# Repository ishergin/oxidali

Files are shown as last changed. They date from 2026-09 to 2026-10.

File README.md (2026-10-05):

# Oxidali

**English** | [Русский](README.RU.md)




Oxidali is a DALI-2 lighting controller: Rust firmware for the Waveshare ESP32-P4-ETH, a 3D-printed
DIN-rail enclosure, and the tooling to build, simulate and test it. The controller
drives one DALI line through its own interrupt-driven PHY. It keeps a registry of
control gear and input devices, and serves a REST and WebSocket API, an embedded web UI
and a Home Assistant bridge. Scheduling covers human-centric lighting (HCL) and a small
rules engine. Two controllers can share one line as an active/standby pair.

Inside the code the project keeps its working name, `dali2rust`: in crate names, the
`DALI2RUST_*` variables and the Home Assistant manufacturer string.

<p align="center">
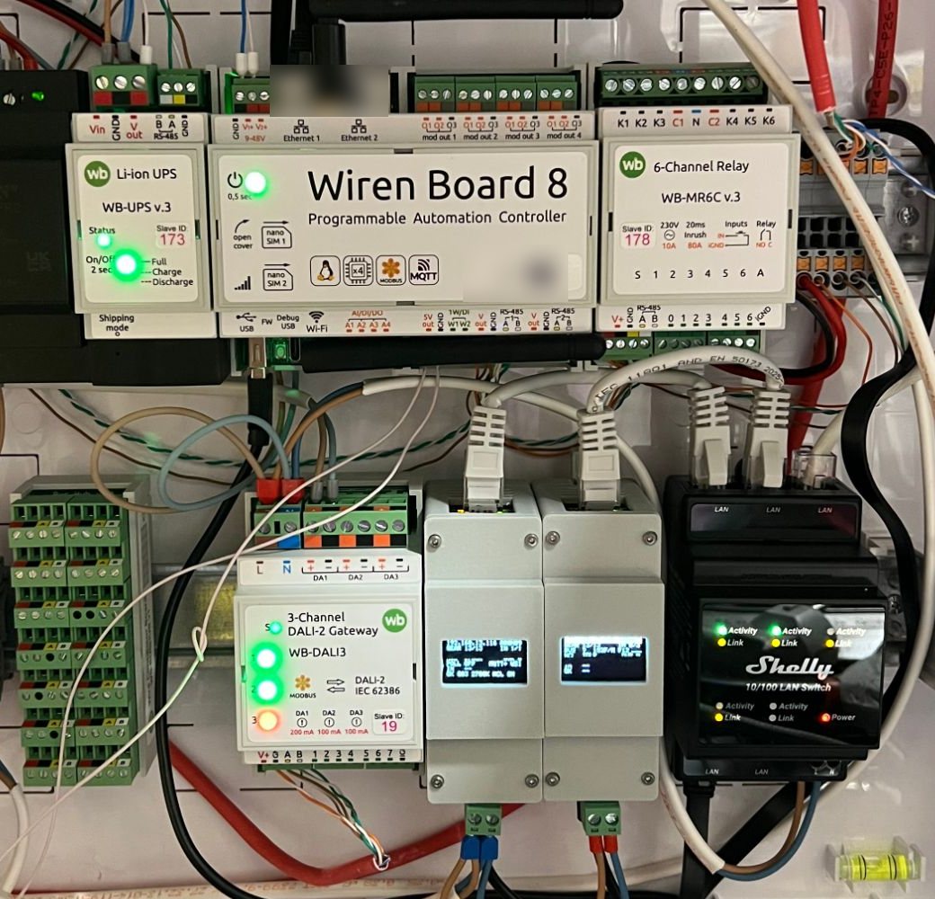
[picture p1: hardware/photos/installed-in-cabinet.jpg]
Two Oxidali controllers, an active/standby pair, on a DIN rail in a distribution cabinet next to a DALI gateway, a Wiren Board controller and a LAN switch
  
  &nbsp;
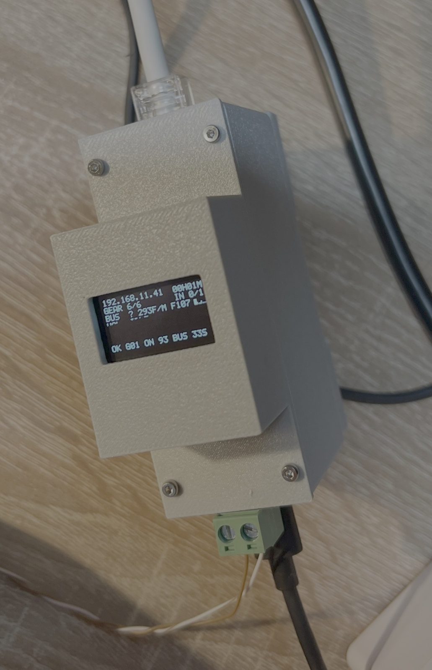
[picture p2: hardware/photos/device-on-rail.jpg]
Close-up of the enclosure with the OLED status screen
  
</p>

## Features

**DALI line**
- Its own PHY: a GPTimer interrupt bit-bangs the line with Manchester coding and
  collision detection. It runs at CLIC level 5 from IRAM only.
- Multi-master aware. The controller shares the line with foreign masters: it
  arbitrates, retries after a collision and treats a contended answer as routine. A
  sniffer decodes foreign frames and keeps the registry in step with them.
- IEC 62386-101 transactions and frame priorities: background reads never delay an
  operator's command.
- Control gear per IEC 62386-102: DT6 LED gear, and DT8 colour gear (colour temperature
  and RGBWAF). Memory bank 0 and the DiiA banks of Parts 251–253 (luminaire data,
  energy, diagnostics) are read.
- Input devices per IEC 62386-103: push buttons (301), absolute inputs (302),
  occupancy sensors (303), light sensors (304) and panel indicators (332). The
  controller receives and types their 24-bit events.
- Commissioning: three scan modes, random addressing, `IDENTIFY DEVICE`, readdressing
  and gear replacement.

**Model and integrations**
- A persistent registry of physical devices, virtual lamps, groups and scenes. Group
  and scene changes are applied as tracked operations.
- A REST API (`/api/v1/*`) and a WebSocket push channel (`/api/v1/ws`). A long job
  answers `202` with an operation id that the client can poll.
- An embedded web UI (Preact + TypeScript) served from flash. Its screens include the
  dashboard, lamps, devices, input devices, groups, scenes, HCL, rules, a bus console,
  a sniffer, logs, operations, statistics, diagnostics, firmware and settings.
- Home Assistant over MQTT discovery: lights, groups, a scene selector and input-device
  events.
- HCL schedules: colour-temperature and level curves, sunrise and sunset, SNTP time and
  time zones, and manual override tracking.
- A rules engine with its own small language. Rules react to input-device events, time
  of day and the sun, lamp, group and scene changes, timers, HTTP calls and MQTT
  messages; they are compiled on the device and can be dry-run.
- Active/standby redundancy. The two units arbitrate roles on the DALI line (DiiA Part
  351) and replicate configuration over HTTP.
- Firmware updates over Ethernet: the controller pulls the image from a URL and rolls
  back if the new image does not prove itself healthy.
- A status screen on an SSD1306 OLED, and runtime counters (DALI, bus, network,
  memory, MQTT, WebSocket) at `/api/v1/stats`.

**Engineering**
- The whole product stack runs on a desktop against a simulated DALI line, through the
  same composition code as the firmware.
- There are unit tests, crate integration tests on the real bus path, and a black-box
  BDD suite of more than 500 cucumber scenarios that drive the host stack over HTTP and
  WebSocket.
- A hardware-in-the-loop toolkit (`tools/hil`) validates the firmware on real boards,
  including optical tests in which a calibrated USB camera checks what each lamp really
  shows ([below](#hardware-in-the-loop-and-bench-instruments)).

## Web UI

The controller serves this UI from its flash. The screenshots come from the host dev
server running the same stack on a simulated line.

<table>
  <tr>
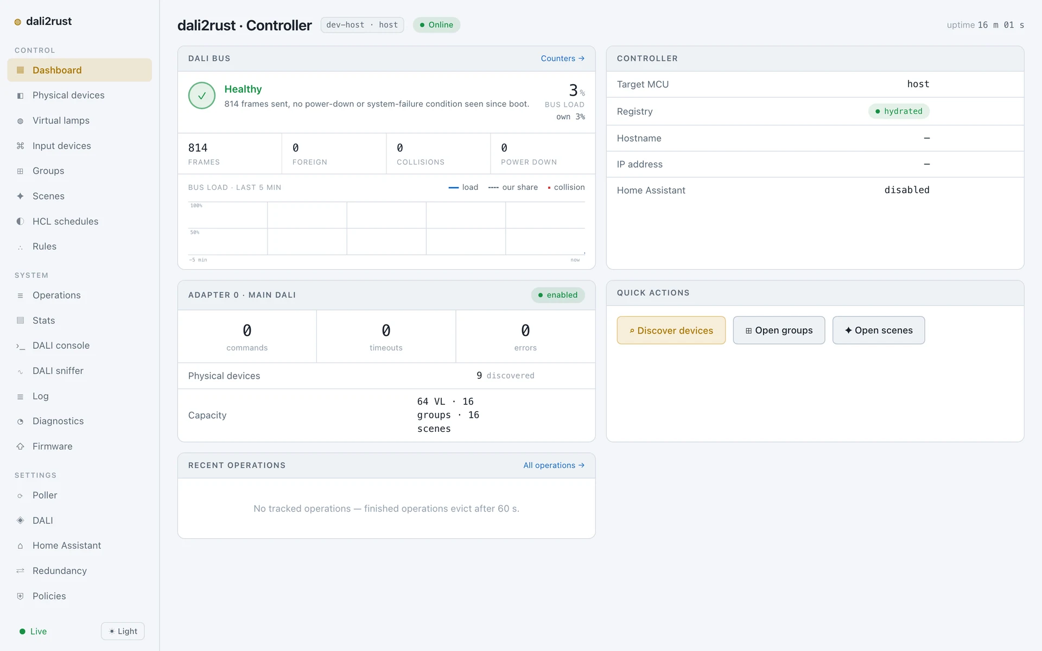
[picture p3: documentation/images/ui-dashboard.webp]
Dashboard with DALI bus health, bus load and adapter counters
    <td width="50%"></td>
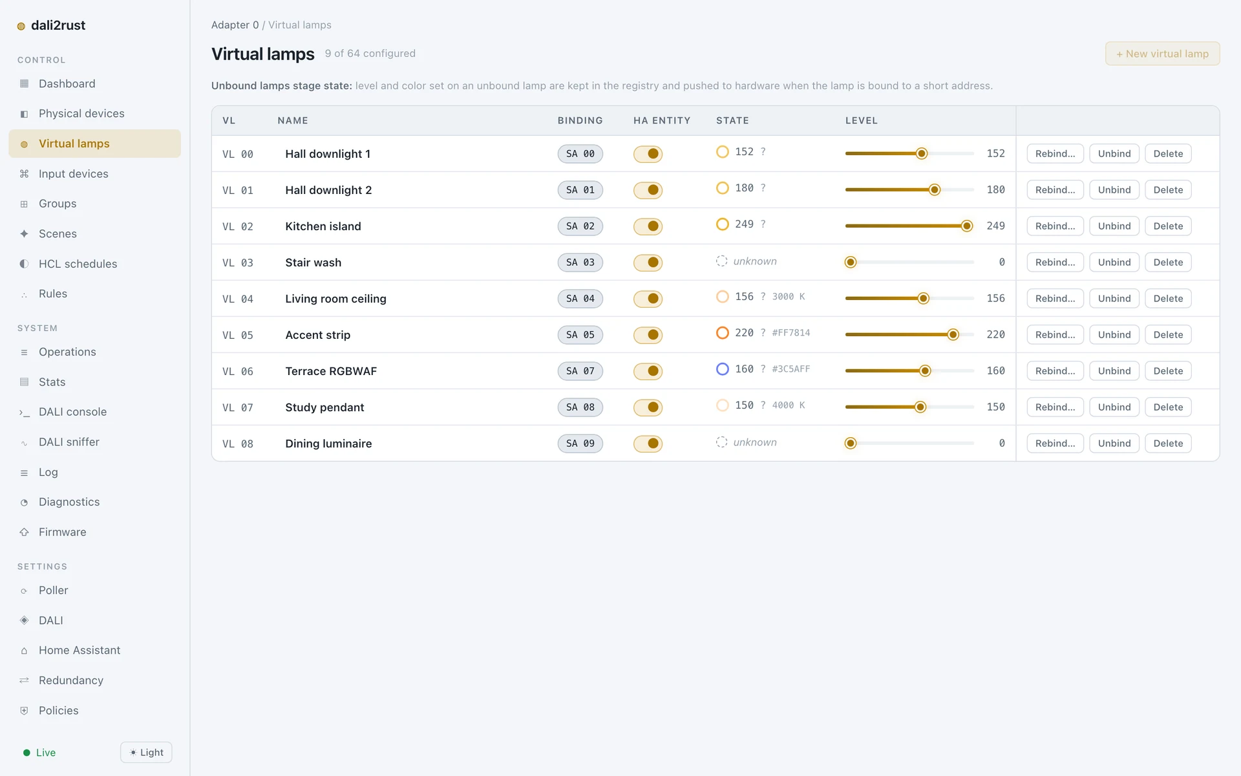
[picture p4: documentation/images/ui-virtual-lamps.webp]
Virtual lamps with live state, level and colour
    <td width="50%"></td>
  </tr>
  <tr>
    <td align="center">Dashboard: bus health, load and counters</td>
    <td align="center">Virtual lamps: live state, level and colour</td>
  </tr>
  <tr>
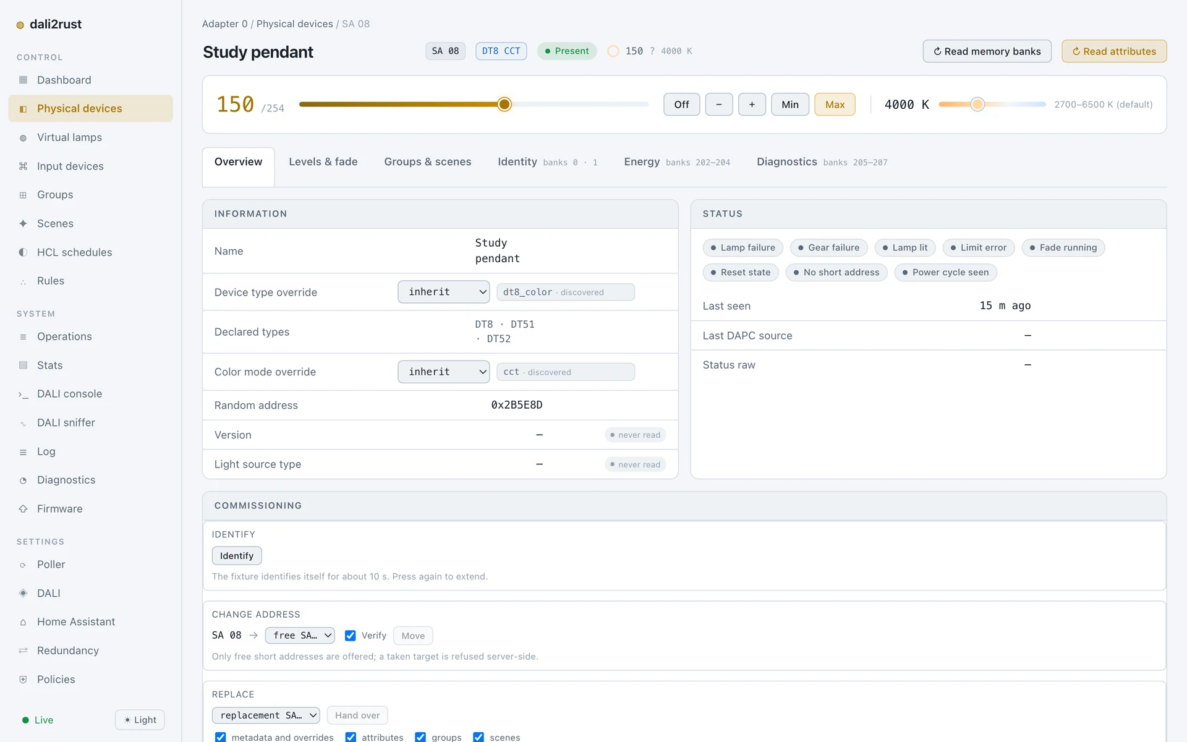
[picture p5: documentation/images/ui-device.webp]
Device card of a DT8 colour-temperature gear
    <td width="50%"></td>
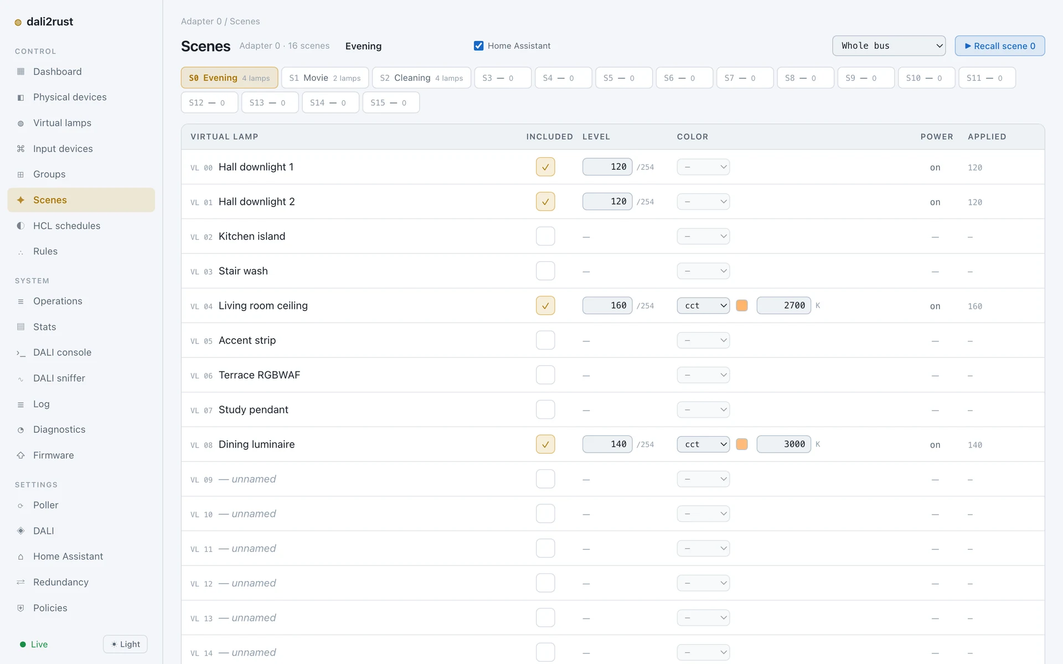
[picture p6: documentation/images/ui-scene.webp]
Scene matrix with per-lamp level and colour temperature
    <td width="50%"></td>
  </tr>
  <tr>
    <td align="center">A device card: DT8 colour temperature, banks, commissioning</td>
    <td align="center">A scene: per-lamp level and colour, desired against applied</td>
  </tr>
  <tr>
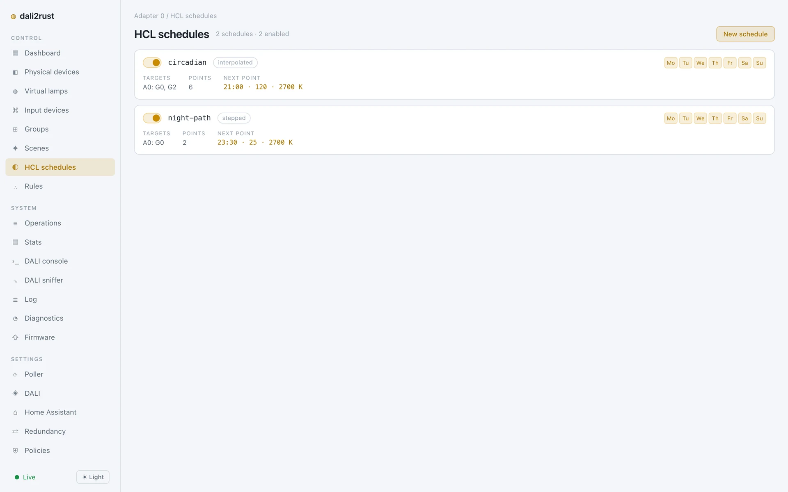
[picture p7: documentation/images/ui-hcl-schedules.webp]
List of HCL schedules with their targets and next point
    <td width="50%"></td>
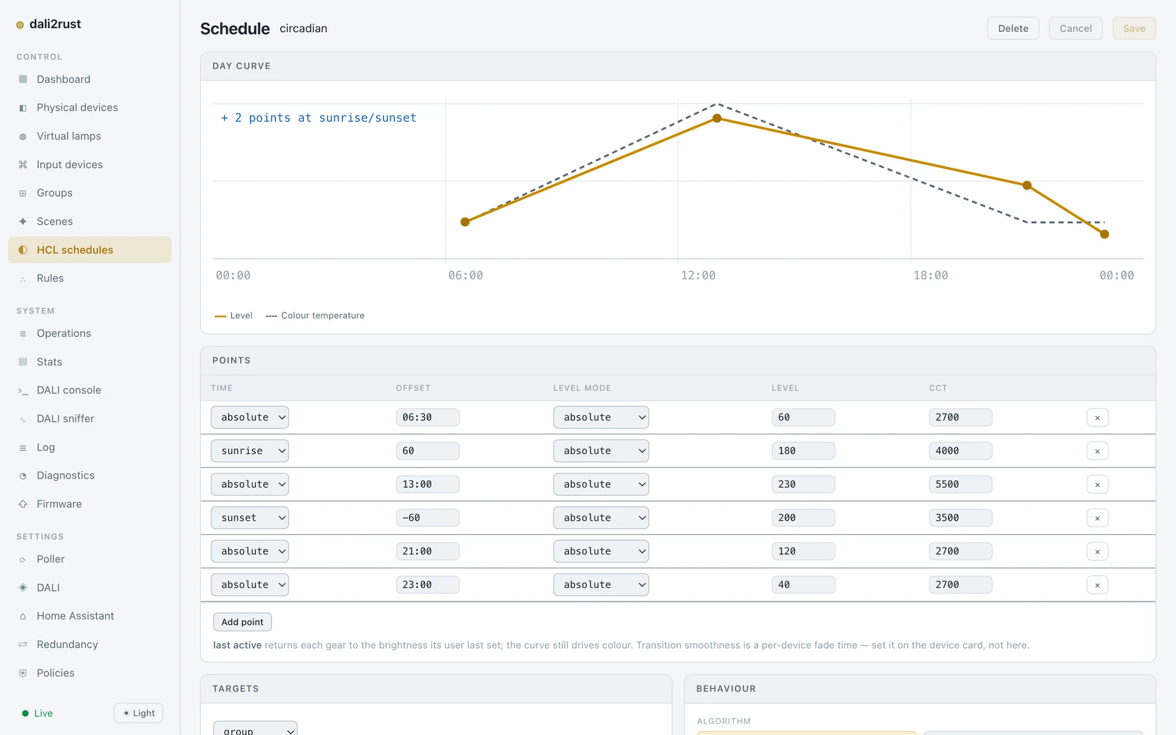
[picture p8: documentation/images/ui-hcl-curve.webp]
HCL day curve of level and colour temperature with its points
    <td width="50%"></td>
  </tr>
  <tr>
    <td align="center">HCL schedules</td>
    <td align="center">An HCL day curve anchored to sunrise and sunset</td>
  </tr>
</table>

## Hardware

| Part | Role |
| --- | --- |
| [Waveshare ESP32-P4-ETH](https://www.waveshare.com/esp32-p4-eth.htm) | Main board: dual-core RISC-V ESP32-P4, 32 MB PSRAM, 32 MB flash, 100 Mbit Ethernet (no radio) |
| Waveshare PoE Module (B) | Optional: powers the board from the Ethernet cable |
| Waveshare Pico-DALI2 | DALI transceiver on the board's Pico-format 2×20 header |
| SSD1306 0.96″ 128×64 I²C OLED | Status screen |
| 2-pole 5.08 mm pluggable terminal block (2EDGV header + 2EDGK plug) | External DALI connector |
| 3D-printed enclosure | Five parts on a TS35 DIN rail |

The line also needs a DALI bus power supply.

| Signal | ESP32-P4 GPIO | Header |
| --- | --- | --- |
| DALI TX (the Pico-DALI2 inverts it) | 14 | pin 9 / Pico GP6 |
| DALI RX | 17 | pin 5 / Pico GP3 |
| DALI high-voltage receive tap (unused, never driven) | 18 | pin 4 / Pico GP2 |
| OLED SDA | 33 | — |
| OLED SCL | 32 | — |

The pin map lives in
[`crates/dali2rust-bsp/src/esp32p4/pins.rs`](crates/dali2rust-bsp/src/esp32p4/pins.rs).

### Enclosure

- FreeCAD model: [`hardware/enclosure/dali2rust-case.FCStd`](hardware/enclosure/dali2rust-case.FCStd),
  driven by a `Params` spreadsheet.
- STEP, STL and 3MF files for each part and for the assembly are in
  [`hardware/enclosure/export/`](hardware/enclosure/export/).
- The body is printed in ABS-GF. The part that carries the DIN-rail catch spring is
  printed in unfilled ABS or ASA.

<table>
  <tr>
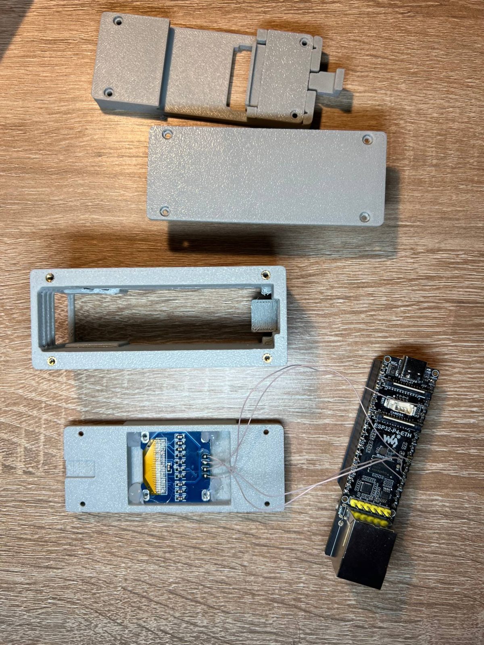
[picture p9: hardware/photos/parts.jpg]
Printed enclosure parts, the OLED in the front cover and the ESP32-P4-ETH
    <td></td>
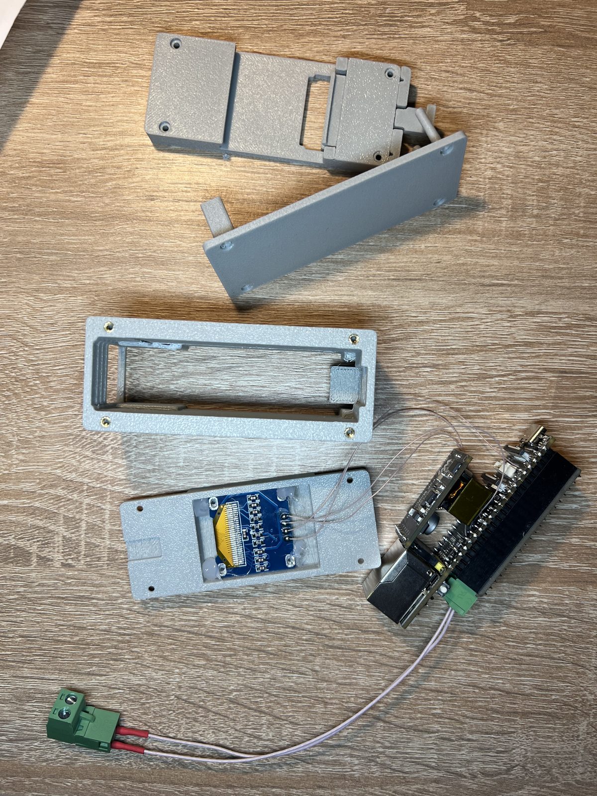
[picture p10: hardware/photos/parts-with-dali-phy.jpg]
Enclosure parts with the Pico-DALI2 mounted under the main board and the DALI plug
    <td></td>
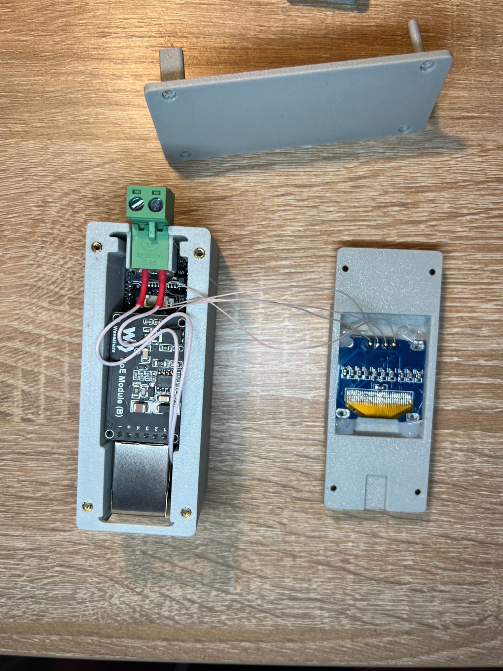
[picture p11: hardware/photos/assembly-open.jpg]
The board stack seated in the body, with the PoE module and the DALI terminal block
    <td></td>
  </tr>
  <tr>
    <td align="center">Printed parts and the main board</td>
    <td align="center">With the Pico-DALI2 and the DALI plug</td>
    <td align="center">Board stack in the body</td>
  </tr>
</table>

## Architecture

### The system

<p align="center">
  System overview: clients on the local network, the Oxidali controller, and the DALI line with gear, input devices, other masters and an optional standby
</p>

### Inside the controller: components and what they do

Everything that wants to change the world publishes a typed command on an in-memory
bus. Exactly one worker owns each command kind: only `DaliWorker` touches the wire, and
only the registry worker writes the registry.

<p align="center">
  Firmware components: ingress modules publish typed commands on a bounded bus; workers own the DALI wire, the registry, operations, state fan-out and the display; the PHY interrupt drives the Pico-DALI2
</p>

### One request, end to end

```mermaid
sequenceDiagram
  autonumber
  participant C as Client
  participant H as HTTP handler
  participant B as Bus
  participant W as DaliWorker
  participant L as DALI line
  participant F as State-fanout projector
  participant R as Registry worker
  participant O as WebSocket / MQTT

  C->>H: PUT /api/v1/adapters/{adapter_id}/virtual-lamps/{lamp_id}/target-state
  H->>H: validate, build a typed command
  H->>B: publish (never blocks)
  B->>W: route to the owner
  W->>L: forward frames inside a transaction
  L-->>W: answer, silence or collision (retried)
  W->>B: applied event + confirmation
  B-->>H: confirmation into the request's slot
  H-->>C: 200 (503 if refused, 504 on timeout)
  B->>F: applied event
  F->>B: runtime update command
  B->>R: commit (the only writer)
  R->>B: runtime-state-changed event
  B->>O: fan-out
  O-->>C: WebSocket frame, MQTT state
```

On the host, the same composition runs over a simulated transport: the BDD suite over
`MockDaliTransport` with scripted answers, the dev server below over `SimDaliTransport`,
a model of real gear. The architecture documents start at
[`documentation/architecture/01-overview.md`](documentation/architecture/01-overview.md),
and the decisions behind them are the [ADRs](documentation/architecture/decisions/README.md).

The system and component drawings are Excalidraw SVGs with the scene embedded: open one at
[excalidraw.com](https://excalidraw.com) to edit it.

## Quick start

macOS on Apple silicon is the tested host. The host triple `aarch64-apple-darwin` is
written into the `justfile` (`default_host`) and the cargo aliases. On another host,
pass `default_host=<triple>` to `just` and put your triple in the `cargo run` commands;
the `cargo bdd` alias keeps the Apple one, so run the suite with `just bdd`.

### Prerequisites

```bash
git clone https://github.com/ishergin/oxidali.git && cd oxidali
# Rust itself: https://rustup.rs
rustup toolchain install    # the nightly and components rust-toolchain.toml pins, host builds included
cargo install ldproxy espflash --locked
brew install just    # or: cargo install just --locked
```

ESP-IDF v5.5.3 and its tools, the libclang bindgen uses among them, are downloaded by
the first firmware build into `.embuild/` and need `git` and Python 3. Node.js 22 is
needed to rebuild the web UI and by the merge gates (`just verify`, `just ci`); the built
UI is committed.

### 1. Run it without hardware

The composed product stack on a simulated line (nine DT6 and DT8 gear and one
unaddressed unit), serving the committed web UI at http://127.0.0.1:8080/:

```bash
DALI2RUST_WEB_DIST_GZ=crates/dali2rust-firmware/assets/web \
  cargo run --target aarch64-apple-darwin -p dali2rust-adapters --example host_dev_server
```

```bash
curl http://127.0.0.1:8080/api/v1/health
```

The server's stdin is a console that plays a foreign master and a wall panel: `press`,
`release`, `foreign`, `occupancy`. Set `DALI2RUST_DEV_SERVER_FLEET=bench` for a full
64-address line. To work on the UI with hot reload, see
[`web/app/README.md`](web/app/README.md):

```bash
cd web/app && npm ci && npm run dev    # http://localhost:5173, proxies /api to :8080
```

### 2. Run the tests

```bash
just check     # type-check every host crate, test targets included
just test      # unit and integration tests
just bdd       # the black-box BDD suite
just ci        # everything a change must pass: clippy, tests, BDD, gates, ESP type-checks
```

`just verify` and `just ci` type-check and test the web UI too, so run
`(cd web/app && npm ci)` once before them.

### 3. Build and flash the firmware

```bash
cargo fw       # build the image for riscv32imafc-esp-espidf
cargo flash    # build, write bootloader + partition table + app over USB, open the monitor
```

Connect the board's USB-C port first. `cargo flash` runs `espflash` with
`partitions-p4.csv`. On the first boot the controller takes an address over DHCP and
shows it on the OLED; open `http://<address>/`. Later updates can go over the network
(Firmware screen, or `POST /api/v1/firmware/updates`).

## Hardware-in-the-loop and bench instruments

[`tools/hil`](tools/hil/README.md) is a pytest suite that drives a real controller on a
real DALI line and checks every effect through an oracle that does not trust the
firmware's own report:

- the controller's REST and WebSocket API and its serial console;
- a second DALI master on the same line (for example a Wiren Board WB-MDALI3) as an
  independent sniffer and a foreign master;
- **optical tests**: a USB camera looks at the lamps, a calibration finds each lamp in
  the frame, and the tests check that every lamp switches on and off, that brightness
  rises strictly with the level, that RGB primaries and 2700 K / 6500 K come out as
  commanded, and that a group recall, a scene, an HCL schedule or a Home Assistant
  command reaches the light itself;
- the second controller of an active/standby pair.

Each tier needs only its own instruments, and the runbook says how to run without each
one. Every session snapshots the controller's configuration and the light and restores
them afterwards. The runbook, with what a bench needs, the configuration and
the first run, is [`tools/hil/README.md`](tools/hil/README.md).

Two more instruments sit beside the toolkit:

- [`tools/dali-gear-sim`](tools/dali-gear-sim/README.md), the **gear emulator**: the
  redundancy pair's second ESP32-P4, borrowed for a session, answers on the shared line
  as a fleet of virtual control gear (DT6, DT8 Tc, DT8 RGB+Tc) while drawing a single
  bus load. Tests drive gear that is nobody's light: target states, groups, scenes, HCL,
  the commissioning search, a poller sweep and a registry near its ceiling. Every boot
  starts with no fleet until the toolkit names the short addresses the real lamps hold,
  and nothing is stored. It runs the shared `dali2rust-gear-model` crate, the same model
  as the host simulator, and the HIL toolkit drives it over its serial console.
- [`tools/dali-arbiter`](tools/dali-arbiter/README.md), the **wire witness**, targets an
  ESP32-C6 with a Pico-DALI2 and is not ported: a receive-only board that records raw
  pulse widths with the RMT peripheral. The firmware cannot judge its own transmit
  timing, so this board compares our frames with a reference master's frames in the
  same capture; `hil/arbiter.py` decodes and scores the captures.

## Roadmap

- **Cluster.** Several controllers act as one system: permitted group commands and
  scene recalls are forwarded between controllers over MQTT, with loop suppression
  ([design](documentation/product-design/runtime-modules/cluster/README.md), in Russian).
- **A Linux service with a Pico DALI endpoint.** The same stack as a Linux daemon (it
  already runs on a host), attached over USB or Ethernet to a DALI coprocessor: an
  RP2350 (Pico 2) with PIO on the Pico-DALI2. The coprocessor keeps bit timing,
  settling windows, collision detection and frame capture; the host keeps the
  application. It also allows a host-based standby, such as a wall panel
  ([ADR-019](documentation/architecture/decisions/ADR-019-standby-dali-endpoint.md)).
- **A DALI-2 push-button.** A bus-powered wall-box input device with two to four
  buttons, RGB feedback per button, NFC tap-to-bind and BLE updates, speaking Parts 103,
  301 and 332; the schematic is being drawn.

## Repository layout

| Path | What it holds |
| --- | --- |
| `crates/` | The Cargo workspace; `dali2rust-firmware` is the only production composition root |
| `tests/dali2rust-bdd/` | The cucumber BDD suite, black-box over HTTP against the composed host stack |
| `web/app/` | The web UI embedded in the firmware |
| `web/design-system/` | A design card for every screen and component |
| `hardware/enclosure/` | The DIN-rail enclosure: the FreeCAD model and its exports |
| `tools/hil/` | The hardware-in-the-loop test toolkit |
| `tools/dali-gear-sim/`, `tools/dali-arbiter/` | The gear emulator (the pair's second ESP32-P4) and the wire witness (ESP32-C6, not ported) |
| `scripts/` | The merge-gate scripts `just verify` runs and their budgets, plus build, release and measurement helpers |
| `documentation/` | Architecture, decision records and the product design |

## Documentation

- [`documentation/README.md`](documentation/README.md) is the map: the as-built
  architecture, the ADRs, and the product design (REST API, bus contracts, runtime
  modules, web UI). The product-design package is written in Russian.
- [`CLAUDE.md`](CLAUDE.md) holds the rules for contributors and coding agents:
  architecture boundaries, threading, testing, contracts and merge gates.
- [`tools/hil/README.md`](tools/hil/README.md) is the bench runbook.

The IEC 62386 standards and DiiA specifications are not included. They are sold by the
IEC and the DALI Alliance.

## Contributing

Changes land through pull requests; how to prepare one, including a web UI change, is in
[`CONTRIBUTING.md`](CONTRIBUTING.md). New behaviour starts with a failing BDD scenario,
and `just ci` must be green before a change lands. The rules are in
[`CLAUDE.md`](CLAUDE.md); the recipes for adding a command, an endpoint or a worker are
in [`11-extension-recipes.md`](documentation/architecture/11-extension-recipes.md).

## License

The software is licensed under either of

- Apache License, Version 2.0 ([`LICENSE-APACHE`](LICENSE-APACHE)), or
- MIT license ([`LICENSE-MIT`](LICENSE-MIT)),

at your option. The hardware design files in [`hardware/`](hardware/) (the enclosure
model and its exports) are licensed
under the CERN Open Hardware Licence Version 2 – Permissive
([`hardware/LICENSE`](hardware/LICENSE)).

Unless you explicitly state otherwise, any contribution intentionally submitted for
inclusion in the work by you, as defined in the Apache-2.0 license, shall be dual
licensed as above, without any additional terms or conditions.

The product-name table in `web/app/public/dali-products.json` ships empty: the DiiA
product database is not redistributed here.

DALI and DALI-2 are trademarks of the DALI Alliance. This project is not affiliated with
the DALI Alliance, and the firmware is not DALI-2 certified.

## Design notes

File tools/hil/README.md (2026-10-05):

# HIL toolkit

pytest-based hardware-in-the-loop tests of the firmware on a real controller and a real
DALI line. The oracles are the controller's HTTP/WebSocket API and serial console, a
second DALI master as an independent bus sniffer and foreign master (for example a Wiren
Board WB-MDALI3 under `wb-mqtt-dali` on `python3-dali`, source in the board's
`/usr/lib/python3/dist-packages/dali/`), and, when one is attached, a USB camera.

Scope: what a bench needs, setting up, running and reading the suite. Strategy, the
coverage map and the watchlist: [STRATEGY.md](STRATEGY.md) (Russian); build knobs and the
version string: [10](../../documentation/architecture/10-build-release-and-tooling.md).

## What a bench needs

| Instrument | Enables | Without it |
| --- | --- | --- |
| A controller running this firmware, reachable over HTTP (`HIL_BASE`) | every tier | nothing runs |
| Its serial console, on this host's USB or behind a serial bridge on another host | `serial`, reboot evidence, `hil monitor`, `hil flash` | `hil preflight` reports it; `serial` tests skip |
| A DALI line with bus power and at least one lamp the suite may drive | every test that changes the light | `HIL_LAMPS_READ_ONLY=1` keeps the light untouched |
| A UVC camera on a fixed mount with the lamps in view | `optical` ([Optical tests](#optical-tests)) | `--no-camera` turns optical tests into skips |
| A second DALI master reachable over ssh and MQTT (WB-MDALI3 on a Wiren Board) | `sniffer`, `foreign`, and `ha_bridge` through its broker | the `sniffer` and `foreign` fixtures skip; deselect `ha_bridge` |
| A second controller on the same line (`HIL_PEER_BASE`) | `redundancy` | those tests are not collected |

macOS is the tested host: camera discovery uses ffmpeg's AVFoundation input, `setup.sh`
builds `uvc-util` with the macOS frameworks, the frame server runs in Terminal. The rest is
Python 3.9+ with the packages of `pyproject.toml` (`setup.sh` installs them) and espflash,
which makes `hil flash`'s images.

## Configuration

Variables are read from the environment when a command starts. `bench.env` (from
`bench.env.example`) holds only the firmware knobs `hil flash` enforces. **The defaults name one particular bench.** Set at
least `HIL_BASE`, the serial variables and the three short-address sets before the first
run: every pytest session that collects a bench test reaches `HIL_BASE`, and
`bench_baseline` suspends that controller's poller for the session; a run that drives
lamps also suspends its HCL schedules (so does a virtual-gear run) and sets its time zone
to `HIL_BENCH_TZ`, a run that drives none leaves both alone. A session whose every test is
[hardware-free](#writing-a-scenario) touches no network and no serial port.

| Variable | Meaning | Default |
| --- | --- | --- |
| `HIL_BASE` | the controller's URL | a reference bench's controller |
| `HIL_SERIAL_REMOTE` | `user@host:/dev/…` of the controller's UART behind a [serial bridge](#serial-ports); empty means this host's USB | a reference bench's Wiren Board |
| `HIL_SERIAL_PORT` | the local serial device when `HIL_SERIAL_REMOTE` is empty | found by scanning |
| `HIL_SERIAL_BAUD`, `HIL_FLASH_BAUD`, `HIL_SERIAL_BRIDGE_PORT` | console baud, esptool baud, the bridge's local port | `115200`, `1500000`, `4444` |
| `HIL_LAMP_SHORTS` | short addresses a test may drive or write (`0,2,3`, `0-3`); the client refuses the rest ([lamp guard](#the-installation-is-production)); empty allows none | empty: the reference bench has no lamp a test may drive |
| `HIL_GEAR_SHORTS` | gear the read tiers target; empty means every gear in the registry | empty |
| `HIL_OPTICAL_SHORTS` | lamps in the camera's view, calibrated and measured; always narrowed to `HIL_LAMP_SHORTS` | `HIL_LAMP_SHORTS` |
| `HIL_LAMPS_READ_ONLY` | on: report the light, never drive it, and the client refuses every visible action; `0` with lamps in `HIL_LAMP_SHORTS` is a run with the owner's go-ahead | on |
| `HIL_NO_CAMERA=1` (`--no-camera`) | optical tests skip instead of failing | off |
| `HIL_CAMERA_NAME`, `HIL_CAMERA_ID` | which camera to open | `USB Camera` |
| `HIL_SKIP_CALIBRATION=1` (`--skip-calibration`), `HIL_CALIBRATION_TTL_S` | reuse the saved calibration; how old it may be | recalibrate; `900` s |
| `HIL_LAMP_ROSTER=registry` | take the lamp roster from the registry's bound virtual lamps | the calibration |
| `HIL_WB_SSH`, `HIL_WB_DEVICE`, `HIL_WB_BUS` | the sniffer host over ssh, its DALI device and bus | a reference bench's Wiren Board |
| `HIL_MQTT_BROKER_HOST`, `HIL_MQTT_BROKER_PORT` | the broker the `ha_bridge` tier uses | a reference bench's Wiren Board, `1883` |
| `HIL_PEER_BASE`, `HIL_PEER_SERIAL_PORT`, `HIL_PEER_SERIAL_REMOTE`, `HIL_PEER_SERIAL_BRIDGE_PORT` | the pair's [second controller](#the-second-controller-hil---peer) | unset, unset, a reference bench's Wiren Board, `4446` |
| `HIL_ALLOW_DESTRUCTIVE=1`, `HIL_POWER_CUT=1`, `HIL_BUS_SHORT=1` | allow the destructive and the person-at-the-rig tests | off |
| `HIL_STATE_GUARD=0` | turn the [save and restore](#save-and-restore) guard off | on |
| `HIL_BENCH_TZ` | the time zone `bench_baseline` holds the controller in during a run that drives lamps | a reference bench's zone |
| `HIL_VIRTUAL_GEAR=1` | run the [virtual-gear](#virtual-gear) tier on the gear the peer emulates | off |
| `HIL_VIRTUAL_PARK` | the emulated park's shape: DT6, DT8 Tc and DT8 RGB+Tc gear, built in that order on the first free addresses above the reserve | `4,4,4` |
| `HIL_OWNER_SHORTS` | live lamps a scan cannot see (unpowered), added to the virtual-gear reserve | empty |
| `HIL_ALLOW_VIRTUAL_COMMISSIONING=1` | let the virtual-gear tier commission emulated gear (a go-ahead per run) | off |
| `HIL_ALLOW_RULE_COMMITS=1` | select the tests that commit the rules document (`rules_guard`; a go-ahead per run, STRATEGY §4) | off |
| `HIL_ADAPTER`, `HIL_BOARD`, `HIL_RUN_DIR` | the DALI adapter id, the board, the artifact directory | `0`, `esp32p4`, `runs/current` |

## First run

```bash
tools/hil/setup.sh                                   # .venv, the hil package, uvc-util
cp tools/hil/bench.env.example tools/hil/bench.env   # firmware knobs `hil flash` enforces
cd tools/hil
export HIL_BASE=http://<controller> HIL_SERIAL_REMOTE= HIL_SERIAL_PORT=<device>
export HIL_LAMP_SHORTS=<lamps> HIL_GEAR_SHORTS=<gear> HIL_OPTICAL_SHORTS=<lamps in view>
.venv/bin/hil preflight                              # read-only readiness check
.venv/bin/python3 -m pytest -m smoke --no-camera     # the instruments themselves
.venv/bin/python3 -m pytest --no-camera \
  -m "not destructive and not slow and not sniffer and not foreign and not ha_bridge and not redundancy"
```

Drop `--no-camera` and the markers of instruments the bench has. The toolkit's unit tests
need no hardware; `HIL_BASE` on a closed port keeps a regressed hook off any bench:

```bash
HIL_BASE=http://127.0.0.1:9 HIL_SERIAL_REMOTE= HIL_NO_CAMERA=1 \
  .venv/bin/python3 -m pytest tests/*_unit.py                                           # tools/hil
```

## The installation is production

The suite runs on production lighting ([STRATEGY.md](STRATEGY.md) §2) under the standing
rules of STRATEGY §4. `HIL_LAMP_SHORTS` names the lamps a test may drive; set
`HIL_GEAR_SHORTS` on every run — empty, the default, means every gear in the registry.

The lamp guard (`hil/lamp_guard.py`) enforces `HIL_LAMP_SHORTS` and
`HIL_LAMPS_READ_ONLY`, whatever a test or a script selects. Every request
`Client` sends and every frame of the WB foreign master passes it first, and a refusal
raises `LampNotAllowed`, naming its cause, before anything reaches the wire; during a
bench test's setup or run it is reported as a skip that quotes it:

- A target-state, identify or attribute write, or a diagnostic frame that writes the gear,
  must address a short in `HIL_LAMP_SHORTS`; queries always pass. An extended command is
  read by the last `ENABLE DEVICE TYPE` the client sent (`dali/raw`, the WB master; with
  none, an unknown write) or the one the firmware sends itself (`dali/command`). A virtual
  lamp whose binding cannot be read, or an identify naming no short, is refused.
- A group or broadcast frame, a group target-state, a scene recall, a policy apply and a
  scan while apply-on-discovery is armed pass only when every present gear on the segment
  is in `HIL_LAMP_SHORTS`.
- Under `HIL_LAMPS_READ_ONLY=1` every visible action is refused: target-state, identify,
  scene recall, and every frame or attribute write that changes what a lit lamp shows
  (`VISIBLE_*` in `hil/lamp_guard.py`; a new level or Tc limit moves a lit lamp into
  range). Other configuration writes to an allowed lamp still pass (STRATEGY §4). No
  restart or handover passes either — a reboot (`Client.expect_reboot`), firmware update,
  switchover, `application_active` or `settings/redundancy` write: the unit active
  afterwards republishes its HCL point over a lamp set by hand. A destructive run needs
  `HIL_LAMPS_READ_ONLY=0`.
- A `/api/v1/dali/*` body with no frame the guard can read is refused, and so is a write
  whose path the client or the firmware would respell: `%` (bar an encoded rule name),
  `#`, `+`, an empty or dot segment. A control-device forget and a slice import always
  fail; a device forget writes its short and, like a virtual-lamp delete, never passes
  read-only outside the [virtual-gear](#virtual-gear) teardown.
- Commissioning is refused — the steps, address changes, replacements, a
  `commission_unaddressed` run, the input-device commission and every special frame but
  TERMINATE, DTR0–2, PING and `ENABLE DEVICE TYPE` — except by the virtual tier's fence
  with `HIL_ALLOW_VIRTUAL_COMMISSIONING=1`.
- A group or scene apply passes only when every virtual lamp whose row it writes is bound
  to a lamp of `HIL_LAMP_SHORTS`, and never under read-only.
- A 24-bit frame from the WB master is refused under read-only, since a forged input event
  reaches automations the toolkit cannot see, when an
  enabled owner rule could fire on its event, and when it is a command.
- HCL schedules, rules and MQTT commands drive lamps past the guard, so a test using them
  asks it first (`drive_allowed`, `allowed_bound_lamp`) for each lamp reached — the whole
  segment for a broadcast, the HA scene select or any group but `free_group` (no registered
  gear or owner rule uses it, no group query answers, only the test's lamps join).
- Every `light` test first skips when any rule of the document, enabled or not, names its
  lamps, their virtual lamps or their groups. `clock_guard` moves the controller's clock
  only when a test calls it, never at setup, and each call skips the test under read-only
  or while an owner rule fires at a time of day or at the sun. With the go-ahead too, a
  restart or handover is refused while an owner rule fires when a controller starts or
  becomes active.

A run with no `HIL_*` flag writes only this, each put back by its test or guard: the
adapter's name; group 15's and a scene's name and Home Assistant exposure (HIL-GRP-03,
HIL-SCN-03); the Home Assistant bridge's settings, moved to `hiltest` (the owner's
entities are unavailable meanwhile), and a virtual lamp's exposure (`ha_guard`); the poller's settings (`test_poller`, `poller_guard`); and the owner's
poller and armed apply-on-discovery, off for the session (`bench_baseline`). HIL-INP-02 and
03 rewrite the panel's instance group membership with the value it holds; scans refresh the
registry.

## Save and restore

The session-scoped autouse fixture `production_state` (`hil/prod_state.py`) runs
for every session that reaches the controller:

- **Before** anything else it primes the registry with an attribute read of every
  gear (runtime state is unknown after a reboot) and snapshots the controller's and
  gear's configuration (the fields it names, below) and what every lamp shows.
- **During** the session every request `Client` sends and every frame of the WB master
  is noted, by resource and patched field, in a write log next to the snapshot; an MQTT
  command, a forged input event, a rule run, a schedule, clock or role change and a
  reboot count as moving any lamp.
- **After** it each layer writes back only what that log names (a refused one is logged
  and the next goes on); it re-reads every gear
  before putting the light back and diffs against the snapshot. What the toolkit wrote and
  could not put back prints `PRODUCTION STATE NOT RESTORED`, turns the run red and keeps
  the session open; a change someone else made is printed as such and left.
- It cannot restore the colour a DT8 gear stored with a scene, a last active level, or
  anything outside the controller (the Wiren Board, Home Assistant).
- It restores the rules document only where the difference is whole blocks of rules
  named `hil-…`, against the revision it read, so an owner's edit stays and is reported;
  while the owner's delayed actions are pending (STRATEGY §4.9) it leaves the test rules in
  place, switched off, and says so. A commit resets toggles to the text, so it puts back
  those the commit changed; any other toggle that differs from the snapshot is reported —
  a residual when the session's log names it, otherwise someone else's change.
- Each session keeps `state/production_state-<time>.json` and its `.writes.json`
  (`production_state_last.json`: the latest snapshot). `hil state restore` finishes a
  left virtual-gear session ([Virtual gear](#virtual-gear)), then restores every open
  session, newest first, through its own log; without a log it only reports, and `--all`
  writes the whole snapshot back — under read-only never a schedule, override or zone. A
  session closes only when no newer open session's log names what it wrote, and a FILE is
  refused while a newer session is open. An unreadable session file or log, or one of
  another controller, is named and its session left open, and the command exits non-zero
  while a session is open. Every later session ends red until then.
- Under `HIL_LAMPS_READ_ONLY=1` the light is reported, never driven — by this
  fixture, `state_snapshot` and `hil state restore`. A lamp outside
  `HIL_LAMP_SHORTS` is never driven back, and the lamp guard refuses a repair of its
  gear groups and scenes: a difference there stays a residual. So does the light of a lamp
  the log names, keeping the session open until a restore with `HIL_LAMPS_READ_ONLY=0` and
  it in `HIL_LAMP_SHORTS`.
- Across several tiers `hil state diff` the first session's file at the end.
  `HIL_STATE_GUARD=0` is the only opt-out.
- It compares and restores only the fields it names (the poller's and Home Assistant's
  `RESTORABLE` tuples, `prod_state`'s settings, gear-configuration and device-record
  lists), and so do the settings guards: a writable field the firmware adds is named
  there too, or a test that changes it leaks past the session with no residual.
- Fields an enabled HCL schedule drives (level, colour or both, on its targets'
  members) are neither compared nor restored: the schedule moves them during a session,
  and writing one back is an API write the scheduler takes as an override.
- Part 103 control devices are neither snapshotted nor restored — their configuration
  lives in the panel's NVM — so a test writes a panel field only with the value the
  panel already holds.
- A request that can move a lamp through `/api/v1/dali/*` goes through `Client._http`
  (never `raw_response` or a bare session), which books the shorts it touches so
  `restore_states` re-reads them before comparing; `raw_response` passes the lamp
  guard but books nothing.
- A session fixture that changes the installation takes `production_state` as a
  parameter, used or not: only that dependency orders it after the snapshot.

Per-test guards (`state_snapshot`, `*_matrix_guard`, `hcl_guard`, …) restore what one test
changed; `bench_baseline` fails the session on a device still named `hil-…`.

## Layout

| Path | Holds |
| --- | --- |
| `hil/` | the library and the `hil` CLI |
| `tests/` | the suites; `conftest.py` lists the `hil_*.py` plugins that hold the fixtures and the safety gates, one per domain (session hooks, instruments, session and per-test guards, optics, run validity, the virtual-gear session) |
| `wb/serial_bridge.py` | the serial bridge, copied to the Wiren Board's `/mnt/data/dali2rust/`, where `hil flash --via wb\|ota` also stages images and `--via wb` its esptool |
| `corpus/` | frozen captures of the installation (`hil corpus`); local, and only the files host tests pin are tracked (`.gitignore`) |
| `*_budget.txt` | run-validity budgets (below) |
| `state/`, `runs/<ts>/` | gitignored bench state (calibration, monitor, serial log, pins, snapshots) and per-run artifacts; `runs/current` is the latest |

`state/` belongs to the checkout: a monitor started from another worktree is unseen here,
and a flash from here then fights it for the port.

## Optical tests

The camera is the oracle for what a lamp really shows.
The `optical` tests (`test_optical_*`, and the optical cases in `test_scenes`,
`test_scenarios`, `test_hcl_runtime` and `test_ha_bridge`) check on the fixtures on and
off, a strict brightness ladder, RGB hue, colour-only lighting, CCT order, and a group
recall, scene, HCL level and MQTT colour reaching them.

The camera is a UVC camera on a fixed mount with the lamps or their patches in view. `setup.sh` builds `uvc-util`, which locks exposure and white balance. macOS
denies an agent the camera, so frames come from a frame server (`hil camera-server
--spawn-terminal`, approve it in the Terminal). Exactly one may run, and
`--spawn-terminal` leaves a live one as it is. A server that is alive but serves no
frames holds a camera AVFoundation no longer hands it: run `vendor/uvc-util/uvc-util
-d`, which enumerates the device again, then `hil camera-server --restart`.

Calibration (`hil calibrate`, or before the first test that needs optics)
locks the camera, takes all-off baselines for the noise floor, finds each lamp's mask,
tunes the exposure against clipping, measures crosstalk and a brightness ladder, records
colour fingerprints and picks fiducials that reveal a camera that moved. The profile is
saved in `state/`; a session calibrates anew, and again before a test once the profile is
older than `HIL_CALIBRATION_TTL_S`, unless `--skip-calibration` reuses the saved one.
**Calibration drives every lamp in `HIL_OPTICAL_SHORTS`**, so it is a visible action.

A dead optical channel **fails** optical tests; `--no-camera` / `HIL_NO_CAMERA=1` turns
that into skips.

## Running tests

Always from `tools/hil/` (`testpaths` and `addopts` are relative):
`.venv/bin/python3 -m pytest …`. `just hil-preflight | hil-smoke | hil-default |
hil-slow` wrap the cwd.

- The default run excludes `destructive` and `slow`. An explicit `-m` **replaces**
  that filter (pytest keeps the last `-m`), so the destructive tier is also gated by
  `HIL_ALLOW_DESTRUCTIVE=1`: without it those tests skip whatever `-m` says, and with it
  a session selecting two is a usage error. Every
  test that reboots or halts a controller is `destructive`: collection refuses one
  that requests `dut_reboot` or calls `remote_serial.control` (itself or through a
  helper in its module) without the marker.
- The tiers, their order and what each is for: STRATEGY §5. Add
  `--junitxml=runs/current/junit.xml --html=runs/current/report.html` for reports.
- `hil preflight` judges the serial channel by the log growing after a health request
  and the smoke tier by the firmware's `HTTP access: GET /api/v1/health …` line, so that
  line is part of the firmware's contract with the toolkit.
- Markers: `smoke`, `optical`, `sniffer`, `serial`, `foreign` (the WB master),
  `ha_bridge`, `redundancy`, `slow`, `destructive`, `needs_capability(name)`,
  `virtual_gear` (the gear the peer emulates), `light` (can change what a lamp shows).
- Whatever `-m` says, collection deselects a `light` test unless `HIL_LAMP_SHORTS` names
  a lamp and `HIL_LAMPS_READ_ONLY=0`, and a test that commits the rules document
  (it requests `rules_guard`) unless `HIL_ALLOW_RULE_COMMITS=1`.
- `--fast-fade` sets the fade time of every lamp in `HIL_LAMP_SHORTS` to 0 after
  `production_state` has taken its snapshot, and `production_state` restores it at
  the end of the session; with `HIL_STATE_GUARD=0` the option is a usage error.
- Person-at-the-rig tests skip unless asked for: `HIL_POWER_CUT=1` (cut the
  controller's power mid-write), `HIL_BUS_SHORT=1` (short the bus; every lamp sees it).
- The `ha_bridge` tier uses the WB's mosquitto under `hiltest*` prefixes; `ha_guard`
  restores the live settings and sweeps the test topics, never touching
  `broker_password`. Acceptance against the live Home Assistant is manual.
- Artifacts land in `runs/<ts>/<test-id>/`.

## Run validity — how a red run is classified

Every run ends with an `HIL validity` section (also in `runs/<ts>/summary.md`): frame
servers (more than one is flagged; `hil preflight` fails on it), DUT uptime continuity
(a reboot fails the test it
landed in, unless that test uses `dut_reboot`), the baseline and the gear-segment
restriction (a restricted run is *not an acceptance run*), the peer and its uptime
from session start to end (a reboot, or a peer that stops answering, fails the run),
the production-state result, WB availability, the retry ledger, the controller's bus
drop counters, per-task stack headroom (a run whose log has no census says so; a
budget line no census task matches fails the run unless the task is spawned on
demand; the trend compares runs of one image, named by the version `/api/v1/health`
reports, so an image written over the network starts a new one), the boot heap
ladder and the runtime heap floor. **Classify a red run from this section, not from the serial log.**

| File | Bounds | Moves |
| --- | --- | --- |
| `retry_budget.txt` | what a session may absorb | down only |
| `stack_budget.txt` | how deep each firmware task may go | down only |
| `boot_heap_budget.txt` | internal SRAM left at each boot stage | up only (a floor) |
| `runtime_heap_budget.txt` | internal SRAM minimum since boot, read from `/api/v1/stats` at session end | up only (a floor) |

A budget moves against its direction only with the justifying measurement in the
commit. `-1` means "never measured with a counter attached": reported, not gated — replace
it with the first instrumented figure. A `watched` row counts what a workaround changed — a
re-read that disagreed with the first answer, a repair spent after a wrong one — and has
no budget line: it never gates, and the workaround goes once it stays at zero. A retry is
counted, never silent; a dead instrument (blind colour sample) charges no budget.
A red test keeps its strict assert
([05](../../documentation/architecture/05-testing-and-bdd.md)); the budget carries the
rate the installation imposes.

## CLI (`.venv/bin/hil`)

| Command | Purpose |
| --- | --- |
| `preflight` | read-only readiness: DUT HTTP, serial bridge, monitor, WB ssh, broker, camera, calibration, host tools |
| `monitor start\|stop\|status\|tail` | persistent serial monitor; `start` raises the bridge if needed |
| `remote start [--restart]\|stop\|status\|ping\|bootloader\|run\|release\|reacquire` | the WB serial bridge and its tunnel |
| `flash [--build-only] [--allow-nonbench-build] [--allow-red-isr] [--allow-stale-ui] [--via rfc2217\|wb\|ota]` | the only flash path (below) |
| `--peer role gear-sim [--via ota\|wb]\|controller [--via ota\|wb]\|status` | lend the peer to the gear emulator and take it back (below) |
| `state save\|restore [--all\|--retire FILE]\|diff [FILE]` | the installation snapshot; `--retire FILE` closes a session that never closes once every older open one's logged fields hold their snapshot; never delete an older session file by hand while a newer one is open |
| `api <sub> …` | manual API calls; exit 2 means the firmware lacks the capability |
| `corpus [parts…]` | freeze both boards' configuration, REST, wire replies and serial evidence into `corpus/`; slices in `SECRET_SLICES` (the Home Assistant slice carries the broker password) are withheld unless `--keep-secrets` writes into an `--out` outside every git work tree — a slice that comes to carry a secret joins that list, because a pinned file gets committed |
| `calibrate`, `camera-server`, `camera-bench`, `lamps [--no-baseline]` | optics; `lamps` switches every calibrated lamp **off** for its baseline unless `--no-baseline` |
| `decode <log>` | decode a sniffer capture |

`hil --peer <command>` runs any of them against the other controller; `--peer` goes
before the command. Every command parses its arguments strictly: an unknown or
misspelt flag (`--peer` after the command included), an unknown subcommand or a stray
argument exits 64 before anything runs. `hil api`'s exit 2 keeps its meaning.

## Serial ports

A board on this host's USB needs only `HIL_SERIAL_REMOTE=` (empty) and, to pin it,
`HIL_SERIAL_PORT`. On a reference bench both controllers hang off a Wiren Board's USB
instead, named by USB serial number under `/dev/serial/by-id/`;
`HIL_SERIAL_REMOTE` and `HIL_PEER_SERIAL_REMOTE` name them. `wb/serial_bridge.py`
(pyserial only) holds each UART open for life behind two loopback listeners: data, in
RFC2217 so esptool's baud change reaches the UART, and one port above it, control: `ping`, `status`, `bootloader`, `run`, and for a write on the WB itself `release`,
`reacquire` and `write <line>` (a line to the board's console); `status` lists the last
three. An ssh tunnel brings them here: the
primary is `rfc2217://127.0.0.1:4444`, the peer `…:4446`. The limitations of the USB
bridge, pyserial and esptool this set-up works around are
[ISSUE-148](../../documentation/product-design/known-issues.md).

- The bridge serves **one client** and refuses a second rather than evicting the
  first.
- Attaching to a live bridge resets nothing. **Starting a bridge that is down resets
  the controller.** `hil remote start`, `hil monitor
  start` and `hil flash` all start it when needed (`--restart` always does); first
  check on the WB whether it still listens (`ss -ltn`) — if only the tunnel died,
  the start reuses it. A changed `wb/serial_bridge.py` is copied to the WB but a live
  bridge keeps running the old one until `--restart`, which resets the controller.
- A bridge whose port is gone (node vanished, board enumerated again, a read failed)
  answers every control command `err port-gone: …`. `hil remote`, `hil monitor start`, `hil flash` and
  `hil preflight` fail on it instead of reusing a bridge that carries no data;
  `--restart` reopens the port and so resets the controller, which is the operator's
  decision.
- Reset sequences run on the WB.
- Logs: `state/persist/serial.log` (peer: `state/peer/persist/`), lines stamped in UTC
  (`…Z`) like `runs/<ts>`.

## Flashing

`hil flash` is the only way to flash the installation (`cargo flash` and `just
p4-fw-flash` open a local port). It refuses a build without the
`bench.env` knobs and a stale embedded UI bundle (`--allow-stale-ui` builds with the
previous one), runs the ISR-IRAM gate on the linked binary (refusing exit 1, red, and
an unchecked 2, a tool — sought in `.embuild/espressif/tools`, then `~/.espressif` — or the
ELF missing, or 3, no entry point or section found; an entry outside IRAM is red),
records `runs/<ts>/manifest.json` (commit, binary sha, knobs, checks), resets the
chip into its ROM loader through the bridge, writes with esptool at
`HIL_FLASH_BAUD`, always asks for `run` afterwards (a board left in the loader looks
bricked from the LAN), waits for `/api/v1/health` and requires the reported version
to equal the one inside the image it wrote — a prefix-of-`HEAD` check only when the
image yields none — and records that version in the manifest. `MCU` and the sdkconfig
baseline are read from `.cargo/config.toml` and asserted, never set. Off the WB's LAN
esptool over the bridge never syncs: use `--via wb|ota`.

`bench.env` overrides the shell's exports, so a one-off `KNOB=… hil flash` applies only
when `bench.env` does not set it.

**Delivery** — `hil flash --via rfc2217|wb|ota` picks it; what only the wire can do is in
[ADR-024](../../documentation/architecture/decisions/ADR-024-ota-over-ethernet.md).

- `wb` stages the merged image on the Wiren Board, checks its sha256 and writes it with a
  vendored esptool on the board's own serial device at 921 600 baud, detached from the ssh
  session: its exit code comes back through a file, so the host's link to it does not
  decide whether the write lands. The bridge releases the port for the write and
  reacquires it after, which is the one reset; a bridge that cannot release is refused
  before any reset (`hil remote start --restart` runs the current one, and resets the board).
- Before a `wb` write, the board the port names must fall quiet in its ROM loader while the
  other board keeps its uptime. With neither witness the write is refused, and any failure
  before esptool starts sends `run`.
- `ota` builds the application image instead of the merged one, serves it from the Wiren
  Board, posts it to `/api/v1/firmware/updates` and waits for `ready_to_reboot`, with the
  gates, manifest and version check above. It does not wait for `pending_verify` to clear,
  and until then a reset boots the previous slot
  ([contract](../../documentation/product-design/rest-api/resources/firmware.md)).
- `rfc2217` (default): esptool over the bridge above, or espflash on this host's USB.

The gear emulator's image goes only through `hil --peer role gear-sim` (below).

## The second controller (`hil --peer`)

`hil --peer <command>` points the toolkit at the pair's other board: its URL
(`HIL_PEER_BASE`, or the lease its firmware announces on serial, learned by the first
`hil --peer flash` into `state/peer/base.pin`), its bridge, its own `state/peer/` and
`runs/peer/`. The
`redundancy` tier is collected only when `HIL_PEER_BASE` names the peer; preflight, the
run-validity peer check, the hand-back below, the gear emulator, `hil corpus` and the
`--via wb` witness also find it through the pin. A reboot the suite provokes leaves the
peer active and the rebooted board standby; `dut_reboot` and the OTA test hand the role
back (`hil/pair.py`) before the next assertion.

`hil --peer role gear-sim [--via ota|wb] | controller | status` lends the peer to the gear
emulator and takes it back ([ADR-031](../../documentation/architecture/decisions/ADR-031-gear-emulator-on-the-standby.md)):

- **`--via ota`** (the default) installs the emulator in the peer's inactive slot for one
  boot. The ready line must say `pending_verify`, and any reset hands the controller back.
- **`--via wb`** writes it by wire, and the role survives resets.

The peer must be the standby, its monitor must run before the switch (starting a bridge that
is down resets the board), no other flasher may run here or on the WB, and no virtual-gear
ledger may be open. The emulator's image is built with [`tools/dali-gear-sim`](../dali-gear-sim/README.md),
merged with the controller's bootloader, and checked by its ready line; the console prints it
again on `ready`, so a monitor that missed the boot still reads it.

`state/peer/role.pin` records the role once the image is delivered (`confirmed: false`
until the ready line checks out). `role controller` refuses while a ledger is open or the
peer's bridge is the DUT's, and asks the board itself:

- a peer that answers as a controller is only recorded;
- otherwise the emulator is asked for its ready line through the peer's bridge, which proves
  the board that bridge resets. `pending_verify` resets it, while the DUT's uptime witnesses
  that the reset did not reach the DUT; anything else writes the controller back by wire,
  building with the committed UI bundle even when it is stale;
- a peer that answers neither needs `--via`, which also overrides the ready line.

Then, once the DUT's slices match, a standby whose registry still holds entries they
dropped is reset once, witnessed the same way. Preflight, the virtual-gear session and the
run-validity report read the pin.

## Virtual gear

`HIL_VIRTUAL_GEAR=1 .venv/bin/python3 -m pytest --no-camera` runs the tests marked
`virtual_gear` — and only those — on the gear the peer emulates, on the installation's wire.
Its rules are STRATEGY §4.8; the mechanics:

1. **Before any config loads**, the plugin (`tests/hil_virtual.py`) reads the reserve and
   sets `HIL_LAMP_SHORTS`, `HIL_GEAR_SHORTS` and `HIL_OPTICAL_SHORTS` to the park, so every
   selector follows it.
2. **After the owner's installation is snapshotted** (without the snapshot the session
   refuses), `hil/virtual_gear.py` opens the session:
   - proves the free groups silent against a positive control;
   - checks that no owner rule, compiled or in text, names a free group, a session lamp
     (by id or name) or a park device;
   - gives the emulator the reserve, checks the mask it echoes, builds the fleet and enables
     it on a ladder once the first gear has answered the controller cleanly and the
     emulator's answer counters moved without a late or expired answer;
   - hides the free groups from Home Assistant;
   - scans, reads each park gear's identity bank (a GTIN not the emulator's refuses the
     session), and binds the park to new virtual lamps with HA off, writing each lamp's id
     to the ledger before creating it.
3. **During the session**, the fence on the tests' client (`lamp_guard.VirtualFence`) passes
   only the routes and frames STRATEGY §4.8 lists. After every test the tripwire waits for
   the DUT's log to fall quiet, sends the barrier and judges the test's `DALI PHY TX` lines
   with the same fence.
4. **The teardown follows** `state/virtual_gear.json`, step by step:
   - silence the fleet;
   - delete the session's lamps still named for their park address and forget the park —
     the guard passes these only here, a forget only above 15, outside the reserve, of a
     record with the emulator's GTIN;
   - restore group flags;
   - compare the registry, the WB list and the retained MQTT topics with the start.

   A teardown that leaves residue keeps the ledger: the next session and `hil --peer role
   controller` refuse until `hil state restore` finishes it. Check a park record it may not
   forget (no emulator GTIN) by hand; if emulated, `curl -X DELETE` its
   `/api/v1/adapters/0/physical-devices/<short>`, which ends the residue.

The session exits 3 when it cannot open, 4 on a `SAFETY` stop, 5 when the peer came back
as a controller, 6 when the tripwire went blind. The emulator
takes one reserve per boot: a later session on the same boot proceeds with the same reserve,
and another reserve needs the emulator restarted — under the OTA role that returns the
controller.

The oracle is the emulator's `C` lines (`hil/gearsim.py`: `GearOracle.expect`,
`untouched`) and, inside `GearOracle.hearing()`, the `F` lines of frames it heard, which
vouch for the wire only when every frame the DUT logged as sent there is among them
(`gearsim.unheard`); `HIL validity` prints a `VIRTUAL GEAR` block: answer counters, any
`SAFETY` stop, what the teardown left.

## Writing a scenario

```python
@pytest.mark.hil_id("HIL-DIAG-09")
@pytest.mark.sniffer
def test_status_query_reaches_the_wire(api, sniffer, paced, op_check):
    short = api.present_addrs()[0]          # through the gear filter, never a literal
    with sniffer.window() as win:           # independent bus witness
        paced(1.0)                          # the WB ring drops faster bursts
        op_check(api.wait_op(api.attr_read(short, groups="runtime_status")))
        win.expect_frame("QUERY STATUS")    # decoded DALI on the wire
```

Every scenario carries its `HIL-<DOMAIN>-NN` id as a `hil_id` marker (registered in
`pyproject.toml`; the suite runs with `--strict-markers`); grep the id to find it, and
`-m hil_id` selects them all. Put back anything the test writes through a guard, and keep
visible actions out of tests that do not need them — each costs a go-ahead.

- **Targets.** A test that changes what a lamp shows takes its target from the `lamps`
  fixture or `cfg.lamp_short_set()`; `optical_addrs()`, `present_optical_addrs()`,
  `lamp_addrs()` and `off_all()` stay inside `HIL_LAMP_SHORTS` too. `addrs()`,
  `present_addrs()` and `devices()` honour only `HIL_GEAR_SHORTS`: they pick read
  targets. Whatever the selector, the [lamp guard](#the-installation-is-production)
  refuses a drive outside `HIL_LAMP_SHORTS`, and a group or broadcast action unless
  the whole segment is allowed; a gear-wide command such as `REMOVE FROM SCENE` is
  sent per lamp.
- **Reboots.** A test or fixture that reboots a controller (reset, flash, OTA, power
  cut, bootloader request) does so inside `Client.expect_reboot()`: only there are the
  failed requests that follow booked as `http_reboot_race` and every client's pooled
  connections dropped; outside it they spend the gated `http_transport` budget.
- **`202` routes** return before their first frame: wait for the operation (`api.wait_op`,
  the `*_checked` helpers) before asserting its outcome or the counters it moves.
- **The diagnostic path is not a transaction.** Separate `/api/v1/dali/*` requests can
  be split by the poller, HCL or another master overwriting a DTR, and a send-twice pair
  is one request with `repeat_count: 2`, never two; a raw DTR-armed write is proved by
  reading its effect back.
- **Retries.** A step a test repeats goes through the ledger: `api.count_retry(kind,
  detail)` for a request or a read, the oracle's `count_retry(cause)` for a
  measurement; a sniffer `resend=` counts itself. A new kind gets a line of 0 in
  `retry_budget.txt`. A conditional write is never repeated blindly: after a lost
  answer `rules_replace` reads `/rules` back and repeats only a write that did not land.
- **Skips and xfails.** A feature is skipped as absent only on the firmware's evidence (a
  `404`, a block missing from `/api/v1/diagnostics`); a failing probe on a build that has it
  fails the test. A known-failure hatch is a conditional
  `@pytest.mark.xfail(strict=True)`, never an imperative `pytest.xfail()`, which never
  reports XPASS and so hides a fixed defect and its regression alike.
- **Autouse fixtures** in the `tests/hil_*.py` plugins never take `api` (or anything
  else that skips on an unreachable controller) as a parameter, because an autouse skip
  skips every collected test, the hardware-free ones included: they build their own
  client, degrade to a printed warning and record an instrument failure for the per-test
  fixture to fail or skip on (`optical_session` skips optical tests on an unreachable DUT). Nor do they take any other bench fixture, `hil_config`
  included: the hardware-free verdict below reads every test's fixture closure.
- **Hardware-free tests** request no bench fixture (`BENCH_FIXTURES` in `hil/tiers.py`);
  a `*_unit.py` test that requests one is a collection error, and a guard refusal or a
  skip no `skip` or `skipif` marker declares fails it. A session made only of
  them skips `production_state`, `bench_baseline`, `dut_continuity`, the bridge probe, the
  session baselines, the validity report and `summary.md`.
  They build `HilConfig` with `serial_remote=""` and their own `base`: with the defaults,
  `serialmon.start` or `hil flash` could (re)start a reference bench's bridge, resetting
  its controller.
- **Measuring threads** own their `Client` (a shared one shares a `requests.Session` and
  the retry ledger); a sampler an exception kills fails nothing, so the test checks it.
- **Serial evidence**: a script takes the serial log's path from `serialmon.log_path(cfg)`
  and reads a missing or non-growing file as no evidence, never a clean window.
- **The sniffer decoder** names every application-extended opcode as a DT8 command:
  match another device type's by its bytes and its `ENABLE DEVICE TYPE` frame.
- **Mirrored constants**: `RULES_SOURCE_LIMIT_BYTES` in `tests/hil_test_guards.py` mirrors
  `MAX_RULES_SOURCE_BYTES` in `dali2rust-contracts`, and `hil corpus`'s colour-value width
  and defined sets mirror `colour_value_is_wide` / `colour_value_is_defined` in the
  domain crate; `hil/seriallog.py`'s `LATE_REPORT_BYTES` and `HEARTBEAT_PERIOD_S`, and
  the report interval, client limit and bridge inbox depth in `test_ws.py` and
  `test_ha_bridge.py`, mirror the firmware's, and `EMULATED_GTIN_BASE` in
  `hil/lamp_guard.py` the gear model's `build_bank0`; change them together.

## Validate the instrument before believing a measurement

What each oracle proves, and where it stops: [STRATEGY.md](STRATEGY.md) §3. At the rig,
measure an effect through a test's own fixtures (baseline, drive, measure) or run that
test alone.

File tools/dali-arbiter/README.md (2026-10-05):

# dali-arbiter — independent DALI wire witness

> **Targets an ESP32-C6 and is not ported to the ESP32-P4.** The firmware (an ESP-IDF
> C project for the C6) and its host-side decoder are the instrument's specification.

An edge recorder wired **receive-only** to the DALI bus, answering the question the
controller cannot answer about itself: is the frame it puts on the wire shaped the
way it should be? Why the firmware cannot judge its own transmit timing is in
[`08-dali-phy-and-transport.md`](../../documentation/architecture/08-dali-phy-and-transport.md);
this board is the independent observer it calls for.

Scope: the instrument's contract and build; its host-side decoder lives in the HIL
toolkit (below).

## The contract

- **Edges are captured by hardware** (the RMT peripheral latches pulse widths), and
  the capture path is IRAM-resident, so the instrument has none of the jitter it is
  measuring. A GPIO interrupt would add exactly that jitter.
- **The device decodes nothing.** It prints raw pulse widths, one line per frame,
  so the decode rules can be argued with and changed without a reflash:
  `E <seq> <t_end_us> <first_level> <d0> <d1> …` — `d0` starts at the first edge
  at `first_level`, levels alternate, and the last entry is the idle that ended
  reception. `#` lines are notes (banner, pin scan, periodic stats).
- **Never read its absolute numbers.** Its own opto path shortens every dominant
  pulse (by about 95 µs on the Pico-DALI2), so every measurement is a difference: a
  frame's first half-bit against the rest of that same frame, and our transmitter
  against a reference transmitter (the Wiren Board's master, or gear answers) in the
  same capture, so the bias cancels.
- **Receive only.** The TX line is parked recessive and never driven; a floating TX
  input could assert the bus on noise.

## Build (C6 wiring)

Pico-DALI2 receive output on GPIO 5, TX parked on GPIO 14. The boot banner prints a
transition count for every candidate GPIO, so a wrong pin does not look like a dead
bus.

```bash
source ~/.espressif/v5.5.3/esp-idf/export.sh
cd tools/dali-arbiter && idf.py set-target esp32c6 && idf.py build
idf.py -p <port> flash
```

## Host side

`hil/arbiter.py` parses, Manchester-decodes and scores captures (`capture`,
`summary`, `dump`).

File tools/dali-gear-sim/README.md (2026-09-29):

# dali-gear-sim — a board that answers as a fleet of DALI control gear

A bench instrument that runs on the redundancy pair's second ESP32-P4-ETH, borrowed for a
session. On the shared DALI wire it answers as a fleet of virtual control gear (DT6, DT8
Tc, DT8 RGB+Tc), so tests drive gear that is nobody's light: target states, groups,
scenes, HCL, a commissioning search, a poller sweep, a registry near its ceiling. It is
one bus load (~2 mA) however many gear it emulates.

Scope: the instrument, its build and its console protocol. The gear semantics are
`dali2rust-gear-model`, shared with the host dev server's simulated bus. Lending the
peer to the emulator and the HIL tier that drives the fleet live in
[`tools/hil`](../hil/README.md#virtual-gear).

## The one rule: never share an address with a real lamp

Two devices answering one short address do not degrade the bus, they kill it. So every
boot starts with **no fleet and no reserve**, and nothing is stored in flash. `reserve`
names every short address a real lamp holds on this wire: the controller's registry,
the Wiren Board master's device list and unpowered lamps a scan cannot see. `fleet` and
`enable` refuse until it is set, and a fleet asks for at most 64 − |reserve| addresses.
The model also refuses reserved addresses at construction and at `PROGRAM SHORT ADDRESS`.

## Build

A separate cargo workspace. Its `.cargo/config.toml` overrides the root's forced `MCU`
and sdkconfig for builds started in this directory. `sdkconfig.gear-sim.defaults` is
layered on the root's `sdkconfig.p4.defaults` and changes only what differs:
- the path to the root's `partitions-p4.csv` — one partition table per board, so the
  image fits the pair's OTA slot;
- no secondary console;
- `WARN` logs;
- no core dump on the console.

```bash
cd tools/dali-gear-sim && cargo build
just gear-sim-check                     # type-check against the shared crates
just gear-sim-isr-iram-check            # build, then the ISR-IRAM gate on the linked binary
```

The bench's boards hang on the Wiren Board's USB; the image reaches the peer only
through the HIL toolkit.

## Board and answer path

ESP32-P4-ETH + Pico-DALI2, wired like the controller: DALI TX on GPIO 14, inverted (pad
high = bus active); DALI RX on GPIO 17. The console is UART0 through the board's USB-UART.

The PHY is the firmware's `dali2rust-dali-phy`, on the gptimer driver path at interrupt
priority 3; [ADR-025](../../documentation/architecture/decisions/ADR-025-phy-interrupt-above-critical-sections.md)
keeps the emulator off the level-5 path. The interrupt runs on core 0, where it is
registered, and every emulator task is pinned to core 1, so critical sections on the
interrupt's core stay rare.

A decoded forward frame goes to the fleet in task context. The fleet's answer is staged
in the PHY's answer cell, and the interrupt sends it inside the IEC 62386-101 Table 20
window (`backward_window.rs`) — the mechanism the controller uses for its arbitration
answer. Several answering gear merge into one frame by OR-ing their dominant half-bits,
which is what the wired-AND bus does.

## Serial protocol

One port carries the event log and the console through one output path: the UART
driver behind the VFS, fed by a bounded queue with one writer, so the gear task never
waits on the UART. Data lines start with a token, everything else with `#`, so a reader
parses the stream without guessing:

```
# ready build=<sha> slot=<label> state=<token>   the console accepts commands (and `ready`)
C <t_us> A16 level 0 -> 180                     a gear's state changed
F <t_us> fe 90 Broadcast QUERY STATUS            a forward frame was heard     (log frame)
B <t_us> 84 n=1                                  an answer was staged          (log frame)
B <t_us> -- n=3 collision                        several gear answered differently
E <t_us> answer_cell_busy ...                    something went wrong
```

`state` is the running slot's OTA state as the bootloader keeps it:
- `pending_verify` — installed over OTA; any reset hands the board back to the controller;
- `valid` — written by wire: the merged image erases `otadata`, so the bootloader boots
  `ota_0` and records it valid; the role survives resets;
- `new`, `invalid`, `aborted`, `none`, `undefined` — anything else.

`C` lines carry the short and random address, `enabled`, groups, level, `identify`,
colour mode, mirek, xy, the RGBWAF channels, the level range, the Tc limits and the
scene levels. Lines the queue drops show up as `log_dropped` in `stats`.

| Command | |
| --- | --- |
| `ready` | the ready line again, for a reader that missed the boot |
| `reserve <a-b,c ...>` | the short addresses the fleet never holds; once per boot, before `fleet`; a second one is refused |
| `fleet <base> <dt6> <cct> <rgb>` | build the fleet from `base` upward, skipping the reserve; all disabled |
| `enable\|disable <addr\|all>` | put gear on or off the bus; enabling an address no gear holds is refused |
| `show [addr]` | the fleet table, or one gear |
| `stats` | loop counters; the answer cell (`sent`, `stale`, `expired`, `late`, `rejected`, `collided`); late ticks; forward frames per IEC 62386-101 Table 22 priority; violations (`enable_consumed`, `send_twice_interloper`) |
| `unaddress <count>` | take the short address off that many gear, leaving them as factory-fresh drivers |
| `autoact <addr> on\|off` | the DT8 Automatic Activation bit |
| `metering <addr> energy\|diagnostics\|both\|off` | DiiA Part 252/253 banks 202–207 and the device types that announce them |
| `luminaire <addr> off\|3\|4\|5\|bus-unit-on\|bus-unit-off` | memory bank 1's DiiA Part 251 extension at content format 3–5, and bank 0's `0x1B`/`0x1C` |
| `fail <addr> lamp\|none\|short\|open\|thermal\|derate\|<byte>` | `lamp` sets 102 status bit 1 alone; the rest set the Part 207 failure byte and let the model derive what follows |
| `drop <addr> <permille>` | withhold that fraction of answers |
| `log off\|change\|frame\|trace` | verbosity; keep `change` during a load run, `frame` makes the console the bottleneck |
| `reboot` | restart; under the OTA role this hands the board back to the controller |

How to read the answer cell on a shared wire:
- `stale` counts both a frame that moved the epoch before the answer went out and a
  yield to another transmitter, so it is non-zero wherever real gear or another master
  share the wire;
- `collided` stays 0 by construction: a backward frame is exempt from collision
  detection;
- `late`, `expired` and the late ticks are the timing verdicts.

## What it models

Implemented:
- the commissioning search (INITIALISE, RANDOMISE, COMPARE, WITHDRAW, PROGRAM/VERIFY
  SHORT ADDRESS);
- DAPC and the arc-power commands;
- group membership and the 16-scene table;
- level limits and fade registers;
- the status byte;
- memory banks 0 and 1 with DTR0 auto-increment;
- DT8 colour with the IEC 62386-209 staging rule;
- of the DT6 extended commands, the dimming curve and the Part 207 failure queries.

What the model leaves out is listed in
[`05-testing-and-bdd.md`](../../documentation/architecture/05-testing-and-bdd.md)
(*Host models and the mock transport*). An unknown extended opcode is ignored, so
`log trace` shows what a controller actually sends.

## Timing, and how far to trust it

A gear starts its backward frame 5.5–10.5 ms after the forward frame ends. The interrupt
decides when the answer starts. The emulator only has to stage it before the interrupt
arms it, `ANSWER_ARM_TARGET_IDLE_TICKS` after the forward frame ends, while the
capture completes after `RX_IDLE_LINE_HIGH_TICKS` (both in `dali2rust-dali-phy`); the
ring is polled once per tick.
`late`, `expired` and the late ticks are the PHY's reports on its own clock.

The independent check is to read an emulated gear from the Wiren Board's master.
Edge-level evidence needs a wire witness ([`tools/dali-arbiter`](../dali-arbiter/README.md)),
which has no board.

## Bring-up order

1. Put the image on the peer (`hil --peer role gear-sim`). The fleet is empty and
   transmits nothing; confirm from the log that it hears the traffic on the wire
   (`log frame`).
2. `reserve` every live address, `fleet`, `enable` one gear, query it from the
   controller, and check that `stats` shows it sent with no late ticks.
3. Read the same gear from the Wiren Board's master.
4. Scale up: four gear, then the tier's fleet; a poller sweep, a group apply.
5. Commissioning follows [`tools/hil/STRATEGY.md`](../hil/STRATEGY.md) §4.

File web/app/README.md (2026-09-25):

# dali2rust web UI

Preact + TypeScript single-page app for the controller, embedded in the firmware and
served from flash. It reads and writes the REST API (`/api/v1/*`) and listens to the
WebSocket push channel (`/api/v1/ws`), both served identically by the device and by
the host dev server.

Scope: the app's code layout, dev workflow and code conventions. The screens and the
rules every screen follows are in
[`documentation/product-design/web-ui/`](../../documentation/product-design/web-ui/README.md);
the API contracts in
[`documentation/product-design/rest-api/`](../../documentation/product-design/rest-api/README.md);
how UI work is built, carded and shipped in
[`10-build-release-and-tooling.md`](../../documentation/architecture/10-build-release-and-tooling.md).

## Layout

One file per screen in `src/screens/`; routes in `src/router.ts`, sidebar groups
(`NAV_GROUPS`) and the route switch in `src/app.tsx`; the typed client and DTO mirror in
`src/api/`; shared components in `src/components/ui.tsx`. A screen appears only once its
endpoint exists on the device.

## Dev workflow

```bash
# 1. the composed product stack on a simulated DALI bus, 127.0.0.1:8080
cargo run --target <host-triple> -p dali2rust-adapters --example host_dev_server
# 2. Vite with hot reload on :5173, proxying /api (WebSocket included) to it
cd web/app && npm ci && npm run dev
# or against a real controller
DALI2RUST_API_TARGET=http://<controller> npm run dev
```

The dev server takes `DALI2RUST_DEV_SERVER_ADDR` (or `PORT`) to move, and
`DALI2RUST_DEV_SERVER_FLEET=bench` for a full 64-address bus; its stdin console
plays a foreign master and a wall panel (`press`, `release`, `foreign`,
`occupancy`). It reads the bundle once at startup: restart it after
`bash scripts/build_web_ui.sh`. Shipping a UI change to the device is the chain in
`10-build-release-and-tooling.md`; what a UI pull request carries is in
[`CONTRIBUTING.md`](../../CONTRIBUTING.md).

## Conventions

- **Data** loads through `usePoll` (paused while the tab is hidden) or `useLive`,
  which adds WebSocket channels as refetch triggers; how the two share one data shape
  is [`web-ui/websocket.md`](../../documentation/product-design/web-ui/websocket.md).
- **Operations**: a `202 { operation_id }` is polled to a terminal state by
  `trackOp` / `runOp`, and anything that acts on the result asks `opCommitted`.
- **Inputs over polled data** use `EditableText` / `EditableName`; the colour control
  never sends `power`; free-running counters show a delta beside the absolute value —
  the rules behind all three are in
  [`web-ui/README.md`](../../documentation/product-design/web-ui/README.md).
- **No modals, no `prompt()`**: inline editors, two-step "Sure?" for destructive
  actions.
- **Every interactive control uses a class from `app.css`** (`btn`, `sel`, `field`,
  `act`, …); checkboxes stay native app-wide. `ADAPTER = 0`: one adapter per
  controller.

## Adding a screen

1. Route: an entry in `ROUTES` and the `Route['name']` union (`src/router.ts`).
2. API: mirror the DTOs in `src/api/types.ts`, add typed calls to `src/api/client.ts`.
3. Screen: `src/screens/<name>.tsx`, data through `usePoll` / `useLive`, actions
   through `runOp` / `notify`, layout from the shared components in
   `src/components/ui.tsx`.
4. Wire it: the case in `Screen()` and a line in `NAV_GROUPS` (`src/app.tsx`).
5. Its design card, then `npm run build` and the flow against the dev server.

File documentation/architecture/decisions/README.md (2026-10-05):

# Architecture decisions

The decisions that shape dali2rust, one record each, as they currently stand.

Scope: why the system is built this way. How it works is in the
[architecture documents](../README.md).

| ADR | Title | Status | Decision |
| --- | --- | --- | --- |
| [001](ADR-001-typed-bus-and-postcard-budget.md) | Typed bus, postcard budget | Accepted | Typed envelopes, `postcard`, 128-byte frames |
| [002](ADR-002-http-confirmation-bridge.md) | HTTP confirmation bridge | Accepted | One slot pool; `503` fast, `504` on timeout |
| [003](ADR-003-isr-owned-phy.md) | Interrupt owns the PHY | Amended by 010, 025 | Tasks reach the FSM through ISR-safe cells only |
| [004](ADR-004-bdd-black-box-boundary.md) | BDD is black-box | Accepted | External surfaces only; no test hooks |
| [005](ADR-005-declarative-contract-macro.md) | Contract macro, dispatch tables | Accepted | One declaration; append-only wire order |
| [006](ADR-006-routed-command-delivery.md) | Routed commands | Amended by 015, 021 | Owner unicast; every rejection has a listener |
| [007](ADR-007-apply-orchestrator.md) | Apply orchestrator | Amended by 012 | Paced bulk applies; no unbounded bursts |
| 008 | — | Removed | Superseded by ADR-011 |
| [009](ADR-009-background-wire-time-budget.md) | Background wire budget | Amended by 013 | Yield per frame; ≤ 25 % of the wire |
| [010](ADR-010-isr-crate-and-profile-exception.md) | Interrupt crate boundary | Amended by 025 | `no_std` crate, linked-binary gate |
| [011](ADR-011-retire-esp32s3.md) | One board | Accepted | ESP32-P4-ETH only, wired |
| [012](ADR-012-async-chunked-config-writes.md) | Chunked config writes | Accepted | Stage, commit by bracket, answer `202` |
| [013](ADR-013-wire-priority-and-yield-granularity.md) | Wire priority, yield granularity | Amended by 016, 017 | Who yields and where, by command kind |
| [014](ADR-014-gear-model-and-second-dali-endpoint.md) | One gear model | Accepted | Shared model; host sim plays the foreign master |
| [015](ADR-015-routed-event-delivery.md) | Routed events | Amended by 021 | Route by declared kind; undeclared is silent |
| [016](ADR-016-input-devices-and-rule-engine.md) | Input devices, rule engine | Accepted | Part 103 on one transport; bounded rules from source |
| [017](ADR-017-dali-transactions-and-frame-priority.md) | Transactions, frame priority | Amended by 020 | Priority by purpose; §9.2 transactions |
| [018](ADR-018-controller-redundancy.md) | Controller redundancy | Accepted | DiiA 351 arbitration; HTTP config pull |
| [019](ADR-019-standby-dali-endpoint.md) | Host standby endpoint | Deferred | Coprocessor design; nothing built |
| [020](ADR-020-violating-backward-frame-is-an-answer.md) | Violation is an answer | Accepted | Terminal; YES but no value |
| [021](ADR-021-required-event-delivery.md) | Delivery-required events | Accepted | Bounded backoff for sole carriers of a fact |
| [022](ADR-022-rgbwaf-channels-are-srgb.md) | RGBWAF is sRGB | Accepted | sRGB above the wire, linear on it |
| [023](ADR-023-named-subscribers-and-shared-coalescing.md) | Named subscribers | Accepted | Named event subscribers; one coalescer |
| [024](ADR-024-ota-over-ethernet.md) | OTA over Ethernet | Amended by 025 | Device pulls its image; rollback unless proven |
| [025](ADR-025-phy-interrupt-above-critical-sections.md) | Interrupt above critical sections | Accepted | Level 5, execute from PSRAM, flash gate |
| [026](ADR-026-dt8-colour-activation.md) | DT8 colour activation | Accepted | Arc command or `ACTIVATE`; no `ACTIVATE` before a `DAPC` |
| [027](ADR-027-dtr-operand-proof-and-readback-outcomes.md) | DTR proof, read-back outcomes | Accepted | Arm, prove, act; three read-back outcomes |
| [028](ADR-028-task-stacks-in-psram-on-the-xip-image.md) | Stacks and Rust heap in PSRAM | Accepted | On the XIP image only mapping flash or wire timing keeps a stack internal; Rust objects from 256 B in PSRAM |
| [029](ADR-029-network-buffers-in-psram-and-a-measured-receive-ring.md) | Network buffers in PSRAM | Accepted | lwIP and received frames in PSRAM; mailbox holds the window; ring sized by its drop counter |
| [030](ADR-030-controller-as-a-part-103-bus-unit.md) | The controller as a Part 103 bus unit | Deferred | One stateful model answers every device query; five decisions owed before code |
| [031](ADR-031-gear-emulator-on-the-standby.md) | Gear emulator on the standby | Accepted | Lent by OTA for one boot or by wire; a session envelope keeps it off the owner's lamps |
| [032](ADR-032-installation-and-node-identity.md) | Installation and node identity | Accepted | `controller_id` is the pair's installation; `node_id` and the hostname come from the node's MAC |
| [033](ADR-033-mqtt-rule-trigger.md) | MQTT rule trigger | Accepted | Exact topics the bridge subscribes from a read port; one required event per message; a subscription's retained replay fires nothing |

A new record takes the next number and the same sections (`Status`, `Date`, `Context`,
`Decision`, `Consequences`). A later decision that changes an earlier one is merged into
that record and named in its status line.

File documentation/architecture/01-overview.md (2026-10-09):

# 01 Overview

What the controller is made of: the crates and what each owns, the composition root, the
composed runtimes, and the crate boundaries that are decisions.

Scope: crate responsibilities and cross-crate rules; each subsystem has its own document
([reading order](README.md)). What the product does lives in
[`../product-design/`](../product-design/README.md).

## Hardware

- One board: Waveshare ESP32-P4-ETH (dual-core RISC-V, 32 MB PSRAM, 32 MB flash). Wired
  Ethernet is the only network path; the P4 has no radio
  ([ADR-011](decisions/ADR-011-retire-esp32s3.md)).
- The DALI bus is bit-banged by a GPTimer interrupt that owns the PHY
  ([08](08-dali-phy-and-transport.md)).

## Crates

| Crate | Owns |
| --- | --- |
| `dali2rust-contracts` | Canonical message types (`msg/`), bus envelopes, the `postcard` codec and frame budget |
| `dali2rust-bus` | Bounded typed bus: channel traits, routing task, publisher, required publish, correlation ids |
| `dali2rust-domain` | Pure DALI and registry logic and the domain traits (controller, read ports); no I/O |
| `dali2rust-platform` | HAL traits, the lock-free primitives all layers share (wire lease, sniffer tap, wire counters), the flash gate and the in-place slice sort; no ESP-IDF types, no business rules |
| `dali2rust-api` | HTTP router and handlers, the confirmation bridge, and every byte of JSON (REST DTOs, `src/ws/`, `src/ha/`) |
| `dali2rust-adapters` | The composition helper and adapter implementations: DALI transports (ESP, mock, sim), ESP and host HTTP servers, console logging |
| `dali2rust-dali-phy` | Everything the PHY interrupt executes, and nothing else (`no_std`) — [ADR-010](decisions/ADR-010-isr-crate-and-profile-exception.md) |
| `dali2rust-dali-codec` | Manchester encode/decode, in task context |
| `dali2rust-gear-model` | Stateful fake control gear (Parts 102/207/209 slave side) and Part 103 input devices, for the host simulator, host tests and `tools/dali-gear-sim`; never linked into the firmware image |
| `dali2rust-dali-runtime` | `DaliWorker`, the one owner of the DALI wire: semantic executor, controller, priority table |
| `dali2rust-registry-runtime` | `RegistryStore`, its single-writer worker, the persistence slices |
| `dali2rust-operations-runtime` | Operation tracker and apply orchestrator ([ADR-007](decisions/ADR-007-apply-orchestrator.md)) |
| `dali2rust-fanout-runtime` | State-fanout projector and sniffer translator |
| `dali2rust-display-runtime` | OLED display worker, screens and fonts |
| `dali2rust-hcl-runtime` | HCL scheduler: curves, astronomy, override tracking |
| `dali2rust-poller-runtime` | Background interval reader (off by default) |
| `dali2rust-ws-runtime` | WebSocket client hub and fan-out worker |
| `dali2rust-mqtt-runtime` | Home Assistant MQTT bridge and broker client; owns `HomeAssistantDiscoveryPublishCommand` and `MqttPublishCommand` (the other `HomeAssistant*` commands belong to the registry worker) |
| `dali2rust-rules-model` | Typed rule graph, limits, `RuleCompiler` / `NameResolver` traits |
| `dali2rust-rules-lang` | The rule-language compiler (`LANG_RULES_V1`): source text → model |
| `dali2rust-rules-runtime` | Rules document store and worker, its persistence, the engine |
| `dali2rust-redundancy-runtime` | Controller redundancy: arbitration lease, supervisor, arbitration and replication workers ([ADR-018](decisions/ADR-018-controller-redundancy.md)) |
| `dali2rust-ota-runtime` | Firmware update over the network ([ADR-024](decisions/ADR-024-ota-over-ethernet.md)) |
| `dali2rust-bsp` | Board support: thread spawner, stack classes, task registry, PSRAM box, heap stats, slice-store flash binding |
| `dali2rust-test-support` | Shared host-side test helpers and port doubles |
| `dali2rust-firmware` | The binary and the only production composition root |

`tests/dali2rust-bdd` is the black-box BDD crate ([05](05-testing-and-bdd.md)).

## Composition

- `dali2rust-firmware` builds the stack by calling
  `dali2rust_adapters::build_router_with_bus_and_transport` with the real transport. The
  helper is generic over `DaliTransport`; BDD and the host dev server call it with
  `MockDaliTransport` and `SimDaliTransport`, so every test runs the production wiring.
- Adapters wire and bind; business rules never live there. A worker's logic and its
  spawn function belong to the runtime crate that owns the slice.
- The API layer never holds a mutex around the DALI transport. HTTP, MQTT, HCL and
  rules code publish typed commands on the bus; none of them calls `DaliTransport` or
  mutates the registry directly ([03](03-bus-and-backpressure.md)).
- One DALI adapter is composed (registry adapter 0); the multi-adapter model is designed
  but not wired.

```mermaid
flowchart LR
  Ingress[HTTP / MQTT / HCL / rules / poller] --> Bus[Typed bus]
  Bus --> DaliWorker[DaliWorker]
  DaliWorker --> Transport[DaliTransport]
  Transport --> Sniffer[Sniffer translator]
  DaliWorker -- applied and read facts --> Bus
  Sniffer -- observed frames --> Bus
  Bus --> Projector[State-fanout projector]
  Projector -- RegistryRuntimeUpdateCommand --> Bus
  Bus --> Registry[Registry worker]
  Registry -- changed events, confirmations --> Bus
  Registry --> ReadPorts[Read ports] --> Ingress
  Bus --> Observers[Operations, apply orchestrator, display, WS, MQTT, rules]
```

## Crate boundaries that are decisions

- **The codec and the gear model are shared crates because DALI has a second endpoint.**
  `tools/dali-gear-sim`, a gear emulator, speaks the same wire and needs the same slave
  semantics but is its own cargo workspace ([10](10-build-release-and-tooling.md)). The
  host `SimDaliTransport` runs the gear model,
  implements the observed-frame seam, and the dev server's stdin console
  (`press` / `release` / `foreign` / `occupancy`) plays a foreign master, so the sniffer
  translator, fan-out from foreign frames, Part 103 events and rule triggers run on the
  host ([ADR-014](decisions/ADR-014-gear-model-and-second-dali-endpoint.md)).
- **`ws-runtime`, `mqtt-runtime` and `redundancy-runtime` depend on `api`.** Their JSON
  is built or parsed in `dali2rust-api` only (`src/ws/`, `src/ha/`, the slice manifest);
  the runtime crates carry pre-serialized strings and typed rows
  ([04](04-contracts-and-api-bridge.md)).
- **The rule language is three crates.** `rules-model` is the stable contract,
  `rules-lang` is one compiler behind `dyn RuleCompiler`, `rules-runtime` consumes the
  model and never parses text; it stores and persists the source and hands it to the
  compiler. The stored canon is the operator's source text, tagged with the `lang_id`
  that compiled it; there is no printer. A replacement language is a new crate and a
  new id, not an engine change
  ([ADR-016](decisions/ADR-016-input-devices-and-rule-engine.md)).
- **There is no input-device runtime.** Part 103 commissioning, instance enumeration
  and configuration are semantic commands executed inside `DaliWorker`: one wire owner,
  one priority table, one transaction mechanism (ADR-016).

## Trait placement

- HAL traits → `platform`; DALI and domain traits → `domain`; bus channel traits →
  `bus`; HTTP traits → `api`; rule-language traits → `rules-model`.
- No ESP-IDF types in `platform` or `domain`; ESP-only code sits behind
  `#[cfg(target_os = "espidf")]`.

## Composed runtimes

Composed: DALI worker, registry, operations and apply orchestrator, state fan-out and
sniffer translator, display, HCL scheduler, poller, WebSocket, Home Assistant MQTT
bridge, statistics, rules engine, controller redundancy, OTA. Designed only: cluster and
adapter proxy ([`../product-design/runtime-modules/`](../product-design/runtime-modules/README.md)).
Stage status: [`../product-design/status.md`](../product-design/status.md).

## System-wide properties

- The DALI runtime shares its bus with foreign masters: a contended exchange is retried
  or re-read under a bounded budget, not reported as a gear fault
  ([08](08-dali-phy-and-transport.md), [09](09-dali-protocol-rules.md)).
- Background work never delays an operator on the wire
  ([09](09-dali-protocol-rules.md)).
- Group and scene apply diffs are expanded by the apply orchestrator
  ([06](06-registry-and-persistence.md), ADR-007).

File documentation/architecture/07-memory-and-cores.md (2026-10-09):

# 07 Memory and Cores

Where memory comes from on the ESP32-P4, what may live where, how task stacks are sized
and gated, why the httpd stack is a budget, and which task runs on which core.

Scope: internal SRAM versus PSRAM, stacks, core placement, reading memory at runtime.
Crash triage and coredumps → [`../reference/debugging.md`](../reference/debugging.md);
flash, XIP and cache discipline → [08](08-dali-phy-and-transport.md); threading rules →
[02](02-runtime-and-threading.md); sdkconfig keys → [10](10-build-release-and-tooling.md).

## The pools

- The P4 has 768 KB of internal L2MEM, 32 MB of in-package PSRAM and 32 MB of flash. The
  image executes from PSRAM ([ADR-025](decisions/ADR-025-phy-interrupt-above-critical-sections.md)).
- **Internal SRAM is the scarce resource.** 128 KB of L2MEM is the L2 cache
  (`CONFIG_CACHE_L2_CACHE_SIZE`, and 128 KB is the smallest choice) and IRAM is carved
  from the same region, so the internal heap is roughly 575 KB. Its consumers are the
  stacks that must stay internal, ESP-IDF and its drivers (the EMAC DMA ring among
  them), and small allocations, C and Rust alike.
- The internal floor after boot is a property of each release; the bench gates the free
  internal heap at each named boot stage
  ([`tools/hil/README.md`](../../tools/hil/README.md) §Run validity).
- The failure at the bottom is not "out of memory". A plain allocation falls back to
  PSRAM; what fails is what must be internal — a task stack, DMA, TLS. On a build whose
  httpd stack is internal, `httpd_start` then fails with `ESP_ERR_HTTPD_TASK`, an abort
  and a boot loop with no network surface to diagnose it from. Every byte a change adds
  to the boot path is weighed against that.

## Placement

- `CONFIG_SPIRAM_MALLOC_ALWAYSINTERNAL` is 16 KiB: a plain C allocation below it is
  internal, above it PSRAM. On the XIP image the firmware's allocator
  (`dali2rust_bsp::rust_heap::CountingAllocator`) puts every Rust object from 256 B in
  PSRAM first and leaves smaller ones internal first
  ([ADR-028](decisions/ADR-028-task-stacks-in-psram-on-the-xip-image.md));
  `DALI2RUST_RUST_HEAP_INTERNAL=1` restores ESP-IDF's size rule for Rust too, where a
  multi-KiB record behind a plain `Box` lands in internal SRAM.
- The network stack is in PSRAM: lwIP allocates there first, and each received frame is
  copied there as it leaves the EMAC ring
  ([ADR-029](decisions/ADR-029-network-buffers-in-psram-and-a-measured-receive-ring.md)).
  The ring itself, 34.5 KB, is internal because the driver's DMA requires it.
- Multi-KiB plain-data records go to PSRAM explicitly through
  `dali2rust_bsp::psram::PsramBox`. Registry tables are pre-sized to the product limits,
  so each is one allocation above the threshold, lands in PSRAM and never rehashes.
  Capacity in PSRAM is free; capacity in internal SRAM is what runs out.
- Internal only, allocated by name: everything the PHY interrupt touches
  ([ADR-003](decisions/ADR-003-isr-owned-phy.md)) and anything a driver needs in internal
  memory. Rust atomics and mutex data may live in PSRAM on the XIP image — the P4's
  atomic operations work there from both cores, and the boot self-test
  `DALI2RUST_PSRAM_ATOMIC_SELFTEST` checks it on the device.
- An allocation that must be internal and is large asks for it with
  `heap_caps_malloc(MALLOC_CAP_INTERNAL)`; a plain allocation that size would land in
  PSRAM.
- A stack's home is chosen at spawn (`dali2rust_bsp::esp_thread::StackHome`,
  [ADR-028](decisions/ADR-028-task-stacks-in-psram-on-the-xip-image.md)): internal;
  PSRAM always, for a task that never touches flash (the UART log writer, the slice
  reload); or PSRAM on the XIP image, for every thread that never maps flash — the
  workers, the httpd task, the watchers, boot hydration. `DALI2RUST_STACKS_INTERNAL=1`
  keeps the last kind internal.
- What rules a PSRAM stack out is mapping flash, not writing it. On the XIP image a
  program, erase or read over SPI1 leaves the cache on; `esp_mmu_map` and `esp_mmu_unmap`
  turn it off on both cores even there and assert that the caller's stack is internal.
  `esp_partition_mmap` maps, and so do `esp_ota_begin`, `esp_ota_end`,
  `esp_ota_set_boot_partition`, `esp_ota_mark_app_valid_*` and
  `esp_ota_get_{state,boot}_partition`. The OTA adapter refuses those calls by name on a
  PSRAM stack; the update and boot-verify threads keep internal stacks for them.
- Internal stacks stay for what carries the wire's timing — the DALI worker, the DALI
  sniffer, the bus task — and for `main` and every ESP-IDF task.
- Stream rather than buffer: HTTP responses have no full-body buffer, and the
  persistence flush reuses one small chunk buffer ([06](06-registry-and-persistence.md)).

## Building large values

- Allocate first, initialise in place: a multi-KiB record is never built on a worker
  stack. `PsramBox::new(T)` takes `T` by value, so the caller's frame holds two copies
  before a byte reaches PSRAM. Records are built with `PsramBox::new_with` and an
  in-place initialiser (`PhysicalDeviceRecord::init_empty`); the by-value constructor
  exists only in tests, and a section above `MAX_INLINE_INIT_TEMP_BYTES` (2 KiB) owes its
  own in-place default. Stack-footprint tests hold all three.
- On a worker stack a multi-KiB field is moved with `mem::swap`, never cloned into
  place.
- A helper that builds a large value for a caller on a tight stack (route wiring on
  `main`, the diagnostics and stats DTOs for the WebSocket worker) is `#[inline(never)]`:
  inlined, its frame is added to the caller's for the caller's whole body. The two DTOs
  are filled in place in a `Box` (`*_dto_into`), never returned by value.
- The standard slice sorts keep their scratch in their own frame: 4 KiB for `sort*`
  (driftsort), up to 48 elements for `sort_unstable*`. Firmware code calls no stable std
  sort: it orders its lists, which product limits bound, with the in-place, stable
  `dali2rust_platform::small_sort::insertion_sort_by` or, where the order of equal
  elements cannot matter, with `sort_unstable*`. A `BTreeMap` (a `serde_json::Map`
  included) collected from an array or an iterator runs the same stable sort, so one is
  filled with `insert`.

## Stack classes

A class is chosen by what the thread does, not by inheritance; where its stack lives is
the spawn's `StackHome` (§Placement). Constants live in `dali2rust_bsp::std_thread_stack`
unless named.

| Class | Size | For |
| --- | --- | --- |
| `HYDRATION_WORKER` | 48 KiB | One-shot boot hydration, joined; a slice reload (import, replication) |
| `HTTPD_TASK_STACK_BYTES` (adapters) | 20 KiB | The one httpd task |
| `OTA_UPDATE_STACK` | 16 KiB | One update, spawned fallibly when it starts |
| `COMMAND_WORKER_STACK` | 12 KiB | Deep executors: DALI worker, rules worker |
| `STATE_WORKER_STACK` | 10 KiB | Workers that own state and build views: registry, operation tracker |
| `EVENT_WORKER_STACK` | 8 KiB | Workers that route small payloads: projector, sniffer translator, apply orchestrator, HCL, poller, WebSocket, MQTT, replication; the boot verifier; one `ws-client` sender per connected client, so the four-client cap holds 32 KiB |
| `RING_CONSUMER_STACK` | 8 KiB | Ring and driver pollers: `dali-sniff`, IP watcher |
| `DISPLAY_WORKER` | 6 KiB | Display worker, SNTP watcher |
| `ARBITRATION_WORKER_STACK` | 4 KiB | Arbitration probe worker |
| `OTA_LISTENER_STACK`, `ARBITRATION_SUPERVISOR_STACK`, `CENSUS_STACK` | 3 KiB | Permanently idle or once-a-minute tasks |

- A task that idles for the whole uptime — a listener, a supervisor, a feature that is
  off by default — gets the smallest class; the work it triggers runs on a thread
  created for the occasion.
- The bus task and the confirmation bridge use 8 KiB constants local to their crates, and
  the UART log writer a 4 KiB one (`console.rs`); `main` has the sdkconfig's 12 KiB for
  the composition boot and returns afterwards, so that stack is freed. The census thread
  carries the heartbeat. `mqtt_task` is sized by the bridge (`TASK_STACK_BYTES`); ESP-IDF
  allocates it internal.

## The stack census is a gate

- Every task's high-water mark is logged once a minute (the census, [02](02-runtime-and-threading.md)),
  and the bench gates each task against its stack budget
  ([`tools/hil/README.md`](../../tools/hil/README.md) §Run validity).
- A breach is answered by making the path shallower, not by growing the stack.
- `StackLowWater` (`dali2rust-bsp::stack_probe`) names the path the census cannot: the
  registry worker samples once per turn, tagged with the payload kind that just ran.
- The census line (`task stack hwm (B free…): <task>=<bytes> …`) and the boot-stage lines
  (`boot heap [<stage>]: internal free=…`, `internal heap before httpd: free=…`) are
  parsed by the bench's validity section and `hil corpus`: reword one, or rename a stage,
  together with `tools/hil/hil/validity.py` and `boot_heap_budget.txt`.
- Measure a change's frame depth on the linked image before flashing, not after
  (`scripts/measure_stack_frames.py` reads every stack adjustment of a function, not only
  the first `addi sp`, and adds a prologue the size-optimised build outlined into an
  `OUTLINED_FUNCTION_*` fragment). With `--path <function>` it prints the deepest static
  call path below a function: it names where the depth is, but it is no bound — it does
  not follow indirect calls (trait objects, the `log` facade) and it counts error branches
  the census never runs. A budget moves only on a census.

## The httpd stack is a budget

- Every handler runs on the one httpd task and builds its response there.
- A response is a resource, not a dump. When a view grows, the resource splits: physical
  devices are read as a summary list, a device core, attribute sections chosen with
  `?sections=`, and bank coverage.
- A container serializes its children one at a time inside `serialize` rather than
  holding them all.
- The full physical-device view is off every read-port trait
  ([06](06-registry-and-persistence.md)), so a handler cannot reach it: a compile error,
  not a review convention.
- Size ceilings on views and DTOs are tests. Raising a ceiling is not the fix; moving
  the stack size needs a bench high-water measurement first.
- On the XIP image the stack is in PSRAM (`task_caps`) and nothing is reserved; the task
  never maps flash — the running OTA slot comes from the reading taken at boot and after
  each update ([08](08-dali-phy-and-transport.md)).
- On a build without XIP the stack must be one contiguous internal block.
  `HttpdStackReserve` takes it, plus headroom for `httpd_start`'s own allocations, early
  in boot before the worker fleet fragments the heap, and releases it immediately before
  `httpd_start`.

## Workers read narrow views

- A worker that reads the registry on its own stack does so through a narrow port of
  small `Copy` views (poll targets, lamp capabilities, policy cells, Home Assistant
  publish views); the REST-shaped views, which allocate owned strings per row, are never
  in that port's trait bounds.
- The display worker's stack is 6 KiB, so it never holds a registry view; a fat view is
  not made safe by being read quickly. It reads a small `Copy` sample: the registry's
  counts, the poller's settings and the adapter gate come from `display_sample_parts`
  under one read lock, so one screen shows one instant; everything else on the screen is
  an atomic load, assembled in `dali2rust-adapters/src/runtime/display_source.rs`, so
  the display crate depends on no other runtime.

## Cores

- Two cores, FreeRTOS SMP ([02](02-runtime-and-threading.md)).
- The DALI PHY interrupt is allocated from the main task and runs on core 0.
- Pinned to core 1, away from the interrupt: the heartbeat, census and heap diagnostics
  thread and the UART log writer.
- Everything else, httpd and lwIP included, is unpinned. The heartbeat reports where
  the interrupt and httpd actually run (`cores: dali_isr=… httpd=…`).

## Reading memory at runtime

- `GET /api/v1/stats` reports internal free, largest block, minimum ever, total and
  allocated-block count, and the PSRAM-dominated free heap. The serial heartbeat reads
  the same `HeapStatsPort` (`dali2rust-platform::heap`, ESP implementation in
  `dali2rust-bsp::heap_stats`), so the two cross-check. Host builds report `null`, and
  the web UI hides the block.
- The firmware's global allocator (`dali2rust_bsp::rust_heap::CountingAllocator`) counts
  the Rust heap by placement: live and peak bytes in internal SRAM and in PSRAM on
  `/api/v1/stats`, and the internal bytes by size class on the heartbeat's `rust heap:`
  line. Everything else on the internal heap is C: IDF, lwIP, drivers, task stacks.
- Largest block, total and block count are boot-stage figures from one heap walk per
  stage; nothing walks the heap at runtime ([02](02-runtime-and-threading.md)).
- The internal minimum falls at runtime as well as at boot — an update, WebSocket
  clients and bursts of requests each take internal SRAM while they last. The heartbeat
  prints `internal SRAM low-water` with the Rust heap's share each time the minimum
  drops below 12 KiB, and the bench gates the minimum at session end
  (`runtime_heap_budget.txt`).
- Boot cost is logged per stage (composition start, around hydration, around the OTA
  worker, after the workers, before httpd); those are the stages
  `boot_heap_budget.txt` gates.

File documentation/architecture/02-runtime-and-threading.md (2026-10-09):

# 02 Runtime and Threading

How the composed stack runs on FreeRTOS: which tasks exist, how a worker waits, what the
single HTTP task may do, how logging stays non-blocking, and what nothing may do while
the DALI wire is live.

Scope: the task model and its blocking rules. The PHY interrupt and the task↔ISR
boundary → [08](08-dali-phy-and-transport.md); stack sizes, memory placement and core
placement → [07](07-memory-and-cores.md); bus routing → [03](03-bus-and-backpressure.md);
registry locking → [06](06-registry-and-persistence.md).

## Tasks

- Every `std::thread` is a FreeRTOS task. Each runtime crate ([01](01-overview.md))
  owns the spawn function of its workers and the composition starts them
  (`SpawnedWorkers` in `dali2rust-adapters`). The MQTT bridge and the OTA listener are
  optional: absent when composition wires no client or the build cannot update itself.
  The WebSocket fan-out always runs, spawned last because it samples the read models.
- Beside the workers: the bus routing task, the transport's `dali-sniff` drain, the one
  `httpd` task, the UART log writer, the census thread, the IP and SNTP watchers, the
  OTA boot verifier, and per-occasion threads: `ota-run` per update, `registry-reload`
  twice per slice import or replication pass (checking the bytes, then the reload) on the
  device, and one `ws-client` sender per
  connected WebSocket client, on the device as on the host (its stack:
  [07](07-memory-and-cores.md)).
- `registry-hydrate` is a one-shot boot thread, joined before any worker starts
  ([06](06-registry-and-persistence.md)).
- The P4 is dual-core and FreeRTOS runs SMP: two tasks, or a task and the PHY interrupt,
  execute at the same instant. Correctness never rests on single-core interleaving.
- The target has no 64-bit atomics; shared counters are `AtomicU32` and wrap.

## How a worker waits

- The primary channel is read with a blocking `recv()` or a bounded `recv_timeout()`.
  Secondary inboxes are drained with `try_recv()` only after the primary wait returns.
  `dali2rust_bus::recv_then_drain` is the single-inbox shape: one bounded wait, then
  whatever that inbox already holds.
- Never a `try_recv()` + `thread::sleep` polling loop. Never `thread::park()` on the main
  thread: `main` hands the heartbeat to the `census` thread and returns; only if that
  spawn fails does the 1 s heartbeat loop run on `main`.
- Idle back-off ≥ 10 ms, heartbeat or keep-alive ≥ 1 s; anything under 1 ms is a busy
  loop.
- A self-paced worker waits on its inbox with a timeout, never on a bare timer: its
  inbox disconnecting is how it learns the stack is gone (see *Bus lifetime*).
- A subscriber with nothing to do does not wake ([03](03-bus-and-backpressure.md)).

## The tick and sub-tick waits

- `CONFIG_FREERTOS_HZ` is 1000, so a tick is 1 ms.
- A sleep shorter than one tick does not sleep: newlib's `usleep` / `nanosleep` call
  `vTaskDelay` only from one tick upward and spin in `esp_rom_delay_us` below it. A
  thread in that state never yields, the idle task on its core never runs, and the task
  watchdog names a task that is not at fault.
- Decide with `dali2rust_platform::dali::sleep_parks_the_task(step_ms, tick_ms)`, with the
  tick derived from `configTICK_RATE_HZ`, never by comparing with a literal.
- A deliberate sub-tick spin is marked `// busy-wait-ok:`, never `// sleep-ok:`, so
  searching for the first marker lists every place the firmware spins on purpose (marker
  rules: [05](05-testing-and-bdd.md)).

## Spawning

- Every thread spawns through `dali2rust_bsp::esp_thread`. `spawn_named_stack_in` is for
  boot-time workers and panics if the spawn fails, because an incomplete stack must not
  run. `try_spawn_named_stack_in` is for anything a client can drive: under
  `panic = abort` a failed spawn there would be a remote reboot switch. Each takes the
  thread's `StackHome` ([07](07-memory-and-cores.md) §Placement); `spawn_named_stack`
  and `try_spawn_named_stack` are the same pair with the stack fixed internal.
- The FreeRTOS task name comes from the `ThreadSpawnConfiguration` that helper sets
  (truncated to 15 characters). `std::thread::Builder::name` never reaches the task, so a
  thread spawned any other way reads `pthread` in every watchdog dump, coredump and
  census.
- Names are `&'static CStr`, so a spawn allocates nothing the process cannot reclaim.
- The helper registers each thread in the BSP task registry for its lifetime; the
  census reads that table.

## The HTTP task

- `esp_http_server` runs **one** task that `select()`s over every open socket and runs
  each handler inline. `max_open_sockets` (10) sizes the descriptor set, not a pool; its
  bound against the lwIP socket count is in
  [10](10-build-release-and-tooling.md#sdkconfigp4defaults).
- Every millisecond a handler blocks, no other client is served. A mutating request that
  waits for its confirmation holds the task up to `confirmation_timeout_ms` (2000 ms).
  Work that would wait longer moves the wait off the task — accept, answer `202` with an
  operation id ([ADR-012](decisions/ADR-012-async-chunked-config-writes.md)) — rather
  than raising a timeout.
- A handler that publishes several frames shares **one** deadline across them; a fresh
  timeout per frame is forbidden. `publish_batch_and_wait_for_success` is the shape.
- Responses are built on this task's stack, which is a budget
  ([07](07-memory-and-cores.md)).

## WebSocket on the HTTP task

- A send runs on the httpd task (queued there with `httpd_queue_work`, whose callback
  calls `httpd_ws_send_frame_async`) and occupies the task every socket shares.
  `esp-idf-svc` fixes the send timeout at 5 s, so the design case is one 5 s stall of
  every socket.
- Bounds that keep it there: sniffer records batched into one frame per 100 ms under a
  2048-byte payload budget (a byte cap, enforced where the bytes exist; shed records are
  reported in `dropped_since`); a per-client queue bounded by 32 frames and 16 KiB,
  whichever comes first, that drops and tells the client to refetch rather than
  accumulate; a client reaped on its first send error; at most four clients, each
  holding a socket for its session.
- The device never sends a WebSocket ping.
- On the device a client's frames go out on its `ws-client` thread, which queues each
  send to the httpd task and waits for it. Code already running on the httpd task (the
  upgrade handler, a PONG, a CLOSE) sends through the connection itself, never through
  that path: queued work waiting on its own task never runs.
- `/api/v1/ws` is registered before the wildcard routes (`esp_http_server` matches URI
  handlers in registration order, and `/*` would take the upgrade) by
  `dali2rust-adapters/src/http/esp_ws.rs`, with ESP-IDF's `handle_ws_control_frames`
  enabled, and every frame is parsed there: the payload read
  happens only when the frame length is non-zero, the opcode is classified by our code,
  and anything unparseable closes the socket. Client frames never go back through
  `esp-idf-svc`'s `conn.recv()`. In exchange the handler answers PING with PONG and CLOSE
  with CLOSE, and a client slot is released by the CLOSE frame. The external defects this
  avoids are recorded under the workarounds in
  [`known-issues.md`](../product-design/known-issues.md).

## Logging never waits

- A producer reserves one slot of a bounded PSRAM queue with a single `compare_exchange`,
  formats into that slot and publishes it with one release store. Some slots are held
  back for WARN and ERROR. A full queue, or a reservation lost to other producers after
  a bounded number of attempts, drops the line and counts it.
- One writer task on core 1, with its stack in PSRAM, is the only caller of the blocking
  `uart_write_bytes`; it parks on its inbox and feeds the UART driver's TX ring. The
  VFS UART path is not used: it costs a lock and a ring send per byte.
- A Rust panic drains the queue through `esp_rom_printf`.
- If the queue or the writer cannot be created, neither the hook nor the facade is
  installed and the board keeps the ROM console: degraded, never aborted. The
  `console_log_unavailable_total` counter says so.
- Queue, truncation, unavailable and UART-error counters are on `/api/v1/stats`.
- The capture path reaches the log history ring (the WebSocket `logs` channel) only
  through `log_ring::try_global`: `global()` builds the ring through `PsramBox`, which
  logs when PSRAM falls back to internal, so a capture there would re-enter the
  initializer and deadlock.

## No long spinlock holds while the wire is live

- A spinlock held longer than about one tick delays every task that wants it, the
  sniffer staging an arbitration answer included.
- So nothing at runtime walks the kernel or the heap: no `uxTaskGetSystemState`, no
  `heap_caps_get_info`, `heap_caps_get_largest_free_block` or `multi_heap_get_info`.
  Largest-block figures are taken at boot stages only
  (`EspHeapStats::boot_snapshot`) and later snapshots repeat them.
- The task census reads the BSP task registry and asks `uxTaskGetStackHighWaterMark` per
  handle. Threads register as they start and leave as they exit; the kernel's own
  process-lifetime tasks are re-resolved by name on every census; transient tasks
  (`httpd`, `mqtt_task`) publish their own watermark with an instance id and a timestamp,
  so no handle is dereferenced after its task may have died. The table is released
  before the census line is formatted.
- The heap line and the census run once a minute on core 1, away from the interrupt.

## Bus lifetime

- A `BusHost` owns the bus. Dropping it sets a shutdown flag and joins the routing task,
  which drops the subscriber senders it owns; every worker's `recv` then reports
  `Disconnected` and the worker exits.
- A test harness therefore owns its `BusHost` for as long as it publishes.
- `dali2rust-adapters/tests/stack_teardown.rs` counts threads across repeated
  build-and-drop cycles.

## Panics on the device

- The firmware builds `std` with `panic_abort`: a panic resets the chip.
- The flashed image is the dev profile, with debug assertions on in every crate but
  `dali2rust-dali-phy`, so a `debug_assert!` on a device path resets the chip like a
  panic. An outcome the wire can produce is mapped to a defined value, never asserted.
- Lock poisoning needs an unwinding panic, so it cannot happen on the device.
  `PoisonError` recovery helpers run only in host builds, where they keep one panicking
  test thread from cascading into unrelated failures. Poisoning is not a device failure
  mode.
- Code reachable from a client fails soft: fallible spawns, a closed socket on a bad
  frame, an error response on bad input.

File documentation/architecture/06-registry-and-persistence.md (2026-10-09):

# 06 Registry and Persistence

How the registry holds the controller's state, who may change it, how DALI facts become
runtime state, and how configuration survives a reboot.

Scope: registry ownership and locking, the runtime update path and its merge rules, the
slice store and hydration. Terms (physical device, virtual lamp, binding, …) are defined
in [`glossary-and-invariants.md`](../product-design/glossary-and-invariants.md); the
registry's REST resources in [`../product-design/rest-api/`](../product-design/rest-api/README.md);
flash access discipline in [08](08-dali-phy-and-transport.md); record placement and the
httpd stack in [07](07-memory-and-cores.md).

## Ownership and locking

- The registry state is one `RwLock` inside `RegistryStore`
  (`dali2rust-registry-runtime`), shared as an `Arc`.
- The registry worker is its **single writer**. One funnel inbox carries the routed
  registry commands and the DALI evidence events the registry projects, so every write
  runs on that thread. A write window is an in-memory mutation; the lock is released
  before anything is published. No second thread writes.
- Single-writer is what makes the flush safe. The persistence flush streams slices to
  flash while holding the **read** lock. The standard library's `RwLock` on this target
  prefers writers — a queued writer parks new readers — but the only thread that could
  queue a write is the one flushing, so readers keep sharing the lock; commands and
  events wait in the inbox.
- Everyone else reads through `RegistryReadPort` and the narrower read-port traits of
  `dali2rust-domain`. A read takes the lock and returns an owned view; no mutable
  reference or write method is reachable through a port. HTTP reads go through the
  bridge traits wired in composition; mutating routes poll lock-free apply and patch
  watches after their confirmation.
- The full `PhysicalDeviceView` is an inherent method of `RegistryStore`, on no port
  trait, so a handler holding a read port cannot build it.

## Runtime state

- Runtime fields — power, level, colour, status and failure flags, `last_seen_ms`, the
  last DAPC source, the `last_active_level` shadow — live on the physical-device record;
  virtual-lamp state is a projection through the binding.
- They change only through `RegistryRuntimeUpdateCommand` (RRUC) and
  `RegistryLevelTransitionCommand` (an observed arc command without a level, whose level
  the registry computes); in production the state-fanout projector is their only
  publisher. An entry that names a
  virtual lamp with no binding is refused (`VlUnbound`).
- Every successful runtime commit publishes `RuntimeStateChangedEvent` carrying the
  committed observation; an empty or default payload is forbidden.
- Runtime fields are not persisted, and neither is operation status. After a reboot
  they converge through reads (poller, attribute reads) and observed frames.

### Update path

1. `DaliWorker` publishes typed facts: the applied target state, the runtime-status part
   of an attribute read, a scene recall. The sniffer translator publishes observed
   foreign frames.
2. The projector resolves scope through `ProjectorReadPort` — group membership, scene
   rows, bindings — and publishes RRUC, or `RegistryLevelTransitionCommand` for an
   observed arc command without a level.
3. The registry worker commits and publishes `RuntimeStateChangedEvent`.

- A single-target fact keeps the request's correlation id to the end, so the registry
  confirms after the commit: confirmed means committed. Fan-out entries (group members,
  scene rows), sniffer facts, read results and absence observations carry
  `CORRELATION_NONE` and are never confirmed: nobody waits for them, fan-out cannot flood
  the confirmations channel, and a borrowed correlation would turn a delivery rejection
  into the failure of someone else's operation.
- Group and scene apply diffs are expanded by the apply orchestrator from a registry
  snapshot ([ADR-007](decisions/ADR-007-apply-orchestrator.md)), never by the registry.

### Merge rules
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

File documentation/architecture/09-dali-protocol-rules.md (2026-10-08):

# 09 DALI protocol rules

The IEC 62386 rules the DALI executor keeps when it builds frame sequences, reads answers
and shares the bus with other masters. Each rule is stated here once; the decision behind
it, where one was taken, is in the linked ADR.

Scope: what goes on the wire and how answers are read, above the PHY. The interrupt, the
transport and flash → [08](08-dali-phy-and-transport.md); what the product does not
implement → [conformance gaps](../reference/iec62386-conformance-gaps.md). The standards'
PDFs and the DiiA(SW)098bp digest are kept locally, outside the repository.

## Product path and diagnostic path

- Product modules publish semantic commands (typed `CommandEnvelope`s) and never
  assemble opcodes or frames. `DaliCommandPayload` (raw mode on `/api/v1/dali/raw`) is
  published only by the diagnostic `/api/v1/dali/*` routes and is never mapped onto
  physical devices or virtual lamps.
- Types hold the split: product code depends on `DaliProductController`; only the worker
  and diagnostics use `DaliApplicationController`, which adds `send_raw`.
- A 24-bit Part 103 frame is its own payload shape, worker branch and
  `DaliTransport::exchange_frame24`, never an overload of the 16-bit `wire_address` +
  `command` pair.

## Priority and yielding

- Priority comes from the command kind, never the opcode. `WIRE_CLASSES`
  (`dali-runtime/src/runtime/priority.rs`) has one row per command the worker handles,
  no default, and a test fails for a missing row: `WirePriority`, `YieldGranularity`,
  whether the kind drives a lamp, and the 103 §9.13.1 class of its opening frame (policy
  implementing a "should"; each row cites its clause). Only the diagnostic path refines
  the class from the opcode
  ([ADR-013](decisions/ADR-013-wire-priority-and-yield-granularity.md),
  [ADR-017](decisions/ADR-017-dali-transactions-and-frame-priority.md)).
- The class follows purpose: switching, dimming, identification, feedback drive, the
  Part 303 occupancy-sensor instructions and every commissioning kind (discovery, addressing, replacement, handover, the Part 103 scan and
  commissioning) open at priority 2, which §9.13.1 also allows for commissioning;
  configuration writes and group and scene programming at 3; an HCL setpoint at 4;
  attribute and memory-bank reads and both probes at 5 (the arbitration probe by DiiA 351
  §7).
- `WirePriority` says who is waiting: `Interactive` (a caller holds the HTTP task),
  `Attended` (answered `202` + operation id; someone watches), `Unattended` (nobody).
  A lease is revoked only by a strictly higher arrival. `Origin` refines only kinds whose
  producers answer differently: a poller read is `Unattended`, HCL and Home Assistant
  light commands are `Attended`, a rule's are `Interactive`.
- `YieldGranularity` says where a sequence may stop: `Frame` for reads, `Step` for
  configuration writes (`write-attributes`, Part 103 instance and feedback configuration)
  at a confirmed DTR → SET → read-back boundary, `Never` for discovery, commissioning and
  other units whose interruption leaves gear half-programmed.
- Background work never delays an operator, and that is not a setting: a quiet window,
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

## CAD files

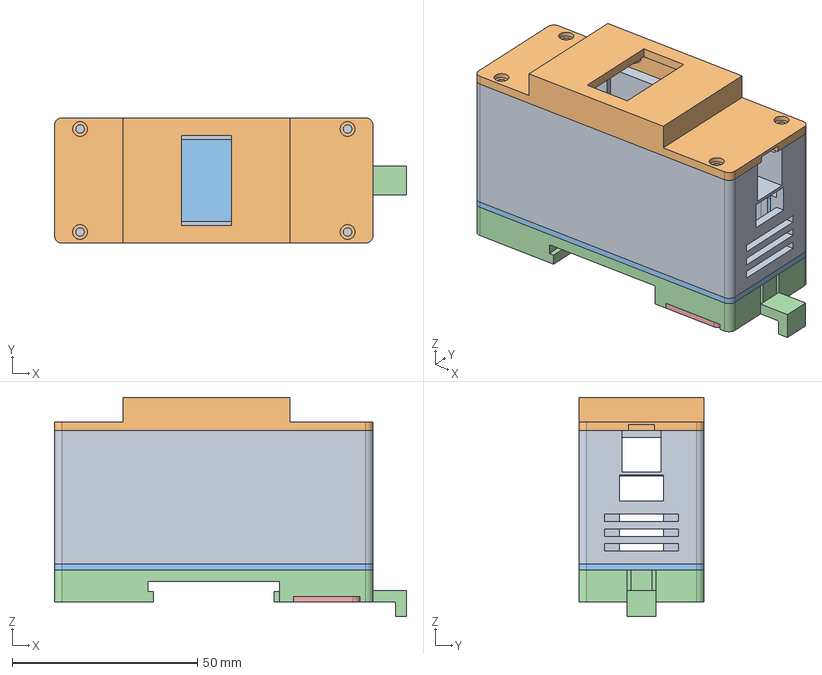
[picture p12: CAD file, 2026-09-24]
hardware/enclosure/export/assembly.step
95.0 x 33.8 x 59.2 mm
Base
Lid
BackCover
DinMount
Retainer

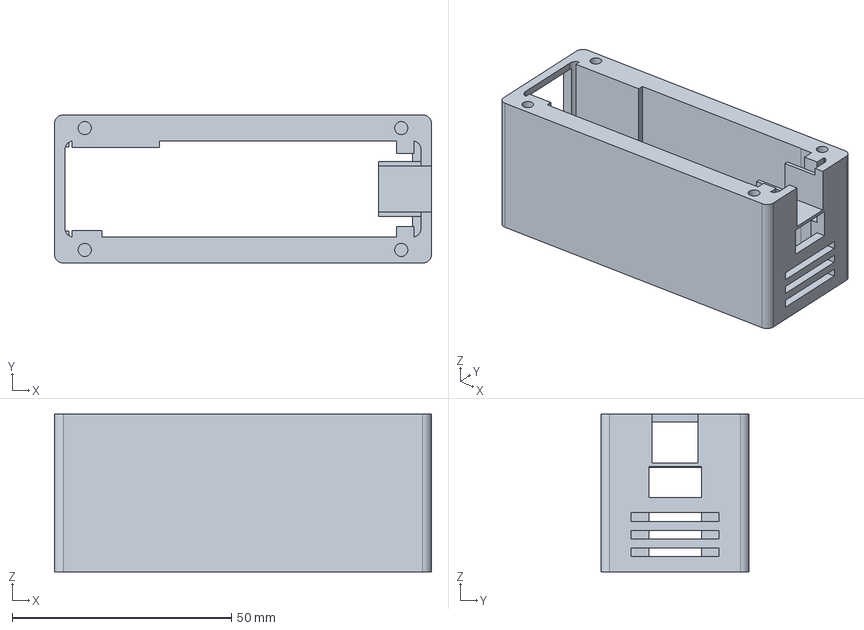
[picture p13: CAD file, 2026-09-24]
hardware/enclosure/export/case-body.step
86.0 x 33.8 x 36.0 mm

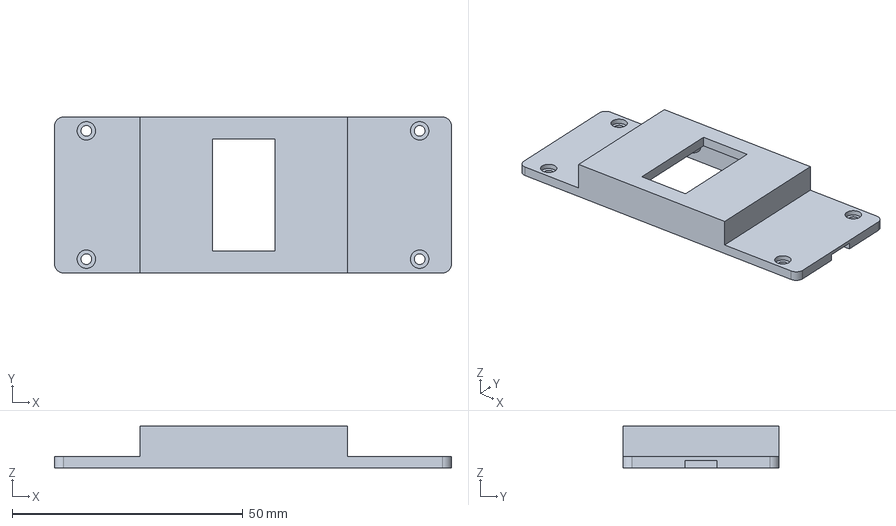
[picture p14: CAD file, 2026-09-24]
hardware/enclosure/export/case-lid.step
86.0 x 33.8 x 9.00 mm

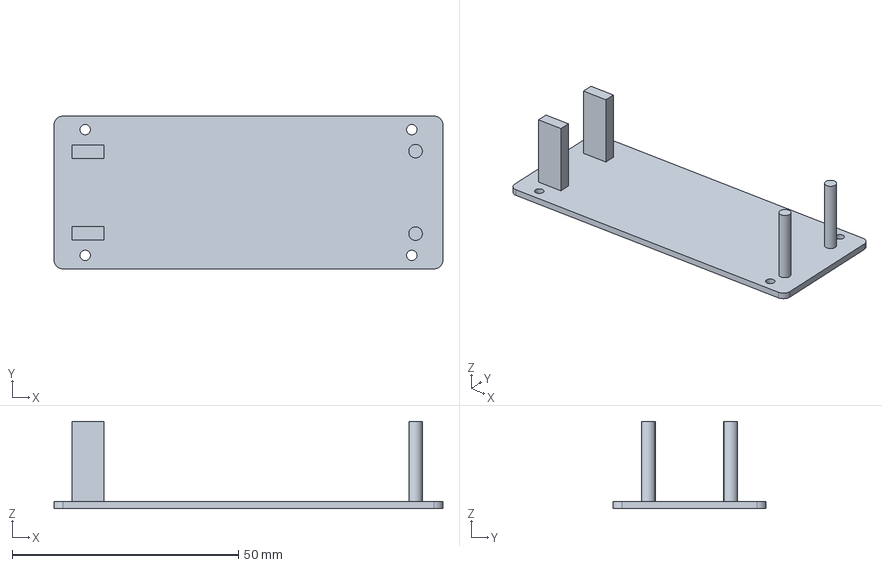
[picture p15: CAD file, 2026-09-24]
hardware/enclosure/export/case-back.step
86.0 x 33.8 x 19.3 mm

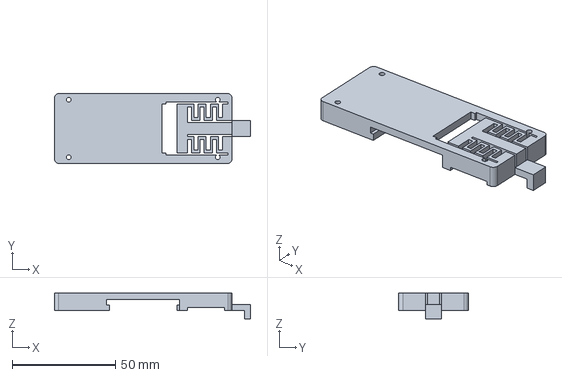
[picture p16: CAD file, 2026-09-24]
hardware/enclosure/export/din-mount.step
95.0 x 33.8 x 12.6 mm

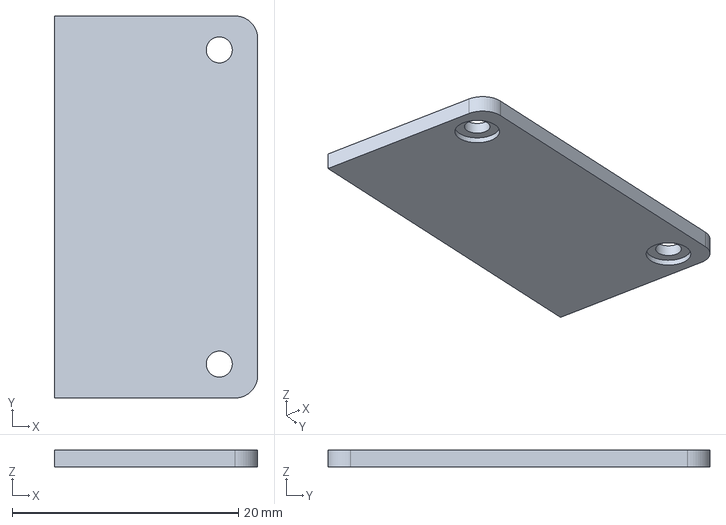
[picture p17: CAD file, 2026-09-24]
hardware/enclosure/export/din-retainer.step
18.0 x 33.8 x 1.50 mm

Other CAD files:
hardware/enclosure/dali2rust-case.FCStd
hardware/enclosure/export/assembly.3mf
hardware/enclosure/export/case-back.3mf
hardware/enclosure/export/case-back.stl
hardware/enclosure/export/case-body.3mf
hardware/enclosure/export/case-body.stl
hardware/enclosure/export/case-lid.3mf
hardware/enclosure/export/case-lid.stl
hardware/enclosure/export/din-mount.3mf
hardware/enclosure/export/din-mount.stl
hardware/enclosure/export/din-retainer.3mf
hardware/enclosure/export/din-retainer.stl

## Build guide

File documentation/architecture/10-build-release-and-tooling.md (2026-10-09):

# 10 Build, release and tooling

How the workspace is built, versioned, configured and flashed, and which gates a change
passes before it merges.

Scope: toolchain, cargo configuration, the justfile, the firmware image (version, knobs,
sdkconfig, partitions), the web UI chain, merge gates and the comment policy. Test and
BDD conventions → [05](05-testing-and-bdd.md); updates over the network →
[ADR-024](decisions/ADR-024-ota-over-ethernet.md); the bench runbook →
[`tools/hil/README.md`](../../tools/hil/README.md).

## Toolchain and cargo

- `rust-toolchain.toml` pins one upstream nightly for every build, host builds included,
  with `rust-src`, which `[unstable] build-std` needs to build `std` for the tier-3
  target `riscv32imafc-esp-espidf`; `rustup toolchain install` installs it with its
  components. bindgen takes libclang from the ESP-IDF tools the first firmware build
  installs.
- No workspace `[build] target`, and every build and alias names its triple — an alias
  without one builds a second copy of the workspace into `target/debug` (the cargo
  limitations behind this: [ISSUE-147](../product-design/known-issues.md)). The aliases
  are `cargo fw` (build), `cargo flash` (build, flash with `espflash` and
  `partitions-p4.csv`, monitor) and `cargo bdd`. The host triple is literal in
  `[alias]` and in the justfile's `default_host`; another host edits both.
- `[env]` forces `MCU = esp32p4` and `ESP_IDF_SDKCONFIG_DEFAULTS = sdkconfig.p4.defaults`
  (`force = true`): otherwise a variable already in the shell wins, and a stale one builds
  for the wrong die. `ESP_IDF_SYS_ROOT_CRATE` (the crate being built),
  `ESP_IDF_VERSION` and `ESP_IDF_TOOLS_INSTALL_DIR` stay overridable. `hil flash` reads
  that block line by line, so each entry stays on one line as `KEY = "value"` or
  `KEY = { value = "…", force = true }` with `value` first.
- `--cfg espidf_time64` matches the `libc` crate's `time_t` to ESP-IDF 5's 64-bit one.
- ESP-IDF is pinned to v5.5.3: `esp-idf-hal` 0.46.2 does not compile against v5.5.5, and
  `embuild` below 0.33.2 cannot parse its tool list. Move it between bench experiments,
  never inside one.

## justfile

| Group | Recipes |
| --- | --- |
| Host | `check`, `test` (`--all-targets` over `scripts/host_crates.txt`, so no doc-tests), `quick <crates…>` (check all, test the named crates and BDD), `clippy` (`-D warnings`), `clippy-pedantic-advisory`, `fmt` (manual; rustfmt is no gate — wrap only lines you touch) |
| BDD | `bdd` (`bdd_shards=N` over N processes), `bdd-check`, `bdd-stage`, `check-stage-clean` |
| Gates | `verify`; `ci` = clippy, test, bdd, verify, `esp-check`, `gear-sim-check`; `contracts-check`; `verify-release` (the maintainer's sync state: UI bundle, pushed cards) |
| Firmware | `esp-check` (`cargo check` on the P4 triple), `p4-fw-build`, `p4-isr-iram-check`, `p4-fw-flash` |
| Other | emulator `gear-sim-check` / `gear-sim-isr-iram-check`; `gc`, `gc-status`; `hil-preflight`, `hil-smoke`, `hil-default`, `hil-slow` |

- `just ci` before a commit lands and after anything that moves a contract, a wire order
  or ESP-only code; `just quick` is the inner loop. `ci` never links the firmware.
- `check` and `clippy` cover test targets too, because test doubles are what breaks
  unseen. There is no destructive HIL recipe: that tier runs one test at a time, by hand.
- Host test time is launch time, not test time: `just gc` sweeps stale `.o` files and
  `just gc-status` counts them (the macOS mechanism: ISSUE-147).
- The `p4-fw-flash` recipe names a local USB port; the installed boards are flashed with
  `hil flash` ([runbook](../../tools/hil/README.md#flashing)).

## Firmware version

- `crates/dali2rust-firmware/build.rs` derives `<major>.<minor>.<commit count>+<8-char
  sha>`, adding `.dirty.<MMDDThhmm>` (UTC) when tracked files differ from the commit and
  `.unknown` when `git status` fails; without git it is `0.1.0+unknown`. A clean build
  has no stamp, so a commit always rebuilds to the same version.
- `/api/v1/health`, `/api/v1/controller`, Home Assistant's `sw_version` and the boot log
  report it, threaded from the composition root through
  `build_router_with_bus_and_transport`; `hil flash` checks it against the image it wrote
  ([runbook](../../tools/hil/README.md#flashing)).
- Any `rerun-if-*` line replaces cargo's default, so the script declares its inputs: the
  firmware `src`; git `HEAD`, branch ref, `packed-refs` and `logs/HEAD` (via
  `git rev-parse --git-path` for worktrees, and only if they exist — a missing path
  counts as changed); and `crates`, `Cargo.toml`, `Cargo.lock`, `.cargo/config.toml`,
  `sdkconfig.p4.defaults`, which `.dirty` speaks for.

## Build-time knobs

Read with `option_env!`, which records each name in the crate's dep-info; cargo rebuilds
the crate when one changes, so a knob needs no build-script edit. A flag knob is `1` or
`0` (unset or empty keeps its default); any other value fails the build (`flag_knob`).
`hil flash` builds for itself: pass knobs to it, and check the flip reached the binary.

| Knob | Effect |
| --- | --- |
| `DALI2RUST_DALI_RETRY_MAX_ATTEMPTS`, `_BACKOFF_MS`, `_JITTER_MS` | Unit retries and backoff after `Collision` / `BusBusy` / `ForeignInWindow` |
| `DALI2RUST_DALI_QUERY_CONTENTION_RETRY` | Retry a query's `NoAnswer` when foreign activity was seen; `hil flash` requires `1` |
| `DALI2RUST_DALI_QUERY_CONTENT_CONFIRM`, `_MAX_SAMPLES` | Bounded re-reads of contended idempotent queries; `hil flash` requires `1` |
| `DALI2RUST_DALI_DISCOVERY_STEP_RETRIES` | Discovery verify and random-address retries |
| `DALI2RUST_DALI_TARGET_SEQUENCE_RETRIES` | Re-runs of a target-state sequence after `bus_contended` |
| `DALI2RUST_PHY_ISR_LEVEL` | `3`, `4`, `5` (default): PHY interrupt level; `3` is the driver rollback path |
| `DALI2RUST_PERSIST_DISABLE` | `1`: no slice store — no flash writes, no hydration; diagnosis only |
| `DALI2RUST_HEAP_CHECK_S` | Heap-integrity sweep period from the heartbeat; absent or `0` = off |
| `DALI2RUST_STACKS_INTERNAL` | `1`: every stack that would be in PSRAM on the XIP image stays internal, httpd reserve included ([ADR-028](decisions/ADR-028-task-stacks-in-psram-on-the-xip-image.md)) |
| `DALI2RUST_ETH_RX_INTERNAL` | `1`: received frames stay in the EMAC driver's internal buffer instead of a PSRAM copy ([ADR-029](decisions/ADR-029-network-buffers-in-psram-and-a-measured-receive-ring.md)) |
| `DALI2RUST_RUST_HEAP_INTERNAL` | `1`: Rust allocations keep ESP-IDF's internal-first placement instead of PSRAM from 256 B ([ADR-028](decisions/ADR-028-task-stacks-in-psram-on-the-xip-image.md)) |
| `DALI2RUST_PSRAM_ATOMIC_SELFTEST` | `1`: at boot both cores race atomic increments on one PSRAM word and log `psram atomics self-test: ok` or `FAILED` |
| `DALI2RUST_ESP_VERBOSE` | Verbose ESP-IDF component logs |

## sdkconfig.p4.defaults

The only baseline. The generated
`target/riscv32imafc-esp-espidf/debug/build/esp-idf-sys-*/out/sdkconfig` is the authority
(Kconfig may clamp silently), and a change is proven only by a flash: a wrong value can
abort the boot where no `cargo check` sees it. Experiments layer on top
([`sdkconfig.experiments/`](../../sdkconfig.experiments/README.md)).

| Key | Value | Why |
| --- | --- | --- |
| `PARTITION_TABLE_CUSTOM_FILENAME` | `../../../../../../partitions-p4.csv` | relative to esp-idf-sys's CMake project dir |
| `ESP32P4_SELECTS_REV_LESS_V3` | `y` | the dies are revision v1.3; without it the image will not boot below v3.0 |
| `SPIRAM_MALLOC_ALWAYSINTERNAL` | `16384` | smaller allocations stay internal ([07](07-memory-and-cores.md)) |
| `SPIRAM_XIP_FROM_PSRAM` | `y` | flash writes open no cache-off window ([ADR-025](decisions/ADR-025-phy-interrupt-above-critical-sections.md)); costs a boot copy and ~4,5 MB of PSRAM |
| `SPIRAM_TRY_ALLOCATE_WIFI_LWIP` | `y` | lwIP's pbufs, segments and control blocks come from PSRAM first; the EMAC DMA ring is allocated internal by the driver whatever this says ([ADR-029](decisions/ADR-029-network-buffers-in-psram-and-a-measured-receive-ring.md)) |
| `MBEDTLS_EXTERNAL_MEM_ALLOC` | `y` | a TLS session's buffers (16 KiB in, 4 KiB out) live in PSRAM; ESP-IDF's default puts them in internal SRAM |
| `MQTT_USE_CUSTOM_CONFIG`, `MQTT_OUTBOX_DATA_ON_EXTERNAL_MEMORY` | `y` | messages the broker has not acknowledged wait in PSRAM; the custom block's other defaults equal the built-in ones |
| `ETH_RMII_CLK_INPUT`, `_CLK_IN_GPIO` | `y`, `50` | the PHY feeds REF_CLK into GPIO50 |
| `ETH_DMA_BUFFER_SIZE`, `ETH_DMA_RX_BUFFER_NUM`, `ETH_DMA_TX_BUFFER_NUM` | `768`, `30`, `15` | a full frame in two descriptors: 15 full frames or 30 small ones on receive, 34.5 KB internal; sized against `network.rx_ring_overruns_total` ([ADR-029](decisions/ADR-029-network-buffers-in-psram-and-a-measured-receive-ring.md)). Kconfig takes 3–30 buffers per ring and 256–1600 bytes, 64-aligned on the P4, and replaces a value out of range with its default without a word |
| `ETH_TRANSMIT_MUTEX` | `y` | one mutex against silent frame corruption when several tasks transmit |
| `LWIP_STATS` | `y` | the httpd slow-socket line reads lwIP's TCP and link counters to tell "sent and lost" from "never sent" |
| `LWIP_TCP_SND_BUF_DEFAULT`, `_WND_DEFAULT` | `23040` | 16 × MSS keeps fast retransmit reachable; no window scaling on a wired LAN; the buffers are in PSRAM ([ADR-029](decisions/ADR-029-network-buffers-in-psram-and-a-measured-receive-ring.md)) |
| `LWIP_TCP_RECVMBOX_SIZE` | `18` | window / MSS + 2: a smaller mailbox refuses the rest of the window and the sender waits for a retransmit |
| `LWIP_TCP_OOSEQ_MAX_PBUFS` | `4` | out-of-order segments held per connection; with lwIP in PSRAM ESP-IDF's default would be unbounded |
| `LWIP_MAX_SOCKETS` | `16` | ≥ httpd's `max_open_sockets` ([02](02-runtime-and-threading.md)) + its 3 internal descriptors, or `httpd_start` fails and the boot aborts |
| `FREERTOS_HZ` | `1000` | short sleeps park instead of spinning ([02](02-runtime-and-threading.md)) |
| `ESP_MAIN_TASK_STACK_SIZE` | `12288` | `main` runs the composition boot and returns; the heartbeat runs on the census thread, and `main`'s stack is freed |
| `ESP_SYSTEM_EVENT_TASK_STACK_SIZE` | `3072` | the event loop task runs the Ethernet and IP handlers, well under a kilobyte deep |
| `ESP_COREDUMP_ENABLE_TO_UART`, `FREERTOS_WATCHPOINT_END_OF_STACK` | `y` | post-mortem ([debugging](../reference/debugging.md)) |
| `HTTPD_WS_SUPPORT` | `y` | without it `/api/v1/ws` is not a WebSocket route |
| `HTTPD_QUEUE_WORK_BLOCKING` | unset (off) | the WebSocket handler queues socket closes from the httpd task itself; a blocking queue would wait on its own task |
| `GPTIMER_ISR_CACHE_SAFE` | `y` | the level-3 rollback's driver alarm keeps firing with the cache off |
| `ESP_PANIC_HANDLER_IRAM` | `y` | a panic with the cache off still prints instead of a bare watchdog reset |
| `BOOTLOADER_APP_ROLLBACK_ENABLE` | `y` | an image that never marks itself valid is rolled back; a DEBUG-level bootloader does not fit below `0x8000` |

## Partitions (`partitions-p4.csv`)

| Name | Offset | Size | Rule |
| --- | --- | --- | --- |
| `nvs` | `0x9000` | 64 KB | never initialised ([08](08-dali-phy-and-transport.md)) |
| `otadata` | `0x1A000` | 8 KB | below 16 MB, or the bootloader ignores it |
| `ota_0`, `ota_1` | `0x20000`, `0x620000` | 6 MB each | below 16 MB, or an update started from the slot faults; empty `otadata` boots `ota_0` |
| `storage` | `0xC20000` | 4 MB | persistence slices; never moves (that orphans every virtual-lamp binding) |

There is no `phy_init`: the board has no radio, and ESP-IDF 5.5.3 registers its PHY
component without sources on the ESP32-P4 (`components/esp_phy/CMakeLists.txt`), so nothing
looks the partition up; an ESP-IDF move re-checks that file. Nothing executable or
selectable goes above `0x1020000`. `esp_ota_begin` refuses an image larger than a slot.
Changing the table takes a wired flash.

## Embedded web UI

- The UI ships in flash: `bash scripts/build_web_ui.sh` builds and gzips `web/app` into
  `crates/dali2rust-firmware/assets/web/` (committed, so `cargo fw` needs no Node). A pull
  request carries sources only; the maintainer rebuilds the bundle when syncing a release.
  `scripts/verify_web_mirror_fresh.sh` compares it with `web/app`: `hil flash` refuses a
  stale bundle (`--allow-stale-ui` builds with the previous one), and `just
  verify-release` and an advisory CI job on `main` report it. The product-name table (`dali-products.json`) ships empty; a gitignored
  `crates/dali2rust-firmware/assets/local/dali-products.json.gz` replaces it in the image
  when present. A new bundle file needs a row in the firmware's `src/web_assets.rs` (or
  the fallback silently serves `index.html` in its place), in `MANIFEST_FILES` of
  `build_web_ui.sh` and in the host dev server's `asset_route` and `load_web_assets`; no
  gate checks the dev server's copies.
- `/assets/*` is served immutable for a year and `index.html` no-cache, so the
  `?v=<bundle hash>` that `build_web_ui.sh` stamps on every `/assets/` reference is the
  bundle's only freshness mechanism.
- Every bundle file is stored gzipped and always served as stored, with
  `Content-Encoding: gzip`, whatever the request's `Accept-Encoding`.
- `scripts/web_ui_sources_fingerprint.sh` fingerprints the `web/app` source set (sources,
  `public/`, the entry HTML, the lockfile, the TypeScript and Vite configs):
  `build_web_ui.sh` records it beside the bundle and `verify_web_mirror_fresh.sh` compares.
- Every screen and component has a card in `web/design-system/`, written in the same
  change as the UI, with the `:root` block of `web/design-system/tokens.css` inlined
  verbatim. A change to screens, components or `app.css` that leaves the look as it was
  carries the commit trailer `UI-Design: unchanged` instead. The design language the
  cards and the app share is in [`web-ui/README.md`](../product-design/web-ui/README.md).
- A card is changed in place to show the design as it is: its body is the current look
  and it keeps, in the present tense, why the design is so; why it changed, what it
  replaced and when go in the commit, never in the card.
- The maintainer pushes the cards, when syncing, to the Claude Design project "dali2rust Web UI"
  (`0f3fcd66-9619-445b-b9bc-51bc578eefd9`) with `DesignSync`: `list_files` / `get_file`
  first (the owner edits there; never replace the project), `finalize_plan` (`deletes:
  []`), `write_files` with `localDir = web/design-system`, then
  `scripts/verify_design_system_pushed.sh --stamp` — only after the write succeeded.

## Merge gates (`just verify`)

A missing tool fails its gate (`DALI2RUST_SKIP_JSCPD=1`, `DALI2RUST_SKIP_TSC=1` are the
explicit opt-outs), and no gate keeps its own crate list. The `scripts/*budget*.txt`
files only go down; the function-length and clone gates fail on a budget file that is
missing, empty or not an integer, and on a count below their budget. The bench's own
budgets are in the [HIL runbook](../../tools/hil/README.md). The interrupt's flash check needs a linked
image, so it is not here, nor in `just ci`: `p4-isr-iram-check` fails on a red or
unchecked image, and `hil flash` refuses one unless told `--allow-red-isr`.

- A new host-buildable crate is added to `scripts/host_crates.txt` only — the one list
  that `just check` / `test` / `clippy`, the pedantic advisory and every gate with a crate
  scope read, the scripts through `host_crates.sh` and `host_crates.py`. The ESP-only
  firmware crate and the BDD crate stay out of it, named in the workspace manifest's
  `[workspace.metadata.dali2rust] not_host`; `host_crates.py` fails when the list and the
  workspace members disagree.
- The 40-line rule is measured on production code: `verify_fn_length.sh` runs clippy on
  `--lib` targets, so unit-test modules, integration tests and the BDD crate are outside
  it. `verify_fn_length_esp.py` finds ESP-only code by the literal
  `target_os = "espidf"` in a file, by `#[cfg(target_os = "espidf")] mod name;` on its
  declaration, by the `esp_idf.rs` / `esp_ws.rs` file names, or by the firmware, BSP and
  gear-emulator (`tools/dali-gear-sim/src`) paths; a module gated any other way is
  measured by neither gate.

| Script | Holds |
| --- | --- |
| `verify_contracts_codegen.sh` → `verify_native_contracts.sh` | `msg/` + `postcard` only; no FlatBuffers or byte round-trip builders |
| `verify_docs.py` | every markdown link resolves; size caps (`scripts/doc_size_caps.txt`); no dated text; no passage of 40 words repeated between documents |
| `verify_issue_ids.py` | every issue number cited in a tracked or new text file or file name — `ISSUE-NN`, `issueNN` in an identifier — resolves to one issue-registry row, and only the registry cites a closed one |
| `verify_bdd_ids.sh`, `verify_bdd_coverage.sh` (+ tree policy, `verify_bdd_stages.py`), `verify_bdd_layers.sh`, `verify_no_bdd_production_hooks.sh`, `verify_test_layers.sh` (+ `verify_duplication.sh`) | [05](05-testing-and-bdd.md) |
| `verify_runtime_boundaries.sh` | no `#[path]` in a host crate, the firmware, the BDD crate or the gear emulator; fixed composition file set |
| `verify_fixed_bus_guardrails.sh` | no `String`/`Vec`/`serde_json::Value` in bus messages, no JSON in registry state; no crate but `dali2rust-api` lists `serde_json` outside its dev-dependencies |
| `verify_comments.py` | no comment outside the one-line markers; budget `scripts/comment_budget.txt` |
| `verify_imports_at_module_level.py` | no `use` inside a function body, over the same trees as `#[path]` |
| `verify_web_assets.sh` | every embedded file present, `tsc -b`, UI tests |
| `verify_web_classes_styled.py` | every `web/app` class has a CSS rule |
| `verify_design_vocabulary.py` | every card's `:root` is the one in `tokens.css`; every class a card uses has a rule; a card's only dates are ones its mocked UI shows, each with its time, and none in a comment; `web/app` speaks card vocabulary |
| `verify_ui_follows_design.sh` | a visual `web/app` change since `origin/main` changes a card, or declares `UI-Design: unchanged` |
| `verify_fn_length.sh`, `verify_fn_length_esp.py` | no function over 40 lines, host and ESP-only code |
| `verify_counter_surface.py` | counter names agree across spellings ([04](04-contracts-and-api-bridge.md)) |
| `verify_read_surface.py` | every read-payload block reaches a screen: rendered, or the clock its delta column keys on |
| `verify_rest_docs.py` | every route the router serves and every error code the API answers is named in a REST resource document, and every documented route is served |

## Comments

- Source comments are banned except one-line markers: `// SAFETY:` (and `/// # Safety`
  plus one line on a public `unsafe fn`), `// sleep-ok:`, `// busy-wait-ok:`, a BDD
  step's `// <ID list>`, and a citation such as `// IEC 62386-102 §9.4`. Tool directives
  pass too: a shebang, `# shellcheck …`, a Gherkin `# language:`, sdkconfig's
  `# CONFIG_… is not set` and `// @ts-expect-error`.
- Rationale lives in this directory and the ADRs; a workaround for an external defect in
  [`known-issues.md`](../product-design/known-issues.md).
- An `#[allow(…)]` carries `reason = "…"` instead of a comment; `just clippy` denies one
  without it, and an `unsafe` block without `// SAFETY:`.
- `scripts/verify_comments.py` enforces it; `--strip <paths>` removes violations and
  leaves a file alone if its tokens would change. A branch that conflicts with the strip
  takes its own version and re-runs `python3 scripts/verify_comments.py --strip <paths>`.

## Beside the workspace

- [`tools/dali-gear-sim`](../../tools/dali-gear-sim/README.md), the gear emulator for the
  pair's second ESP32-P4, is its own cargo workspace, layered on the root's sdkconfig and
  partition table; its README states what `gear-sim-check` and `gear-sim-isr-iram-check`
  prove ([ADR-014](decisions/ADR-014-gear-model-and-second-dali-endpoint.md)).
- `hardware/enclosure/` models the DIN-rail enclosure; the `Params` spreadsheet in
  `dali2rust-case.FCStd` is its source of dimensions.

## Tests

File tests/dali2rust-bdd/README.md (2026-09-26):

# dali2rust-bdd

Host-side [cucumber-rs](https://github.com/cucumber-rs/cucumber) suite: the product's
acceptance scenarios, run against the production composition with mock ports.

Scope: how to run the suite and where its parts live. The conventions (layers,
black-box boundary, tags, step traceability, gates) live in
[`documentation/architecture/05-testing-and-bdd.md`](../../documentation/architecture/05-testing-and-bdd.md);
ID prefixes in
[`documentation/product-design/bdd/ids-registry.md`](../../documentation/product-design/bdd/ids-registry.md).

## Layout

- `features/` — the Gherkin scenarios; `src/steps/` — the step definitions; how both
  are organised: *Feature tree* and *Step definitions* in `05-testing-and-bdd.md`.
- `src/main.rs` — the World and the runner. The stack is composed by
  `dali2rust-adapters::build_http_test_stack` over `MockDaliTransport`.
- `benches/` — a bus microbenchmark, not a behaviour test.

## Running

```bash
just bdd          # or: cargo bdd
just bdd-check    # ID and coverage gates, then the suite
```

- `ONLY_FEATURES=<substring>` runs only the feature files whose path contains the
  substring, for example `ONLY_FEATURES=pd-discovery just bdd`.
- `ONLY_STAGE=<stage>` (what `just bdd-stage R6` sets) runs the scenarios of one stage:
  a scenario's own `@stage-*` tag overrides its feature's.
- A process runs its scenarios one at a time. `just bdd_shards=4 bdd` splits the
  feature files over four processes, balanced by scenario count; `BDD_SHARD=<i>/<n>` is
  what each process reads. `just bdd` keeps one process unless told otherwise.
- The runner skips `@wip` scenarios. A cucumber `--name` or `--tags` filter replaces the
  harness filter (the `@wip` skip, `ONLY_FEATURES` and `ONLY_STAGE`), so a tag expression
  that should keep the skip says so:
  `cargo bdd -- --tags '(@id:PD-027 or @id:PD-028) and not @wip'`.
- The gates the suite answers to are listed in `05-testing-and-bdd.md`; all of them run
  in `just verify`.

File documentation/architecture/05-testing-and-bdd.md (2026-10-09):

# 05 Testing and BDD

How behaviour is proved in this repository: the test layers, the black-box BDD
boundary, and the conventions every scenario, step definition and test follows.

Scope: this is the single home of the testing conventions. The BDD prefix registry
lives in [`bdd/ids-registry.md`](../product-design/bdd/ids-registry.md), running the
suite in [`tests/dali2rust-bdd/README.md`](../../tests/dali2rust-bdd/README.md), the
bench suite in [`tools/hil/README.md`](../../tools/hil/README.md). The executable
features under `tests/dali2rust-bdd/features/` are the only BDD canon; there are no
design copies of scenarios.

## Layers

| Question | Layer |
| --- | --- |
| Pure logic, mapping, validation, codec edge case | Unit test (`#[cfg(test)]`) |
| One runtime slice on the real bus path | Crate integration test (`crates/*/tests/`) |
| Behaviour observable from the composed host stack | BDD (`tests/dali2rust-bdd`) |
| A web UI decision the device never sees (editor help, a screen's own state) | Node test over a pure module in `web/app/src/` (`web/app/tests/`, `npm test`) |

- Prove a behaviour at the **lowest layer that proves it without bypassing the
  production path**.
- A behaviour whose evidence is a bus payload field, the boundary of a worker cycle, a
  counter or a stub clock belongs in the owning crate's tests. A domain that needs
  registry seeding, bus taps or worker introspection moves there too; it never gets a
  BDD step file that reaches inside.
- Lower-level tests seed state through the production path: publish the event the real
  producer publishes and wait for the worker to project it, never write records
  directly. No `bdd` Cargo feature, no `pub fn bdd_*` hooks, no registry seed reach-in.
- What the host cannot model is proved on the HIL bench, which is not a merge gate
  ([`STRATEGY.md`](../../tools/hil/STRATEGY.md) §1).
- A web UI component only wires pure modules to the DOM and has no test of its own:
  logic that needs a test moves into a pure module first. What a screen relies on from
  the device is proved by BDD through the REST contract, never again by web UI tests.

## Rules for every test

- **Production builders and codecs only.** Requests, envelopes and frames come from
  `dali2rust-contracts` / `dali2rust-api` helpers (`command_envelope`,
  `parse_command_envelope`, `DaliCommandRequestBuffer`, …); never hand-rolled `postcard`
  bytes or manual re-serialisation.
- **Production composition only.** The stack under test starts through the same
  composition entry points as the firmware; mocks sit only at port boundaries; there is
  no alternate bus or HTTP implementation.
- **Take a field from its real producer.** When a consumer's behaviour depends on a
  field, at least one test obtains that field from the component that really emits it.
  A hand-built input proves the consumer and nothing about the producer.
- **Pin a decoder against foreign bytes.** A codec is tested against frames captured
  from real gear or produced by `dali2rust-gear-model`, not only against its own
  encoder: a round trip through one's own encoder shows only that two copies of one
  assumption agree.
- **Synchronise on predicates and deadlines**, never on sleeps: `wait_until`,
  `recv_with_deadline` and the counter waits of `dali2rust-test-support`. Integration
  tests and BDD never call `thread::sleep`; in crate sources every sleep carries a
  `// sleep-ok:` or `// busy-wait-ok:` marker naming the protocol timing it waits for.
- **Counters are `u32` and wrap**: assert an increment across a window, never an
  absolute value or monotonicity.
- **A negative assertion proves the stimulus arrived.** It is paired with a positive
  one showing the stimulus was processed, or it waits out at least one period of the
  producing worker's cadence; otherwise it passes before anything could have happened.
- **A counter nothing moved measured nothing.** A test that proves a mechanism shows
  that mechanism's counter moved; a run that leaves it at zero is inconclusive, not
  green.
- **A red test is fixed in the code**, never by loosening its assert.
- **A full ingress is held, not raced.** A test whose subject is a worker's publish
  meeting a full ingress holds the worker at its wire port, parks the bus router with
  the ingress full (`hold_the_events_ingress_full`) and releases both on predicates. A
  flood races the router, and no flooder count wins that race on every host. A test
  whose stimulus is its own refused publish publishes inside its own predicate
  (`publish_until_refused`).
- **Shared helpers live in `dali2rust-test-support`** (bus taps and frame builders,
  in-memory filesystem and slice store, waits). No per-crate copies and no new ad-hoc
  `*Harness` / `*TestStack` structs.
- **A bench fixture neutralises state it does not own**: it suspends what was already
  running (the bench's own schedules, for example) and restores it afterwards.
  Cleaning up only what the test created is not isolation. The bench's session-wide
  save and restore is a safety rule of [`STRATEGY.md`](../../tools/hil/STRATEGY.md) §4.
- No `assert!(true)` placeholders, and no tests for product targets that are not being
  implemented.

## BDD black-box boundary

Decided in [`ADR-004`](decisions/ADR-004-bdd-black-box-boundary.md).

- **Drive** the composed host stack through HTTP, through the WebSocket endpoint with a
  real client, and through the broker side of `MockMqttClient` when the MQTT surface is
  the feature under test. Foreign bus traffic enters through the transport's
  observed-frame seam (`MockDaliTransport::inject_observed_frame`), the same channel the
  hardware transport feeds.
- **Assert** only HTTP status and bodies, response DTOs, WebSocket frames, MQTT
  messages, frames recorded by `MockDaliTransport`, and effects visible at a mocked port
  such as the slice store.
- **Never** call into `BusStackRuntime` (the World may hold it only as an inert
  keep-alive), bus channels or publishers, `RegistryStore` or read ports, confirmation
  slots, or worker counters.

## Host models and the mock transport

- The control-device model keeps no clock; the gear fleet keeps only the time its driver
  passes in (`GearFleet::advance_to_ms`), which RANDOMISE's 100 ms settling alone reads.
  Fades are stored but instant; the send-twice 100 ms window, the identification and
  commissioning timers and the running of the Part 301/303 timers (their variables are
  modelled) are not simulated; neither are system-failure behaviour, memory-bank writes
  and the bank-1 lock, the xy gamut, or Part 302/304 instances. No host test proves any
  of them. A power cycle (`GearFleet::power_cycle`: power-on level, `powerCycleSeen`)
  is modelled, but only the model's own tests drive it.
- The gear model's bench-conformance allowlist (`KNOWN_DIVERGENCE`) is pinned to one
  corpus capture, never "the latest", and only shrinks: every entry states its reason,
  "not modelled yet" is not one, and an entry that no longer diverges is removed.
- The host stack serves one HTTP request at a time, like the device's single httpd task,
  so a request issued while another is blocked waits for it. A scenario orders
  concurrent work by parking a transport exchange (`the DALI transport parks the next
  exchange`), never with an HTTP barrier.
- A frame's priority is read from the settling the controller requested of
  `MockDaliTransport`, which maps to one Table 22 band — never from the gaps between
  recorded frames, which are host sleeps.
- A negative wire assertion reads the frames the mock recorded, never "the strict script
  was consumed": an exhausted script lets later frames through unanswered.
- `MockDaliTransport::clear()` drops the recorded frames and the queued, scripted and
  persistent answers but keeps the per-frame 24-bit answers (`clear_frame24_answers`
  drops those), so a scenario clears before it scripts, and clears both before scripting
  a new Part 103 walk.

## Writing scenarios

- **BDD-first.** New behaviour starts with a failing scenario; the change merges when
  the new and the existing scenarios pass. Production code that adds behaviour without
  a scenario is a merge blocker. Infrastructure-only changes (refactors, docs, CI) are
  exempt.
- **Prove the claimed profile, not only success.** A scenario that claims controller
  behaviour asserts the wire: the correct address byte for the command and the
  transport-visible frame order (for example the `ENABLE DEVICE TYPE` prelude before an
  extended command).
- **Assert whole contracts.** A scenario that checks a state DTO checks the whole
  contract [`state-contracts.md`](../product-design/rest-api/contracts/state-contracts.md)
  defines for it, not only the field the change touched.
- **Use the product vocabulary.** Scenarios name fields and values as the contracts do
  (`level`, never `brightness`, outside the MQTT / Home Assistant wire), and negative
  scenarios assert the stable codes of
  [`error-dto.md`](../product-design/rest-api/contracts/error-dto.md), never
  `internal_error` or an unlisted code.
- Gherkin, step text and step comments are English. Fixtures carry no real secrets.

## Feature tree

- `features/<resource>/`, one directory per REST resource, plus non-resource layers:
  `diagnostic/` (the low-level `/api/v1/dali/*` surface and `/api/v1/diagnostics`),
  `system/` (boot, health, composition and cross-resource integration), `contracts/`
  (HTTP → bus → wire contracts), and one directory per surface or mechanism no resource
  owns (`mqtt_home_assistant/`, `web_ui/`, `persistence/`, `poller/`).
- Directory names are snake_case. The allowed set is the list in
  `verify_bdd_tree_policy.sh`; a new resource adds its directory there. `dali/`, `bus/`,
  `display/` and `registry/` are forbidden, and an empty directory fails the coverage
  gate.
- Steps live in `src/steps/<domain>_steps.rs`, or in `src/steps/<domain>/` split by what
  they drive, with that domain's mock-transport scripts beside them; steps shared across
  resources live in `system_steps.rs`, `diagnostic_steps.rs` and `contracts_steps.rs`,
  and the operation-outcome steps in `operations_steps.rs`.
- Helpers several step files use sit in `src/steps/`: frame builders in `frames.rs`, HTTP
  polling in `polling.rs`, frame-order and priority assertions in `wire.rs`.

## Tags

| Tag | Rule |
| --- | --- |
| `@id:<PREFIX><NNN>` | On every scenario, unique across the tree. The prefix is registered in [`ids-registry.md`](../product-design/bdd/ids-registry.md); three digits and an optional lowercase variant letter follow it. |
| `@stage-<S>` | Exactly one before `Feature:`, naming the [roadmap](../product-design/roadmap.md) stage (`F*`, `R*`, `I*`, `X*`) that delivered the behaviour. A scenario adds its own only as an override for an outlier. The accepted values are the stages [`status.md`](../product-design/status.md) lists (`verify_bdd_stages.py`). |
| `@wip` | Unfinished scenario, skipped by the runner and removed as soon as it is green. Forbidden in a stage whose every row in [`status.md`](../product-design/status.md) reads `готово`. |
| `@flaky`, `@diagnostic` | Informational labels that neither the runner nor any gate reads. `@flaky` does not take a scenario out of the run and is not merged without a stated justification. |

A stage is complete only when every scenario tagged with it is green with no `@wip`;
`just check-stage-clean <S>` lists the `@wip` scenarios whose stage — their own tag, else
the feature's — is `S`. A status claim that cites `@id`s holds only if each of them exists
and passes.

## Step definitions

- Every `#[given]` / `#[when]` / `#[then]` has a traceability comment directly above
  it: `// <ID> <ID> …`, the `@id`s of every scenario that uses the step, separated by
  single spaces, nothing else on the line. Every ID named there must exist as an `@id`.
- The runner is built with `fail_on_skipped()`: a step without a definition fails the
  run. There are no no-op stub steps; an unfinished scenario is tagged `@wip`.

## Gates

All run in `just verify`; `just ci` also runs the suite itself.

| Script | Holds |
| --- | --- |
| `verify_bdd_tree_policy.sh` | Allowed and forbidden top-level feature directories. |
| `verify_bdd_ids.sh` | Every scenario has an `@id`; IDs unique, prefixes registered; one file-level `@stage-*`; stage values. |
| `verify_bdd_coverage.sh` | Chains the two above and `verify_bdd_stages.py` (no `@wip` in a finished stage; every stage tag names a `status.md` row); no empty feature directory; every ID in a step comment is an executable `@id`; every step's ID list names each scenario that reaches it, through a Background or an Outline's `Examples` rows included; every feature step matches a step pattern. |
| `verify_bdd_layers.sh` | The black-box boundary, over the whole BDD crate except `benches/`. |
| `verify_no_bdd_production_hooks.sh` | No `bdd` feature, `bdd_*` hooks or registry seed reach-in. |
| `verify_test_layers.sh` | No sleeps, manual `postcard` or duplicate helpers and harnesses in tests; sleep markers in crate sources. Chains `verify_duplication.sh`. |
| `verify_duplication.sh` | Clone budget and targeted anti-patterns: operation-begin flows only in `operation_dispatch.rs`, the web UI source fingerprint only in `web_ui_sources_fingerprint.sh`. |

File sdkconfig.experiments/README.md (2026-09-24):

# sdkconfig experiment fragments

Fragments layered over `sdkconfig.p4.defaults` for a bench experiment, so the baseline is
never edited. Scope: the fragments only; the baseline's keys and reasons are in
[`10-build-release-and-tooling.md`](../documentation/architecture/10-build-release-and-tooling.md).

- `esp-idf-sys` reads `ESP_IDF_SDKCONFIG_DEFAULTS` as a `;`-separated list, later files
  overriding earlier ones.
- `.cargo/config.toml` forces that variable, so an exported or inline one does not
  override it; set it through cargo's own config layer:
  `cargo --config 'env.ESP_IDF_SDKCONFIG_DEFAULTS.value="sdkconfig.p4.defaults;sdkconfig.experiments/<fragment>"' fw`.
  `hil flash` always builds the baseline.
- Check the generated `sdkconfig` — the authority, as 10 says — before trusting a run.
- One flip per build; record every configuration, including those that change nothing.

| Fragment | Tests |
| --- | --- |
| `gptimer-isr-cache-safe-off.defaults` | The inverse control for `GPTIMER_ISR_CACHE_SAFE`. It changes behaviour only on the driver-owned interrupt (`DALI2RUST_PHY_ISR_LEVEL=3`) of an image that does not execute from PSRAM. |

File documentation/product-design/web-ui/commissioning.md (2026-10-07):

# Экран: Commissioning в карточке устройства и в консоли

Секция «Commissioning» карточки физического устройства и панель expert-шагов DALI-консоли.

**Границы:** контракт — [`../rest-api/resources/commissioning.md`](../rest-api/resources/commissioning.md)
и `DELETE` устройства в [`../rest-api/resources/physical-devices.md`](../rest-api/resources/physical-devices.md);
результаты — [`../rest-api/resources/operations.md`](../rest-api/resources/operations.md);
карточки — `web/design-system/screens/device-detail.html`, `dali-console.html`.

## Секция «Commissioning» (`#/devices/{sa}`)

Четыре действия. Три первых — операции, взаимоисключающие на адаптере, поэтому один
флаг занятости блокирует всю секцию, пока идёт любая; `409` сервера остаётся
источником истины, а клиентская блокировка лишь не даёт нажать заведомо
отклоняемое.

- **Identify** — одна кнопка, **без выбора длительности**: окно принадлежит прибору
  (контракт, `POST identify`). Подсказка обещает идентификацию, а не мигание.
- **Change address** — выбор нового адреса **только из свободных** (занятый сервер всё
  равно отклонит), флажок «Verify» (включён). При успехе экран переходит на карточку
  нового адреса: старый URL после переноса отвечает `404` по замыслу. Привязку лампы
  UI не трогает — реестр переносит её сам.
- **Replace** — выбор прибора-заменителя среди известных адресов адаптера и флажок
  «metadata and overrides» (включён). Подсказка говорит, что группы и сцены не
  копируются: запись показывает то, что держит новый прибор, а расхождение со строками
  лампы программирует следующий apply.
  Предупреждение: старый прибор должен быть снят или обесточен заранее — пока он
  отвечает, передача отказывает.
- **Forget** — удаление записи в два нажатия (второе подтверждает в течение 3 с).
  Текст называет цену: имя, заметки, override'ы, атрибуты и банки пропадают,
  привязанная лампа остаётся непривязанной. Если прибор ещё отвечает на шине, текст
  предупреждает, что следующий скан создаст его заново пустым; если не отвечает —
  потерять нечего, и тон спокойнее. После удаления экран уходит к списку.

Итоги операций показываются тостами; отказ `verify_*` — заметным сообщением с
подсказкой проверить устройство, а не общим «ошибка».

## Панель «Commissioning steps» (`#/console`)

Сворачиваемая, по умолчанию свёрнута; сервисный тон без янтарного. Выбор шага и
контекстные поля: `scope` для `initialise`, короткий адрес для шагов, которым он
нужен, 24-битный `search_address` (hex или dec). Ответ пишется в журнал консоли в том же
стиле, что и сырые кадры: `success`, обратный кадр, `match`, `answer`.

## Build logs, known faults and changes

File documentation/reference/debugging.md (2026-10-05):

# Debugging on-device crashes (ESP32-P4)

Triage runbook for panics, stack overflows and core dumps on the ESP32-P4
(RISC-V, dual-core). Host-side debugging is ordinary Rust and out of scope.

**Scope:** the crash-evidence pipeline and how to read it. Memory limits live
in [`07-memory-and-cores.md`](../architecture/07-memory-and-cores.md); the
serial channel and flashing live in [`tools/hil/README.md`](../../tools/hil/README.md).

## What the build arms

Set in `sdkconfig.p4.defaults`; keep them on, they are the whole post-mortem:

- `CONFIG_FREERTOS_WATCHPOINT_END_OF_STACK` — a stack overflow hits a
  watchpoint that names the overflowing task.
- `CONFIG_ESP_COREDUMP_ENABLE_TO_UART` + `CONFIG_ESP_COREDUMP_DATA_FORMAT_ELF` —
  on panic the chip prints an ELF core dump as base64 to the UART.
- `CONFIG_ESP_PANIC_HANDLER_IRAM` — the panic handler runs with the flash
  cache off.

Every Rust panic becomes an abort and a core dump: the `riscv32imafc-esp-espidf` target
aborts on panic, and `.cargo/config.toml` builds `std` with `panic_abort`.

## Where the evidence lands

- The persistent HIL serial monitor log, `tools/hil/state/persist/serial.log`
  (the port is reached through the Wiren Board bridge; see the HIL README).
- The ELF to symbolize against is `target/riscv32imafc-esp-espidf/debug/dali2rust`.
  It must come from the **same build** that crashed. The version string
  printed at boot (`0.1.<count>+<sha>`) tells you which commit that was.

## Decode a core dump

```bash
python3 tools/debug/coredump_decode.py --list     # dumps found in the serial log
python3 tools/debug/coredump_decode.py            # decode the most recent one
python3 tools/debug/coredump_decode.py --index 0 --out crash.elf
```

The script prints the crashed task, every task's TCB and PC, and writes the
ELF core. Each line between the `CORE DUMP START/END` markers is an
independent base64 block, and the crashed task's note comes first.

## Read a register dump

For a panic without a usable dump, the register block is enough:

- `MEPC` is the faulting instruction, `RA` the caller, `MCAUSE` the exception
  class, `MTVAL` the offending address or instruction.
- Symbolize with the ESP RISC-V toolchain:
  `riscv32-esp-elf-addr2line -pfiaC -e <elf> <MEPC> <RA>`.
- Disassemble around the PC before forming a theory:
  `riscv32-esp-elf-objdump -d --start-address=<pc-0x40> --stop-address=<pc+0x40> <elf>`.

## Method

- A dump can describe the panic path failing rather than the defect. Read the
  instructions at the reported PC before trusting the signature.
- A stack-overflow watchpoint names the task. The fix is the depth, not a
  bigger stack: every stack is a budget, and an internal one draws on the
  scarce pool
  ([ADR-028](../architecture/decisions/ADR-028-task-stacks-in-psram-on-the-xip-image.md)).
- A dump whose task pointer is stale (a freed and reused TCB) points at
  whatever took its place. Check that the handle was still alive.

## Log markers

| Marker | Meaning |
| --- | --- |
| `CORE DUMP START` | A dump follows; feed the log to `coredump_decode.py`. |
| `heap: free=… largest_free_block=…@boot min_free_ever=…` | Heartbeat. `largest_free_block` is sampled at boot only; watch `min_free_ever`. |
| `internal: free=… largest=… min_ever=…` | Internal-SRAM heartbeat, the pool that runs out first. |
| `task stack hwm` | Per-task stack census, gated by `tools/hil/stack_budget.txt`. |
| `alloc-failure probe armed` / `alloc failures: count=…` | Allocation-failure hook. Any `alloc failures` line is a signal; `last_caps` says which pool refused. |
| `HTTP slow/failed` | Per-URI timing and heap diagnostics for slow or failed responses. |
| `registry flush: slow` | A persistence flush exceeded its budget. |
| `DALI ISR late entries` | The PHY interrupt was entered late (delayed, not lost): each task that held it off, with its count, largest gap, PC and return address. Lost ticks are the `raw deficit` of `DALI sniff timing`. |
| `registry persistence DISABLED` | Built with `DALI2RUST_PERSIST_DISABLE=1`; diagnosis builds only. |
| `heap integrity sweeps armed` / `heap integrity check FAILED` | Built with `DALI2RUST_HEAP_CHECK_S`; on corruption it panics so the dump lands near the event. |

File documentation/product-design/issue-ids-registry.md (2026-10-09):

# Реестр номеров ISSUE

Единственная точка выделения номеров `ISSUE-NN`: одно пространство на дефекты продукта и
находки стенда. Новый номер — максимум таблицы + 1; он занимается здесь до того, как
появится в записи, в коде или в сообщении коммита.

**Границы.** Здесь номер, статус и название; запись — там, куда указывает статус.
Согласованность проверяет `scripts/verify_issue_ids.py`.

Статусы:

- `открыт` — дефект не исправлен; запись в [known-issues.md](known-issues.md).
- `ждёт стенда` — исправлено в коде, приёмки на железе не было; запись в known-issues.md.
- `обход` — обход внешнего ограничения (ESP-IDF, `esp-idf-svc`, тулчейн); запись в known-issues.md.
- `стенд` — открытая находка стенда или прибора; строка в [`tools/hil/STRATEGY.md`](../../tools/hil/STRATEGY.md) §7.
- `закрыт (<коммит или ADR>)` — записи нет нигде, история — в git по ссылке. Хеш из восьми
  знаков — коммит истории до публикации; в этом репозитории его нет.

| Номер | Статус | О чём |
| --- | --- | --- |
| ISSUE-1 | закрыт (ADR-011) | OOM-abort при flush реестра (фрагментация кучи) |
| ISSUE-2 | закрыт (d19372c5) | Отказы attribute-read; молчащая проба давала успех |
| ISSUE-3 | закрыт (d19372c5) | `503 execution_failed` на target-state под контеншном |
| ISSUE-4 | закрыт (d19372c5) | Фантомные короткие адреса в реестре |
| ISSUE-5 | закрыт (ADR-007) | Потолок burst-ёмкости `POST /groups/apply` |
| ISSUE-6 | закрыт (1895d489) | Readback `fade_time_ms` не по таблице IEC |
| ISSUE-7 | закрыт (abf379b3) | Apply «succeeded» при недописанном diff |
| ISSUE-8 | закрыт (14af86fc) | Второе чтение атрибутов отменяет первое (по дизайну) |
| ISSUE-9 | стенд | Сниффер WB чувствителен к бёрстам коммишенинга |
| ISSUE-10 | закрыт (abf379b3, 16ff5c97) | Порча кадров под мультимастером, невидимая передатчику |
| ISSUE-11 | закрыт (ADR-011) | Крэши ESP32-S3 под нагрузкой |
| ISSUE-12 | закрыт (7ca5cf53) | DT8: цвет и CCT не применялись без `ACTIVATE` |
| ISSUE-13 | закрыт (7ca5cf53) | PUT только с цветом обнулял уровень |
| ISSUE-14 | закрыт (7ca5cf53) | Возраст отметок «20 654 дня» без реального времени |
| ISSUE-15 | закрыт (7ca5cf53) | Extended fade time писался, но не читался |
| ISSUE-16 | закрыт (7ca5cf53) | Список ламп показывал сырой тип устройства |
| ISSUE-17 | закрыт (7ca5cf53) | Редактор сцен без полей CCT и RGB |
| ISSUE-18 | закрыт (7ca5cf53) | Фантомное членство в группе из задвоенного байта |
| ISSUE-19 | закрыт (ADR-017) | Цвет «через раз»: последовательности без транзакций |
| ISSUE-20 | закрыт (16ff5c97) | PHY передавал предыдущий кадр вместо очередного |
| ISSUE-21 | закрыт (b4e73094) | Заклинивший Tc-движок CCT-лампы (особенность гира) |
| ISSUE-22 | закрыт (299b6e9a) | Имя control gear не устанавливалось |
| ISSUE-23 | закрыт (54d303f6) | Проба заголовка банка 0 уводила свип за конец банка |
| ISSUE-24 | закрыт (4f8dde15) | Групповой override HCL не срабатывал |
| ISSUE-25 | закрыт (ADR-011, ADR-012) | HTTP-ответы застревали на 10–15 с; одна задача httpd |
| ISSUE-26 | закрыт (ADR-009) | Поллер держал шину дольше confirmation timeout |
| ISSUE-27 | закрыт (7ea699db, 957a2cd0) | Чтение банка коммитило чужие байты; короткий стартовый полубит |
| ISSUE-28 | закрыт (0422c514) | Тесты HCL на P4 наследовали таймзону DUT |
| ISSUE-29 | закрыт (8bfdad20, 7d5abc9a) | WebSocket-кадр с опкодом 3 перезагружал контроллер |
| ISSUE-30 | закрыт (db0b5898) | Фоновое чтение перезаписывало более свежее наблюдение |
| ISSUE-31 | закрыт (ee35fa79) | Отказ инструмента HIL неотличим от отказа продукта |
| ISSUE-32 | закрыт (45fa2e7a) | Частичное наблюдение стирало ненаблюдённый статус |
| ISSUE-33 | закрыт (ADR-013) | Операция оператора держала провод целиком |
| ISSUE-34 | закрыт (7b6b0754) | Чтение атрибутов публиковало ненаблюдённый цвет |
| ISSUE-35 | закрыт (dc62d429) | Список устройств перегружал задачу httpd |
| ISSUE-36 | закрыт (919082d8) | Модель гира: DAPC не коммитил заданный цвет |
| ISSUE-37 | закрыт (e2da39dc) | Чтение без изменений переписывало флеш |
| ISSUE-38 | закрыт (ADR-015) | Display worker читал всю шину ради счётчика OLED |
| ISSUE-39 | открыт | WebSocket-клиент теряет события под нагрузкой REST |
| ISSUE-40 | закрыт (cedf71f8) | Чтение исчезнувшего устройства шло до конца |
| ISSUE-41 | закрыт (77e2fa7e) | Холостые счётчики поллера и сниффера |
| ISSUE-42 | закрыт (76e92160) | Эмулятор отвечал за чужие адреса; оптика по фантомам |
| ISSUE-43 | закрыт (95151723) | Однобайтовые значения цвета читались как двухбайтовые |
| ISSUE-44 | закрыт (ea08e544) | Health-probe не платил за провод |
| ISSUE-45 | закрыт (edf9430e) | Калибровка оптики не была гарантированно свежей |
| ISSUE-46 | закрыт (9c9d955b) | Молчащие фантомы в реестре валили HIL-тесты |
| ISSUE-47 | закрыт (6c833129) | HIL-CAP-03 без непрочитанного отвечающего устройства |
| ISSUE-48 | закрыт (de15e4a9) | Гейт fanout скипал тесты при заклинившем WB |
| ISSUE-49 | закрыт (dc62d429) | Запись реестра собиралась на стеке воркера |
| ISSUE-50 | закрыт (ADR-021) | Терминальный исход скана терялся в очереди событий |
| ISSUE-51 | закрыт (9041f067) | Ревизия волны §17: пять дефектов при зелёных гейтах |
| ISSUE-52 | закрыт (564ec3e4) | Групповой colour-only уходил без активации |
| ISSUE-53 | закрыт (5e85dbd7) | Флот эмулятора ломал предпосылки HIL-тестов |
| ISSUE-54 | закрыт (cd6c30a) | Preflight советует перезапуск вместо `uvc-util -d` |
| ISSUE-55 | стенд | `http_transport`: неопознанный отказ health-пробы |
| ISSUE-56 | закрыт (f9ff2ae8) | Порванная запись слайса губила последнюю копию |
| ISSUE-57 | закрыт (cbc97676) | Кадр петли `mqtt_worker` держал 1152 Б стека |
| ISSUE-58 | закрыт (822ab3cd) | Ревизия кода: девять дефектов при зелёных гейтах |
| ISSUE-59 | закрыт (a92e868f) | Нижняя граница Табл. 20 не проверялась |
| ISSUE-60 | закрыт (be8b6ebd) | Счётчики не доходили до поверхности |
| ISSUE-61 | закрыт (be8b6ebd) | Леджер HIL читал несуществующий ключ |
| ISSUE-62 | закрыт (a9ee4214) | Коммишенинг не спрашивал шину о свободном адресе |
| ISSUE-63 | закрыт (f30cdd1d) | Эмулятор не исполнял `SET SHORT ADDRESS` |
| ISSUE-64 | закрыт (b9b2f447) | `present` у input-устройства не снимался |
| ISSUE-65 | закрыт (ee482a94) | Отказ драйвера DT6 читался только по кнопке |
| ISSUE-66 | закрыт (ee482a94) | MASK в `QUERY ACTUAL LEVEL` как полная яркость |
| ISSUE-67 | ждёт стенда | HA-мост терял события шины |
| ISSUE-68 | закрыт (9646f90e) | Сброшенный стек не освобождал потоки воркеров |
| ISSUE-69 | закрыт (9450f13e) | Потерянный обратный кадр выбрасывал гир из скана |
| ISSUE-70 | закрыт (01e4b7e2) | HA-мост не переобъявлял discovery на новой сессии |
| ISSUE-71 | открыт | Внутренняя SRAM проседает от релиза к релизу |
| ISSUE-72 | закрыт (dad5dd24) | Отказ спавна потока OTA давал перезагрузку |
| ISSUE-73 | закрыт (3bd7febe) | Коммишенинг не выжидал 100 мс после `RANDOMISE` |
| ISSUE-74 | закрыт (2d48c416) | Тик 10 мс при ожиданиях под 1 мс: busy-wait |
| ISSUE-75 | закрыт (2582e6c) | Модель гира не моделирует готовность после `RANDOMISE` |
| ISSUE-76 | закрыт (1fb87b72) | Счётчик потерь WS считал мёртвого клиента отстающим |
| ISSUE-77 | закрыт (e7a7114d) | Состояние ISR PHY могло лечь в PSRAM |
| ISSUE-78 | закрыт (51ab13c8) | Apply политики писал одно устройство |
| ISSUE-79 | закрыт (182906e) | `apply_on_discovery` не читался |
| ISSUE-80 | закрыт (d9652f0b) | Чужая яркость глушила CCT-расписание HCL |
| ISSUE-81 | закрыт (6f938d66) | Нажатие панели Part 103 не доезжало до HA |
| ISSUE-82 | закрыт (29736705) | Клиент репликации не принимал chunked |
| ISSUE-83 | закрыт (c9943f1b) | Зонд арбитража шёл с кадансом провода |
| ISSUE-84 | закрыт (ae48b134) | Адаптерный слайс уходил в URL двумя сегментами |
| ISSUE-85 | закрыт (518eabb0) | Reload слайса ронял standby по стеку |
| ISSUE-86 | открыт | Порог захвата шины standby не выбран |
| ISSUE-87 | закрыт (d73a2896) | Коллизия 24-битного кадра роняла операцию Part 103 |
| ISSUE-88 | закрыт (dbebe7c5) | Причина перехода роли записывалась неверно |
| ISSUE-89 | закрыт (ADR-018, ADR-025) | Активный P4 не отвечал на зонды во время скана 103 |
| ISSUE-90 | закрыт (86eaf2df) | Снимок кучи с загрузки показывался как живой |
| ISSUE-91 | закрыт (347ee722) | Включение без яркости хранилось как уровень 0 |
| ISSUE-92 | закрыт (182906e) | Цвет, застажённый во время фейда, не применялся |
| ISSUE-93 | закрыт (5ac95194) | Ползунок CCT подменял тёплый конец на 4000 K |
| ISSUE-94 | закрыт (43db15bf) | `fade=` в правилах молча терялся |
| ISSUE-95 | ждёт стенда | `.stop_fade()` домотывал фейд вместо остановки |
| ISSUE-96 | закрыт (5a4b372f) | `hold_hcl=false` не доезжал до провода |
| ISSUE-97 | закрыт (1a1ea56b) | Правила терялись на перезагрузке после сжатия |
| ISSUE-98 | закрыт (7ce87ee8) | `GO TO LAST ACTIVE LEVEL` не доезжал до реестра |
| ISSUE-99 | ждёт стенда | Чужие арк-команды без уровня не доезжали до реестра |
| ISSUE-100 | закрыт (61394f3) | Нет per-rule блока `runtime` в REST правил |
| ISSUE-101 | закрыт (e6788728) | Слайс правил не доезжал до движка standby |
| ISSUE-102 | закрыт (19888798) | Гейт версии `hil flash` сверял с HEAD |
| ISSUE-103 | закрыт (d85d3758) | Отметка живости «из будущего»: ложное зависание |
| ISSUE-104 | закрыт (3b11db5b, 3680d316) | Скан Part 103 на паре рождал фантомные устройства |
| ISSUE-105 | закрыт (6aa0715a) | Перепись стеков читала TCB умершей задачи |
| ISSUE-106 | закрыт (72fe2329) | Settling-порог смешивался со следующим кадром |
| ISSUE-107 | закрыт (72fe2329) | Отмена TX не принадлежала конкретному обмену |
| ISSUE-108 | закрыт (72fe2329) | Разные границы Табл. 20 на входах backward-окна |
| ISSUE-109 | закрыт (5d6fc25) | Лог-вызов мог блокировать DALI-задачу |
| ISSUE-110 | закрыт (72fe2329) | Диагностика сниффера срывала срок ответа |
| ISSUE-111 | закрыт (5d6fc25) | Перепись стеков не мерила transient-задачи безопасно |
| ISSUE-112 | закрыт (72fe2329) | Учёт тиков ISR терял экспозицию |
| ISSUE-113 | закрыт (72fe2329) | Batch публиковался частично и наследовал abort |
| ISSUE-114 | закрыт (dc157e35, d5b651aa) | WS-кадр создавал мьютекс на каждую отправку |
| ISSUE-115 | закрыт (9b364289) | Задержки сниффера и сбросы флеша жили только в логе |
| ISSUE-116 | закрыт (a77604d4) | Чтение атрибутов снимало расписание HCL |
| ISSUE-117 | закрыт (358b407) | Включение без цвета чинит бит Automatic Activation |
| ISSUE-118 | закрыт (e855d30) | Неотвеченная проверка конфиг-записи считается подтверждением |
| ISSUE-119 | закрыт (9e6f09c) | Выключенный адаптер пропускает Part 103, программирование и зонды |
| ISSUE-120 | закрыт (de1246f) | Типы инстансов Part 103 из скана ложатся не на свои номера и не все |
| ISSUE-121 | закрыт (86ad655) | Пароль брокера MQTT на флеше открытым текстом |
| ISSUE-122 | закрыт (1900640) | Чужая запись RGBWAF проецируется как RGB без W/A/F |
| ISSUE-123 | закрыт (9f7caa7) | Удержание линии в окне ответа засчитывается как ответ |
| ISSUE-124 | закрыт (26d48d5) | Два ответа читаются одним чистым байтом: дубликат адреса невидим |
| ISSUE-125 | закрыт (a41b55a) | Ответ target-state устройства несёт `now_ms: 0` |
| ISSUE-126 | закрыт (738e4ab) | Часовой пояс и время нельзя задать из web UI |
| ISSUE-127 | закрыт (15140d0) | Переключение одного правила отменяет ожидания всех правил |
| ISSUE-128 | закрыт (78c6d14) | Модель гира не активирует цвет на `DAPC(MASK)` |
| ISSUE-129 | закрыт (4d81963) | UI называет `RGBWAF CONTROL = 0xC0` «reserved (vendor)» |
| ISSUE-130 | закрыт (a17f641) | Ползунок остаётся на отвергнутом значении |
| ISSUE-131 | обход | ESP-IDF и esp-idf-hal: прерывание PHY |
| ISSUE-132 | обход | ESP-IDF и esp-idf-svc: OTA |
| ISSUE-133 | обход | ESP-IDF spi_flash: запись и чтение флеша |
| ISSUE-134 | обход | ESP-IDF heap_caps: наибольший свободный блок — обход кучи |
| ISSUE-135 | обход | ESP-IDF esp_http_server: стек задачи и апгрейд WebSocket |
| ISSUE-136 | обход | esp-idf-svc и ESP-IDF: разбор кадров WebSocket |
| ISSUE-137 | обход | esp-idf-svc и ESP-IDF: сессии и отправка WebSocket |
| ISSUE-138 | обход | esp-idf-svc и ESP-IDF: клиент MQTT |
| ISSUE-139 | обход | esp-idf-svc и ESP-IDF: Ethernet на ESP32-P4 |
| ISSUE-140 | обход | esp-idf-svc и ESP-IDF: логирование |
| ISSUE-141 | обход | ESP-IDF (SNTP, newlib, mbedTLS): часы и часовой пояс |
| ISSUE-142 | обход | Rust (rustc/LLVM, std): кадры стека в профиле прошивки |
| ISSUE-143 | обход | `std::thread` на ESP-IDF: имя и стек не доходят до FreeRTOS |
| ISSUE-144 | обход | esp-idf-sys и embuild: сборка образа |
| ISSUE-145 | обход | Home Assistant: цвет, сегмент узла discovery, пустое имя |
| ISSUE-146 | обход | tiny_http и tungstenite: WebSocket хостового сервера |
| ISSUE-147 | обход | Хост разработки: cargo, macOS, `libc`, Vite |
| ISSUE-148 | обход | Мост WB и `hil flash`: CH343, RFC2217, esptool, espflash |
| ISSUE-149 | закрыт (4c8090d) | Тесты и пробы водят лампы мимо `HIL_LAMP_SHORTS` |
| ISSUE-150 | закрыт (1ba9495) | Перезагрузки и коммишенинг Part 103 в ярусе default |
| ISSUE-151 | закрыт (59d6f90) | CLI `hil` молча игнорирует неизвестный флаг |
| ISSUE-152 | закрыт (d4861d3) | `--fast-fade` оставляет гирам fade time 0 |
| ISSUE-153 | закрыт (a04ac31) | Восстановление адресов пишет из недоказанного DTR0 |
| ISSUE-154 | закрыт (1c42303) | Мост на WB не замечает пропажу своего порта |
| ISSUE-155 | закрыт (58927ff) | Повторы тулкита мимо леджера; ложный `409` на `PUT /rules` |
| ISSUE-156 | закрыт (5681f89) | Тесты не утверждают заявленного: люки `xfail`, отчёт вместо проверки |
| ISSUE-157 | закрыт (aa310a2) | `HIL validity` не видит смены образа и перезагрузки пира |
| ISSUE-158 | закрыт (fe60ec7) | Скрипты приёмки идут мимо общих механизмов тулкита |
| ISSUE-159 | закрыт (a909d2b) | Глубоко вложенный JSON обходит проверку глубины на части маршрутов |
| ISSUE-160 | закрыт (3d8989b) | Standby после репликации работает со старыми настройками поллера |
| ISSUE-161 | закрыт (077ea27) | Отказ WebSocket по `Origin` не доходит до индикатора web UI |
| ISSUE-162 | закрыт (15140d0) | Выключенные правила снова включаются после восстановления документа |
| ISSUE-163 | закрыт (5feb963) | HA-мост после репликации работает со старыми настройками Home Assistant |
| ISSUE-164 | закрыт (f09d551) | Ячейка применения политики ждала таймаута вместо названного исхода |
| ISSUE-165 | стенд | Панель `test1` не отвечает на запросы яркости индикации Part 332 |
| ISSUE-166 | стенд | Панель Part 103 молчит на скан после записи конфигурации |
| ISSUE-167 | закрыт (456a703, 9b926ab, 5b1126c, fd8c1fe) | Замена прибора сообщает о восстановлении атрибутов, групп и сцен, которых не было |
| ISSUE-168 | закрыт (456a703, 9b926ab) | Замена прибора может оставить две лампы на одном приборе |
| ISSUE-169 | закрыт (456a703, 9b926ab) | Смена адреса и замена не сообщают WebSocket об освобождённом адресе и перепривязанной лампе |
| ISSUE-170 | закрыт (f1efa6a) | `scene(N) recalled` срабатывал на неудавшийся recall |
| ISSUE-171 | ждёт стенда | Топик не в UTF-8 от брокера перезагружал контроллер |
| ISSUE-172 | закрыт (dcdb6e8, ab4dba4, e5bb930, e8e1e08, 80c90f6, dd8b2a3) | Импорт слайса не удаляет записей, принимает битые байты и держит задачу httpd |
| ISSUE-173 | закрыт (418d00a, a7d4f0c, ad798c0) | Повтор кадра после срыва идёт без прелюдии и без доказанного DTR |
| ISSUE-174 | закрыт (1b3848b, f37db76, a88ce8d, 733c2ba, ff609a2, 494e7bf, 5357f7f, 03c84fb, 2d4749a, f18c1cd) | Чтение банка памяти не передоказывает DTR1 и DTR0 в каждом чанке |
| ISSUE-175 | закрыт (9e121d8, 9d5a534, 1709ba1) | Нарушающий кадр в read-back записи 16 бит называется `verify_unanswered` |
| ISSUE-176 | закрыт (fbeaf62, d62d289, 5c3a628, 6de36de) | `SET EVENT FILTER` Part 103 не доказывает DTR1 и DTR2 |
| ISSUE-177 | закрыт (4195f4a, ebc500a, 9078513) | Слияние чужих наблюдений теряет уровень, если за DAPC следует цвет |
| ISSUE-178 | закрыт (ea6e8c8) | Операция, чью команду отвергли раньше её открытия, ждёт TTL |
| ISSUE-179 | закрыт (53fe35d, d55b01d) | Commissioning Part 103 обходит взаимное исключение `409` |
| ISSUE-180 | закрыт (3fc00d2, 340b2f2, 431ec0b, 5a971fb) | Слот приборов старого формата не очищается |
| ISSUE-181 | закрыт (a8c1713, 9b926ab) | Вытеснение прибора сканом оставляет лампу привязанной |
| ISSUE-182 | закрыт (14c6450, d7344a8, 5b1126c, fd8c1fe, ad05c71) | Имена не уникальны, и правило может попасть не в ту цель |
| ISSUE-183 | закрыт (9ea5aeb, c3ac850) | Счётчики адаптера в REST всегда нули |
| ISSUE-184 | закрыт (465cc48, c3ac850) | `/dali/*` и expert-шаги commissioning отвечают `200` на отказ |
| ISSUE-185 | закрыт (312bb3b, b32a940) | Несуществующий адаптер или прибор не получает `404` |
| ISSUE-186 | закрыт (6aa0bda, b32a940, fd0e8a8, 704d1ec) | Часть тела запроса отбрасывается молча, а запрос успешен |
| ISSUE-187 | закрыт (588bb54, 001e16d) | Два быстрых `POST` расписаний HCL получают один id |
| ISSUE-188 | закрыт (c1485c2, d9d0405) | WebSocket сливает срабатывания разных правил |
| ISSUE-189 | закрыт (f4ddcdf, d3e11de, b32a940, fd0e8a8, 704d1ec) | Некоторые маршруты отвечают не тем кодом, что обещает контракт |
| ISSUE-190 | закрыт (5222d13) | Хостовый сервер падает на `%` перед многобайтовым символом |
| ISSUE-191 | закрыт (c6dac6d, d9d0405) | Отказ `target-state` лампы не доходит до дисплея и теряет причину |
| ISSUE-192 | закрыт (89876b5, bda6f21, 125fda4, 240fffe, 51b7915, c4da6da, 3912356, 96a5c85, 1f25716, 9835d35) | Гейты кода и сборки не держат того, что заявляют |
| ISSUE-193 | закрыт (8cd0605, 51ccc55, 9835d35) | Гейты документации пропускают закрытые номера ISSUE и даты |
| ISSUE-194 | открыт | Гир, не сдвигающий `DTR0` на нереализованном 0x01, не отдаёт банки памяти |
| ISSUE-195 | закрыт (80e7aae, 858ff7f) | Ошибка чтения слайса реестра перезаписывает его дефолтами |
| ISSUE-196 | открыт | Слайс, удержанный после ошибки чтения, не перечитывается до перезагрузки |
| ISSUE-197 | закрыт (a7fbf11) | Строка сцены без цвета записывала в DT8-гир чужой цвет |
| ISSUE-198 | закрыт (16cb594) | Принятая с прибора строка сцены не знала цвета сцены, и Apply его стирал |
| ISSUE-199 | закрыт (56535b4) | Сошедшаяся строка сцены после перезагрузки показывалась грязной |
| ISSUE-200 | открыт | Запись уровня включения или аварии записывает в DT8-гир чужой цвет включения или аварии |

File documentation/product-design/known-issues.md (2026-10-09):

# Известные дефекты

Открытые дефекты продукта, исправления, которые ждут приёмки на железе, и обходы ограничений
внешних компонентов: симптом, причина, текущая митигация и критерий закрытия. Отдельно —
поведение, которое выглядит как дефект, но соответствует стандарту или решению продукта.

**Границы.** Номер `ISSUE-NN` выделяется только в [реестре](issue-ids-registry.md); там же
статус каждого номера и ссылка на коммит или ADR закрытого. Закрытая запись отсюда удаляется,
её история — в git. Находки стенда и приборов — в
[`tools/hil/STRATEGY.md`](../../tools/hil/STRATEGY.md) §7, архитектурные правила — в
[`documentation/architecture/`](../architecture/README.md).

## Шаблон записи

```markdown
### ISSUE-NN — <наблюдаемый симптом>

- **Статус:** открыт с ГГГГ-ММ-ДД (или «ждёт стенда с ГГГГ-ММ-ДД»).
- **Серьёзность · область:** низкая | средняя | высокая · подсистема.
- **Симптом:** что видит оператор или прибор, 1–3 строки.
- **Причина:** механизм — или «не установлена» и ведущая гипотеза.
- **Что сделано:** текущая митигация.
- **Критерий закрытия:** тест, порог или замер.
- **Следующий шаг:** одно конкретное действие.
```

Запись держится в пределах 1–2 КБ: без хронологии, логов, хешей коммитов и ссылок на строки
кода. При закрытии запись удаляется, а строка реестра получает статус
`закрыт (<коммит или ADR>)`.

## Открытые

### ISSUE-39 — WebSocket-клиент теряет события под нагрузкой REST

- **Статус:** открыт с 2026-08-06; митигирован, корень не устранён.
- **Серьёзность · область:** средняя · WebSocket / HTTP.
- **Симптом:** при параллельных REST-запросах подписанный клиент получает `DropNotice` и
  перечитывает экраны: часть событий выбрасывается в его очереди на 32 кадра
  (`websocket.events_dropped_total` растёт).
- **Причина:** отправка WS-кадра — работа в очереди единственной задачи `esp_http_server`.
  Пока задача отдаёт REST-ответы, поток `ws-client` ждёт, и очередь клиента переполняется.
  Инбокс WS-воркера не теряет ничего — потери только в очереди клиента.
- **Что сделано:** воркер получает только объявленные виды событий
  ([ADR-015](../architecture/decisions/ADR-015-routed-event-delivery.md)); всплеск сливается
  по ключу сущности до сериализации (`events_coalesced_total`, слияние не считается
  потерей); список устройств отдаётся лёгким резюме; путь отправки больше не создаёт
  мьютекс на каждый кадр.
- **Критерий закрытия:** один клиент на всех каналах, поток событий от чтения атрибутов всех
  устройств и параллельные REST-запросы в течение 30 с — `events_dropped_total` не растёт.
- **Следующий шаг:** оценить отдельный инстанс `esp_http_server` для WebSocket (свой порт и
  своя задача) против бюджета внутренней SRAM (ISSUE-71): стек задачи на XIP-образе без
  `DALI2RUST_STACKS_INTERNAL=1` — в PSRAM (`task_caps`), иначе во внутренней памяти; её
  берут и собственные выделения `httpd_start`.

### ISSUE-71 — Внутренняя SRAM проседает от релиза к релизу

- **Статус:** открыт с 2026-09-11; пол загрузки и минимум за время работы под гейтами, владельцы
  памяти не найдены.
- **Серьёзность · область:** высокая · память / загрузка.
- **Симптом:** без гейта пол свободной внутренней SRAM после загрузки опускается с каждым
  релизом; около 147 КБ выделенной внутренней памяти не атрибутированы. Отказ на дне немой —
  загрузочная петля без сетевой поверхности
  ([07](../architecture/07-memory-and-cores.md) §The pools).
- **Причина:** установлена частично. Утечки нет. Провалы во время работы дают обновление
  прошивки, клиенты WebSocket, всплески запросов и экспорт слайсов: они держат внутреннюю
  SRAM, пока идут. Непосчитанный остаток — примерно 1 700 мелких блоков: lwIP, `_reent`
  задач, заголовки `multi_heap`, мелкие выделения Rust.
- **Что сделано:** пол по стадиям загрузки заморожен в `tools/hil/boot_heap_budget.txt`
  (движется только вверх, краснит прогон); стек httpd урезан по замеру; вложенные боксы
  записей реестра — в PSRAM; `/api/v1/stats` отдаёт `internal_total_bytes` и
  `internal_allocated_blocks`, снятые на стадиях загрузки, и долю Rust-кучи по месту;
  стеки воркеров и httpd и Rust-объекты от 256 Б на XIP-образе — в PSRAM
  ([ADR-028](../architecture/decisions/ADR-028-task-stacks-in-psram-on-the-xip-image.md));
  минимум за время работы гейтится в конце сессии стенда (`runtime_heap_budget.txt`).
- **Критерий закрытия:** выделенная внутренняя SRAM разнесена по владельцам (задача или
  подсистема) без остатка, гейты пола загрузки и минимума за время работы зелёные два
  релиза подряд.
- **Следующий шаг:** остаток C — `CONFIG_HEAP_TASK_TRACKING` на начисто пересобранном
  ESP-IDF, показания только на стадиях загрузки (обход кучи при живом проводе запрещён).
  Подозреваемые причины падения платы с опцией — C-библиотеки, не пересобранные с ней, и
  ручная FFI-раскладка.

### ISSUE-86 — Порог захвата шины standby не выбран

- **Статус:** открыт с 2026-09-14; механизмы ложных промахов исправлены, остался выбор
  порога.
- **Серьёзность · область:** средняя · отказоустойчивость пары контроллеров.
- **Симптом:** при пороге `takeover_after_missed: 2` (умолчание в коде) одиночные
  неотвеченные зонды арбитража на занятой шине переключали владельца шины без причины:
  свет не менялся, журнал переходов заполнялся флапами. Установка работает с порогом 3.
- **Причина:** не установлена; доля одиночных промахов на занятой шине при пороге 2 не
  измерена.
- **Что сделано:** все читатели лизы — на часах супервизора; ограниченное ожидание
  считается оборотом воркера («занят» не значит «завис», провокация пройдена); лопнувшая
  лиза считается в `arbitration.suppressed` ресурса `/api/v1/redundancy`, а не молчит.
- **Критерий закрытия:** сутки на пороге 3 и сутки на пороге 2 без `peer_silent` у пира,
  пока `worker_stale` и `suppressed` не сдвинулись; по итогу мейнтейнер фиксирует умолчание поправкой к
  [ADR-018](../architecture/decisions/ADR-018-controller-redundancy.md) — порог либо
  немедленный переспрос серией зондов.
- **Следующий шаг:** два суточных прогона; только наблюдение, свет не трогается.

### ISSUE-194 — Гир, не сдвигающий `DTR0` на нереализованном 0x01, не отдаёт банки памяти

- **Статус:** открыт с 2026-10-07.
- **Серьёзность · область:** низкая · DALI / банки памяти.
- **Симптом:** чтение атрибутов с банками памяти отказывает с `memory_bank_pointer_unconfirmed`
  на заголовке банка (0x00–0x02): пресеты `identity`, `profile`, `all` — в банке 0, где 0x01 по
  102 Table 9 не реализована; `power`, `energy`, `diagnostics`, `luminaire_data` — в банках
  202–207, если 0x01 там молчит. Такой гир пока не встречен.
- **Причина:** по 102 §9.10.4 READ сдвигает `DTR0` и на нереализованной ячейке, а такой гир —
  нет. Отставший указатель читатель считает признаком потерянного READ и читает 0x01 снова
  ([09](../architecture/09-dali-protocol-rules.md) §Reading answers); у такого гира отставание
  повторяется, и после двух повторных взводов чтение отказывает.
- **Что сделано:** ничего.
- **Критерий закрытия:** тесты читателя: такой гир отдаёт банк 0 с заполнителем на 0x01, а
  байт-индикатор, чей первый READ потерян, по-прежнему читается повторно.
- **Следующий шаг:** если после повторного READ на 0x01 указатель снова на шаг позади,
  оставлять заполнитель и взводить указатель на 0x02; цена — 0xFF вместо байт-индикатора,
  чей READ потерян дважды.

### ISSUE-196 — Слайс, удержанный после ошибки чтения, не перечитывается до перезагрузки

- **Статус:** открыт с 2026-10-07.
- **Серьёзность · область:** средняя · реестр / персистентность.
- **Симптом:** если при загрузке чтение слайса отказало, `persistence.unread_slices` в
  `/api/v1/diagnostics` не ноль, и до следующей загрузки или перезагрузки после импорта
  изменения этого слайса не сохраняются — на активной плате это может длиться всё время
  работы.
- **Причина:** удержанный слайс перечитывает только гидратация
  ([06](../architecture/06-registry-and-persistence.md) §Persistence), а она идёт при загрузке
  и при перезагрузке после импорта или репликации. Повторное чтение из воркера реестра
  требует стека гидрации, как перезагрузка.
- **Что сделано:** ничего; гейдж и предупреждение сброса показывают состояние.
- **Обход:** перезапустить контроллер.
- **Критерий закрытия:** тест реестра: слайс, чьё чтение отказало при загрузке и затем
  восстановилось, перечитывается без перезапуска, и следующий сброс его пишет.

### ISSUE-200 — Запись уровня включения или аварии записывает в DT8-гир чужой цвет

- **Статус:** открыт с 2026-10-08.
- **Серьёзность · область:** низкая · DALI / DT8, запись атрибутов.
- **Симптом:** запись `power_on_level` или `system_failure_level` гиру DT8, у которого
  заряжен временный цвет, вместе с уровнем меняет цвет, в котором гир загорится после
  возврата питания или при отказе системы. На стенде не наблюдалось: выведено из
  стандарта и кода.
- **Причина:** по 62386-209 §11.2.2 команды 45 и 44 (`STORE THE DTR AS POWER ON LEVEL`,
  `… SYSTEM FAILURE LEVEL`) копируют временный цвет в цвет включения или аварии, а при
  MASK его не меняют (§9.12.4, Table 6). Временный цвет остаётся заряженным после DAPC и
  `GO TO SCENE` при снятом бите автоактивации или после чужого мастера. Запись уровня
  уходит как `DTR0` + `STORE` и временный цвет не учитывает — тот же механизм, что
  уже закрыт для строк сцен без цвета, но у этих двух настроек нет аналога
  `REMOVE FROM SCENE`: сохранить нужно прежний цвет, а не стереть его.
- **Что сделано:** ничего.
- **Критерий закрытия:** тест на модели гира с заряженным временным цветом и сохранённым
  цветом включения: запись уровня включения оставляет цвет включения прежним; то же для
  уровня аварии.
- **Следующий шаг:** перед записью уровня гиру DT8 читать `TEMPORARY COLOUR TYPE`
  (`QUERY COLOUR VALUE`, DTR0 = 208); при не-MASK — прочитать сохранённый цвет
  (`QUERY POWER ON LEVEL` / `QUERY SYSTEM FAILURE LEVEL` копируют его в отчёт) и снова
  зарядить его временным. Не решено: что делать, когда сохранённый цвет — MASK, ведь
  очистить временный цвет нечем — писать MASK-значение того же типа (поведение то же,
  тип в отчёте другой) или отказывать в записи с названной причиной. Модели гира нужны
  цвета включения и аварии.

## Исправлено в коде, ждёт стенда

Приёмка идёт на рабочей установке по правилам
[`STRATEGY.md`](../../tools/hil/STRATEGY.md) §4: пометка «Меняет свет» или «Пишет
конфигурацию гира» значит, что нужна отмашка мейнтейнера.

### ISSUE-67 — HA-мост терял события шины

- **Статус:** ждёт стенда с 2026-09-07.
- **Дефект:** мост читал инбокс раз за проход, а паузы между проходами (парк, редиал,
  повторы `publish_required`) длились секунды — всплеск событий переполнял 64 слота.
- **Изменено:** инбокс читается между публикациями, буфер сливает события по ключу
  проекции, общему с WebSocket
  ([ADR-023](../architecture/decisions/ADR-023-named-subscribers-and-shared-coalescing.md)),
  паузы поглощают входящее.
- **Приёмка:** при подключённом брокере всплеск событий, который мост не успевает разобрать
  сразу, — `receiver_overflow` подписчика HA-моста остаётся 0, `mqtt.bus_coalesced_total`
  растёт; прогон, где не сдвинулся ни один счётчик, неубедителен. `HIL-MQTT-12` объявляет
  лампы эмулированного парка (от 16) в пространстве `hiltest` и шлёт серию групповых команд
  их свободной группе: кадр даёт событие на каждую лампу, и каждое мост публикует. Мост
  разбирает и такой всплеск без отставания — события доставлены, переполнений и слияний
  нет, тест неубедителен: всплеск со скоростью провода мост догоняет, слияние даст только
  пауза моста во время всплеска, а её тест не создаёт. Чтения атрибутов и apply идут по
  одному гиру и тем более не нагоняют мост. На прошивке до исправления подписчика `mqtt_bridge` нет, тест скипается и
  старого дефекта показать не может.

### ISSUE-95 — `.stop_fade()` домотывал фейд вместо остановки

- **Статус:** ждёт стенда с 2026-09-16; проводная половина принята (`HIL-VG-06`), физическую
  без шины тестовых гиров не закрыть, пока эмулированный гир (`dali2rust-gear-model`) не
  исполняет фейд.
- **Дефект:** глагол переотправлял сохранённый уровень — по IEC 62386-102 §9.5.9 это
  останавливает фейд и тут же запускает новый к той же цели; на группе и broadcast эффект
  отбрасывался.
- **Изменено:** отдельная команда `DaliStopFadeCommand` — один кадр `DAPC(MASK)` на любой
  класс адреса, без проекции в реестр.
- **Приёмка:** правило `group(N).stop_fade()` на группе с ненулевым `fadeTime` оставляет
  членов там, где их застала команда; на проводе — один кадр `0xFF` по групповому адресу.
  Групповой кадр доходит до всей группы, поэтому физика идёт только на шине из тестовых
  гиров — `HIL-GRP-10`; провод — `HIL-VG-06` на эмулированных гирах.

### ISSUE-99 — Чужие арк-команды без уровня не доезжали до реестра

- **Статус:** ждёт стенда с 2026-09-16; приёмка невозможна, пока шлюз WB-MDALI не передаёт
  инжектированные кадры ([STRATEGY.md](../../tools/hil/STRATEGY.md) §9.2).
- **Дефект:** транслятор сниффера понимал только DAPC, OFF и GO TO SCENE; `RECALL MAX/MIN
  LEVEL`, четыре шаговые команды и `GO TO LAST ACTIVE LEVEL` чужого мастера уровень в
  реестре не двигали.
- **Изменено:** транслятор публикует глагол, писатель реестра вычисляет уровень по
  IEC 62386-102 §11.3 от хранимого `targetLevel` (без известных min/max — `Unknown`);
  `UP`/`DOWN` считаются отдельно и не проецируются.
- **Приёмка:** `STEP UP` с WB по короткому адресу — `runtime_level` и
  `stats.dali.foreign_verbs_projected_total` растут на 1; контроль — `UP` уровень не двигает
  и увеличивает `foreign_dimming_unprojected_total`. Меняет свет.

### ISSUE-171 — Топик не в UTF-8 от брокера перезагружал контроллер

- **Статус:** ждёт стенда с 2026-10-08.
- **Дефект:** обёртка esp-idf-svc отдавала каждое событие esp-mqtt через
  `EspMqttEvent::payload()`, а та декодировала топик с `unwrap()` раньше обработчика
  моста: сообщение с топиком не в UTF-8 под подпиской моста роняло задачу esp-mqtt.
- **Изменено:** клиент esp-mqtt — без обёртки (ISSUE-138): события читает только
  обработчик моста, топик декодируется с заменой; переподключает только мост.
- **Приёмка:** тестовый брокер на сыром сокете, к которому мост подключён вместо
  Mosquitto (Mosquitto такой топик не пересылает), шлёт PUBLISH с топиком не в UTF-8 под
  командным фильтром — контроллер не перезагружается, сессия жива; затем обрыв брокера —
  мост переподключается сам. Свет не меняется.

## Обходы внешних ограничений

Ограничения компонентов, которые продукт не контролирует, и что он делает в обход: одна
запись со статусом `обход` на компонент, с условием снятия. Правило, которое обход держит, —
в [архитектуре](../architecture/README.md); приборы стенда и доверие к их показаниям —
[STRATEGY.md](../../tools/hil/STRATEGY.md) §2–3.

### ISSUE-131 — ESP-IDF 5.5.3 и esp-idf-hal 0.46: прерывание PHY

- **Ограничение:** (а) gptimer выделяет прерывание только на уровнях 1–3, `esp_intr_alloc`
  не ставит обработчик выше 3, а уровень 3 маскируют критические секции и остановка ядра на
  запись во флеш; (б) порт FreeRTOS не даёт из прерывания прерванную задачу и PC; (в)
  трамплин `TimerDriver` во флеше будит задачу на каждый тик, `cpu::core()` тянет `panic!`.
- **Обход:** (а) тик PHY — своё CPU-прерывание уровня 5, уровень 3 — откат
  ([08](../architecture/08-dali-phy-and-transport.md) §The interrupt); (б) зонд поздних
  тиков читает внутренности порта; (в) колбэк уровня 3 — сырым
  `gptimer_register_event_callbacks`, ядро — из CSR `mhartid`.
- **Условие удаления:** (а) обработчик выше уровня 3 в ESP-IDF; (б) API прерванной задачи;
  (в) исправленный esp-idf-hal или уход пути уровня 3. Каждое обновление ESP-IDF сверяет
  смещения регистров и раскладку кадра прерывания.

### ISSUE-132 — ESP-IDF 5.5.3 и esp-idf-svc 0.52.1: OTA

- **Ограничение:** (а) `read_otadata` (за `esp_ota_get_*_partition`, отметкой образа
  валидным, проверкой в `esp_ota_begin`) читает через кеш без блокировки SPI1 — под XIP чтение
  во время стирания молча вешает оба ядра; (б) `otadata` выше 16 МБ загрузчик игнорирует, а
  обновление из слота выше 16 МБ падает; (в) `EspOtaUpdate` заимствует `EspOta`.
- **Обход:** (а) `flash_gate` ([08](../architecture/08-dali-phy-and-transport.md) §Flash
  does not stall the wire); (б) слоты и `otadata` ниже 16 МБ, запись в исполняемый слот
  отвергается ([10](../architecture/10-build-release-and-tooling.md) §Partitions); (в)
  прямые вызовы `esp_ota_*`.
- **Условие удаления:** (а) ESP-IDF 6.x с блокировкой в чтении; (б) адреса выше 16 МБ в
  загрузчике; (в) владеющий хэндл обновления.

### ISSUE-133 — ESP-IDF 5.5.3 (spi_flash): запись и чтение флеша

- **Ограничение:** (а) без XIP запись выключает кеш и останавливает второе ядро, под XIP
  чтение через отображение раздела не упорядочено со стиранием; (б) auto-suspend разрешён
  четырём чипам GigaDevice (с другим — `assert` при загрузке), и только с ним функции драйвера
  уходят из IRAM; (в) буфер вне DRAM пишется страницей на 32 байта, а чтение в него обходит
  кучу.
- **Обход:** (а, в) образ исполняется из PSRAM, `storage` читается и пишется драйвером
  через свой DRAM-буфер ([08](../architecture/08-dali-phy-and-transport.md) §Flash does not
  stall the wire); (б) auto-suspend выключен, IRAM драйвера учтена в полу SRAM,
  JEDEC-идентификатор флеша печатается при загрузке.
- **Условие удаления:** (а, б) флеш с auto-suspend в списке ESP-IDF и развязка опций; (в)
  драйвер, работающий с PSRAM напрямую.

### ISSUE-134 — ESP-IDF 5.5.3 (heap_caps): наибольший свободный блок — обход кучи

- **Ограничение:** `heap_caps_get_largest_free_block` и `heap_caps_get_info` обходят каждый
  блок под блокировкой аллокатора — миллисекунды ожидания для `malloc` с другого ядра.
- **Обход:** кучу обходят только стадии загрузки
  ([02](../architecture/02-runtime-and-threading.md) §No long spinlock holds while the wire
  is live).
- **Условие удаления:** O(1)-оценка наибольшего блока в ESP-IDF.

### ISSUE-135 — ESP-IDF 5.5.3 (esp_http_server): стек задачи и апгрейд WebSocket

- **Ограничение:** (а) `httpd_start` сам выделяет стек задачи одним блоком по `task_caps`:
  внутренний стек — сплошной блок внутренней SRAM, неудача — `abort` и загрузочная петля
  без сети; (б) при `is_websocket` сервер отвечает `101` до обработчика.
- **Обход:** (а) на XIP-образе стек в PSRAM (`task_caps`); иначе (без XIP или с
  `DALI2RUST_STACKS_INTERNAL=1`) блок под стек резервируется рано в загрузке
  ([07](../architecture/07-memory-and-cores.md) §The httpd stack is a budget); (б) отказ по
  лимиту клиентов и по `Origin` — кадром CLOSE уже после рукопожатия
  ([websocket](rest-api/resources/websocket.md) §Пределы и живость).
- **Условие удаления:** (а) внешний стек сервера; (б) проверка апгрейда до `101`.

### ISSUE-136 — esp-idf-svc 0.52.1 и ESP-IDF 5.5.3: разбор кадров WebSocket

- **Ограничение:** (а) esp-idf-svc выключает `handle_ws_control_frames`, и ESP-IDF съедает
  опкод входящего PONG, оставляя остаток в сокете — дальше кадры разбираются со сдвигом; (б)
  `recv` для кадра длины 0 перечитывает заголовок и съедает следующий кадр; (в)
  `create_frame_type` паникует на опкодах 3–7 — кадр любого клиента перезагружает
  контроллер; (г) с флагом ESP-IDF не отвечает на PING и CLOSE.
- **Обход:** свой обработчик `/api/v1/ws` с флагом и собственным разбором кадров
  ([02](../architecture/02-runtime-and-threading.md) §WebSocket on the HTTP task).
- **Условие удаления:** исправленные флаг, `recv` и `create_frame_type` в esp-idf-svc и
  поглощение PONG в ESP-IDF.

### ISSUE-137 — esp-idf-svc 0.52.1 и ESP-IDF 5.5.3: сессии и отправка WebSocket

- **Ограничение:** (а) сессия опознаётся только номером fd: lwIP переиспользует номера,
  `Closed(fd)` получают только обработчики esp-idf-svc, молча умерший сокет — никто; (б)
  отсоединённый отправитель создаёт `Mutex` и `Condvar` на каждый кадр под глобальной
  критической секцией; (в) `send_wait_timeout` — 5 с без настройки, на единственной задаче
  httpd.
- **Обход:** (а) слот освобождает CLOSE или первая ошибка отправки, строки того же fd
  вычищаются при открытии сессии; (б) слот результата на клиента, кадр через
  `httpd_queue_work` (приёмка — `HIL-WS-07`); (в) пределы отправки
  ([02](../architecture/02-runtime-and-threading.md) §WebSocket on the HTTP task).
- **Условие удаления:** (а) закрытие до своих обработчиков и поколения сессий; (б)
  переиспользование примитивов; (в) настраиваемый `send_wait_timeout`.

### ISSUE-138 — esp-idf-svc 0.52.1 и ESP-IDF 5.5.3: клиент MQTT

- **Ограничение:** (а) `EspMqttConnection::next()` — рандеву: задача esp-mqtt ждёт
  потребителя, и keep-alive зависит от его цикла; (б) `EspMqttEvent::payload()`, через
  который `EspMqttClient` отдаёт каждое событие, паникует на неизвестном id события и на
  топике не в UTF-8; (в) ошибка несёт статический `ESP_FAIL` вместо причины; (г)
  конфигурация клиента строится на стеке вызывающего; (д) обработчик, добавленный к
  клиенту `new_cb`, регистрируется после старта и пропускает ранние события.
- **Обход:** клиент esp-mqtt — через `esp_idf_svc::sys`, без обёртки. Свой обработчик
  регистрируется до `esp_mqtt_client_start`, ведёт состояние связи и без блокировки
  копирует данные и SUBACK в ограниченную очередь; причина ошибки читается из
  `error_handle`; конфигурация собирается в куче; собственное переподключение esp-mqtt
  выключено, переподключает мост.
- **Условие удаления:** в esp-idf-svc — (а) потребитель без рандеву, (б) `payload()` без
  паники, (в) причина в ошибке, (г) конфигурация не на стеке, (д) обработчик, который
  регистрируется до старта.

### ISSUE-139 — esp-idf-svc 0.52.1 и ESP-IDF 5.5.3: Ethernet на ESP32-P4

- **Ограничение:** (а) типизированный `EthDriver` закрыт под EMAC исходного ESP32; (б)
  статистики интерфейса нет, `MIB2_STATS` не включить без смены раскладки `struct netif`.
- **Обход:** (а) EMAC и IP101 поднимаются сырыми вызовами, драйвер и netif живут до конца
  процесса; (б) свой netif-глю считает пакеты, байты, отбросы и подъёмы линка, сам копирует
  MAC в netif и ведёт его по событиям, иначе DHCP не работает.
- **Условие удаления:** (а) путь P4 в esp-idf-svc; (б) статистика в ESP-IDF — штатный
  `esp_eth_new_netif_glue()`.

### ISSUE-140 — esp-idf-svc 0.52.1 и ESP-IDF 5.5.3: логирование

- **Ограничение:** (а) логгер esp-idf-svc пишет в `stdout` мимо `esp_log_write`, хук
  `esp_log_set_vprintf` видит только C; (б) `esp_log_write` берёт блокировку уровней до хука.
- **Обход:** (а) свой фасад `log` пишет в очередь консоли и кольцо логов; (б) частичный: хук и
  фасад не ждут, блокировка C-стороны остаётся.
- **Условие удаления:** (а) логгер через `esp_log_write`; (б) неблокирующий поиск уровня.

### ISSUE-141 — ESP-IDF 5.5.3 (SNTP, newlib, mbedTLS): часы и часовой пояс

- **Ограничение:** (а) статус SNTP «синхронизировано» мимолётен; (б) базы поясов нет, пояс —
  POSIX-строка через `setenv("TZ")`, не потокобезопасный с `localtime_r`; (в) проверка дат
  сертификата требует часов, а до SNTP они в 1970.
- **Обход:** (а) ждать правдоподобного системного времени; (б) API принимает POSIX-строку,
  гонка принята — пояс меняется только при загрузке и явной записи; (в) проверка дат
  выключена ([ADR-024](../architecture/decisions/ADR-024-ota-over-ethernet.md)).
- **Условие удаления:** (а) колбэк синхронизации; (б) база поясов; (в) обновление, ждущее
  синхронизации часов.

### ISSUE-142 — Rust (rustc/LLVM, std), профиль прошивки: кадры стека

- **Ограничение:** (а) конструирование на месте не гарантировано; (б) кадр несёт локальные
  всех встроенных веток, не-generic обёртка между крейтами не встраивается; (в) сортировка
  резервирует стековый буфер до проверки длины — у стабильной около 4 КиБ.
- **Обход:** (а, б) крупные значения выделяются и инициализируются на месте, тяжёлые
  ветки — за `#[inline(never)]` ([07](../architecture/07-memory-and-cores.md) §Building
  large values), конверт строится прямо в вызове публикации; (в) `sort_unstable*` по
  полному ключу, сортировка ключей, битовые маски.
- **Условие удаления:** инициализация на месте в стабильном Rust, std без стекового буфера или
  запас в `tools/hil/stack_budget.txt` — с замером кадров по образу
  (`scripts/measure_stack_frames.py`).

### ISSUE-143 — `std::thread` на ESP-IDF: имя и стек не доходят до FreeRTOS

- **Ограничение:** `Builder::name` задачу не называет — она остаётся `pthread` в дампах и
  переписи стеков, стек — pthread-дефолт.
- **Обход:** все потоки — через помощник BSP
  ([02](../architecture/02-runtime-and-threading.md) §Spawning).
- **Условие удаления:** передача имени потока в задачу в std или esp-idf-svc.

### ISSUE-144 — esp-idf-sys и embuild: сборка образа

- **Ограничение:** (а) путь таблицы разделов считается от сгенерированного CMake-проекта в
  `target/`; (б) embuild не объявляет свои cfg для `check-cfg`; (в) фича
  `embassy-time-driver` требует символа из `embassy-executor`; (г) нулевой SHA приложения в
  образе — `esp-coredump` отказывает, а UART-дамп — построчный base64 с заголовком перед ELF.
- **Обход:** (а) путь на шесть уровней вверх; (б) `build.rs` BSP объявляет cfg; (в) образы
  явно линкуют `embassy-executor`; (г) декодер в `tools/debug` разбирает дамп сам и
  подсказывает, какую проверку `esp-coredump` отключить.
- **Условие удаления:** соответствующие исправления в esp-idf-sys, embuild, esp-idf-svc и
  `esp-coredump`.

### ISSUE-145 — Home Assistant (MQTT discovery): цвет, сегмент узла, пустое имя

- **Ограничение:** (а) режимы цвета кончаются на `rgbww`; (б) топик с символами вне
  `[A-Za-z0-9_-]` в сегменте узла (Home Assistant зовёт его `node_id`) молча
  игнорируется; (в) пустое `name` заменяется именем устройства.
- **Обход:** (а) RGBWAF объявляется как `rgb`, W/A/F задаются из поверхностей продукта; (б)
  `controller_id` ограничен набором — `422 invalid_value`; (в) метка с номером.
- **Условие удаления:** соответствующее изменение в Home Assistant.

### ISSUE-146 — tiny_http и tungstenite 0.24: WebSocket хостового сервера

- **Ограничение:** (а) апгрейд `tiny_http` — один объект без `try_clone` и таймаута, дуплекс
  только через мьютекс, который висящий читатель держит вечно; (б) `tungstenite` отвечает на
  PING и CLOSE изнутри `read()` в тот же fd, посреди кадра fan-out.
- **Обход (dev-сервер, BDD):** (а) свой `TcpListener` оставляет апгрейд `TcpStream`,
  остальное проксирует в loopback-`tiny_http`; (б) чтение глотает записи, ответы идут через
  единственного писателя.
- **Условие удаления:** делимый апгрейд в `tiny_http`, отключаемые автоответы в
  `tungstenite`.

### ISSUE-147 — Хост разработки: cargo, macOS, крейт `libc`, Vite

- **Ограничение:** (а) `[alias]` не подставляет триплет хоста, а BDD-зависимости не
  собираются под ESP; (б) cargo не собирает мусор, macOS оставляет `.o` каждой сборки, и
  свежий бинарь из переполненного `deps` минуты ждёт `syspolicyd`; (в) `libc` не экспортирует
  `tzset` и `proc_taskinfo`; (г) dev-прокси Vite не переписывает `Origin` апгрейда
  WebSocket.
- **Обход:** (а, б) [10](../architecture/10-build-release-and-tooling.md) §Toolchain and
  cargo и §justfile; (в) объявления вручную; (г) `rewriteWsOrigin` в `vite dev`.
- **Условие удаления:** соответствующие изменения в cargo, `libc` и Vite.

### ISSUE-148 — Мост WB и `hil flash`: CH343, pyserial RFC2217, esptool, espflash

- **Ограничение:** (а) DTR ведёт IO0, RTS — EN: открытие порта перезагружает контроллер; (б)
  pyserial открывает RFC2217-порт с поднятыми DTR и RTS; (в) esptool не возвращает скорость
  UART; (г) защёлку download-режима по сети не выставить; (д) espflash без сетевого порта; (е)
  `ttyACMn` плавает, платы одинаковые; (ж) venv стенда на Python 3.9, без `tomllib`.
- **Обход:** мост на WB, который возвращает скорость UART после сессии
  ([README](../../tools/hil/README.md#serial-ports)), и `hil flash`
  ([README](../../tools/hil/README.md#flashing)); `[env]` читается построчно
  ([10](../architecture/10-build-release-and-tooling.md) §Toolchain and cargo).
- **Условие удаления:** платы на USB хоста прошивки или без автосброса; (ж) — Python 3.11+.

## Ожидаемое поведение, похожее на дефект

- **`422 unsupported_capability` на target-state устройства или виртуальной лампы** —
  корректный отказ, если режим цвета устройству не присущ (например, `rgb` для DT8 только с
  CCT). Групповая команда (REST и Home Assistant) отказывает только по прочитанным
  возможностям: член, чьи возможности ещё не прочитаны, считается неизвестным, а не
  неспособным.
- **YES на удержание линии в окне ответа.** Активное состояние короче 45 мс — нарушение
  битового тайминга, а в окне ответа это обратный кадр (IEC 62386-101 Table 18 и 19, §8.2.5):
  `COMPARE`, `VERIFY SHORT ADDRESS` и `QUERY CONTROL GEAR PRESENT` читают его как YES, кто бы
  ни держал линию. Скан Part 103 переспрашивает такой адрес; правило —
  [09](../architecture/09-dali-protocol-rules.md) §Reading answers.
- **Два гира на одном коротком адресе отвечают одним чистым байтом.** Ответы ближе 0,4 мс
  друг к другу чаще сливаются в чистый байт, чем в нарушение, иногда в значение, которого
  не посылал ни один из них; признака на ответе, который это отличает, нет — правило и
  замер в [09](../architecture/09-dali-protocol-rules.md) §Reading answers.
- **Коллизии с живым чужим мастером — норма мультимастер-шины.** Каждую детектирует
  передатчик, и кадр повторяется; растут `collisions` и `exchange_retries` в
  `/api/v1/diagnostics`.
- **Extended fade time действует только при `fade time = 0`** (IEC 62386-102); карточка
  устройства помечает его «dormant while fade time ≠ 0».
- **Уровень, прочитанный сразу после команды, бывает промежуточным:** переход идёт с
  `fadeTime` гира, и его мог настроить другой мастер (панель, WB). Чужую конфигурацию гира
  продукт не переписывает.
- **`404` на операцию после перезагрузки контроллера:** операции живут в RAM и не
  персистятся.
- **Чужой `SET SCENE` сбрасывает `applied` строки сцены:** уровень из `DTR0` чужого мастера
  не доказан, поэтому уровень сцены в приборе не прочитан до apply или чтения уровней
  ([scenes](rest-api/resources/scenes.md) §Сцена и матрица).

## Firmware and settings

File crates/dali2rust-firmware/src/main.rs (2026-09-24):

#![allow(unexpected_cfgs, reason = "ESP-IDF target cfg is external")]

#[cfg(target_os = "espidf")]
use embassy_executor as _;

#[cfg(target_os = "espidf")]
#[global_allocator]
static ALLOCATOR: dali2rust_bsp::rust_heap::CountingAllocator =
    dali2rust_bsp::rust_heap::CountingAllocator;

#[cfg(target_os = "espidf")]
fn main() {
    dali2rust_firmware::composition::run();
}

#[cfg(not(target_os = "espidf"))]
fn main() {
    eprintln!(
        "This binary targets ESP-IDF. Build with: cargo build --target riscv32imafc-esp-espidf"
    );
    std::process::exit(1);
}

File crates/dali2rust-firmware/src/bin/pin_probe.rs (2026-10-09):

#![allow(unexpected_cfgs, reason = "ESP-IDF target cfg is external")]

#[cfg(target_os = "espidf")]
use embassy_executor as _;
#[cfg(target_os = "espidf")]
use esp_idf_svc::hal::gpio::{PinDriver, Pull};

#[cfg(target_os = "espidf")]
type ProbePins = Vec<(u8, esp_idf_svc::hal::gpio::PinDriver<'static, esp_idf_svc::hal::gpio::Input>)>;

#[cfg(target_os = "espidf")]
fn sample_window(pins: &ProbePins) -> String {
    let mut last: Vec<bool> = pins.iter().map(|(_, d)| d.is_high()).collect();
    let mut edges = vec![0u32; pins.len()];
    for _ in 0..3000 {
        for (i, (_, d)) in pins.iter().enumerate() {
            let lvl = d.is_high();
            if lvl != last[i] {
                edges[i] += 1;
                last[i] = lvl;
            }
        }
        // sleep-ok: 1 kHz diagnostic edge-sampling cadence (HIL bring-up binary)
        std::thread::sleep(std::time::Duration::from_millis(1));
    }
    let mut report = String::new();
    for (i, (num, d)) in pins.iter().enumerate() {
        report.push_str(&format!(
            "GPIO{num}: edges={} level={} | ",
            edges[i],
            if d.is_high() { "H" } else { "L" }
        ));
    }
    report
}

#[cfg(target_os = "espidf")]
fn main() {
    esp_idf_svc::sys::link_patches();
    esp_idf_svc::log::EspLogger::initialize_default();

    let p = esp_idf_svc::hal::peripherals::Peripherals::take().unwrap();
    let pins: ProbePins = vec![
        (54, PinDriver::input(p.pins.gpio54, Pull::Floating).unwrap()),
        (48, PinDriver::input(p.pins.gpio48, Pull::Floating).unwrap()),
        (47, PinDriver::input(p.pins.gpio47, Pull::Floating).unwrap()),
        (46, PinDriver::input(p.pins.gpio46, Pull::Floating).unwrap()),
        (33, PinDriver::input(p.pins.gpio33, Pull::Floating).unwrap()),
        (32, PinDriver::input(p.pins.gpio32, Pull::Floating).unwrap()),
        (27, PinDriver::input(p.pins.gpio27, Pull::Floating).unwrap()),
        (26, PinDriver::input(p.pins.gpio26, Pull::Floating).unwrap()),
        (23, PinDriver::input(p.pins.gpio23, Pull::Floating).unwrap()),
        (22, PinDriver::input(p.pins.gpio22, Pull::Floating).unwrap()),
        (21, PinDriver::input(p.pins.gpio21, Pull::Floating).unwrap()),
        (20, PinDriver::input(p.pins.gpio20, Pull::Floating).unwrap()),
        (19, PinDriver::input(p.pins.gpio19, Pull::Floating).unwrap()),
        (18, PinDriver::input(p.pins.gpio18, Pull::Floating).unwrap()),
        (17, PinDriver::input(p.pins.gpio17, Pull::Floating).unwrap()),
        (16, PinDriver::input(p.pins.gpio16, Pull::Floating).unwrap()),
        (15, PinDriver::input(p.pins.gpio15, Pull::Floating).unwrap()),
        (14, PinDriver::input(p.pins.gpio14, Pull::Floating).unwrap()),
        (8, PinDriver::input(p.pins.gpio8, Pull::Floating).unwrap()),
        (7, PinDriver::input(p.pins.gpio7, Pull::Floating).unwrap()),
        (6, PinDriver::input(p.pins.gpio6, Pull::Floating).unwrap()),
        (5, PinDriver::input(p.pins.gpio5, Pull::Floating).unwrap()),
        (4, PinDriver::input(p.pins.gpio4, Pull::Floating).unwrap()),
        (3, PinDriver::input(p.pins.gpio3, Pull::Floating).unwrap()),
        (2, PinDriver::input(p.pins.gpio2, Pull::Floating).unwrap()),
    ];

    log::info!("pin_probe: sampling {} candidate pins at ~1 kHz", pins.len());
    loop {
        let report = sample_window(&pins);
        log::info!("pin_probe: {report}");
    }
}

#[cfg(not(target_os = "espidf"))]
fn main() {
    eprintln!(
        "This binary targets ESP-IDF. Build with: cargo build --target riscv32imafc-esp-espidf"
    );
    std::process::exit(1);
}

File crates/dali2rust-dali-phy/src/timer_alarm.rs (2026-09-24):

use crate::isr::PhyIsrCore;

pub const TIMG_TX_CONFIG_STRIDE: usize = 0x24;
pub const TIMG_INT_ENA_OFFSET: usize = 0x70;
pub const TIMG_INT_RAW_OFFSET: usize = 0x74;
pub const TIMG_INT_CLR_OFFSET: usize = 0x7C;
pub const TIMG_T0_MASK: u32 = 0x0000_0001;
pub const TIMG_T1_MASK: u32 = 0x0000_0002;
pub const TIMG_ALARM_EN_MASK: u32 = 0x0000_0400;
pub const TIMG_AUTORELOAD_MASK: u32 = 0x2000_0000;
pub const TIMG_EN_MASK: u32 = 0x8000_0000;

#[derive(Debug, Clone, Copy, PartialEq, Eq)]
pub struct TimerAlarmRegs {
    int_clr: *mut u32,
    config: *mut u32,
    int_mask: u32,
    alarm_en_mask: u32,
}

impl TimerAlarmRegs {
    /// # Safety
    /// `group_base` is a timer group's register base on this chip, and `timer` is 0 or 1.
    pub const unsafe fn for_timg(group_base: usize, timer: u8) -> Self {
        let (stride, int_mask) = if timer == 0 {
            (0, TIMG_T0_MASK)
        } else {
            (TIMG_TX_CONFIG_STRIDE, TIMG_T1_MASK)
        };
        Self {
            int_clr: group_base.wrapping_add(TIMG_INT_CLR_OFFSET) as *mut u32,
            config: group_base.wrapping_add(stride) as *mut u32,
            int_mask,
            alarm_en_mask: TIMG_ALARM_EN_MASK,
        }
    }

    /// # Safety
    /// Both pointers stay valid for volatile reads and writes for as long as the value is used.
    pub const unsafe fn new(
        int_clr: *mut u32,
        config: *mut u32,
        int_mask: u32,
        alarm_en_mask: u32,
    ) -> Self {
        Self {
            int_clr,
            config,
            int_mask,
            alarm_en_mask,
        }
    }

    pub const fn null() -> Self {
        Self {
            int_clr: core::ptr::null_mut(),
            config: core::ptr::null_mut(),
            int_mask: 0,
            alarm_en_mask: 0,
        }
    }

    /// # Safety
    /// Registers from `for_timg` or `new`; nothing else writes `CONFIG` while the interrupt is enabled.
    #[cfg_attr(target_os = "espidf", link_section = ".iram1.dali_phy")]
    pub unsafe fn ack_and_rearm(&self) {
        // SAFETY: the caller's contract; INT_CLR is write-1-to-clear, so only this timer's bit is affected.
        unsafe {
            core::ptr::write_volatile(self.int_clr, self.int_mask);
            let config = core::ptr::read_volatile(self.config);
            core::ptr::write_volatile(self.config, config | self.alarm_en_mask);
        }
    }
}

pub struct PhyAlarmIsr {
    core: *const PhyIsrCore,
    regs: TimerAlarmRegs,
}

// SAFETY: only the interrupt dereferences the pointer; `PhyIsrCore` is shared through atomics and SPSC cells.
unsafe impl Sync for PhyAlarmIsr {}
// SAFETY: as above — moving the value moves two addresses and two masks.
unsafe impl Send for PhyAlarmIsr {}

impl PhyAlarmIsr {
    pub const fn unarmed() -> Self {
        Self {
            core: core::ptr::null(),
            regs: TimerAlarmRegs::null(),
        }
    }

    /// # Safety
    /// `core` outlives the interrupt this value is registered with; `regs` meet `ack_and_rearm`'s contract.
    pub const unsafe fn new(core: *const PhyIsrCore, regs: TimerAlarmRegs) -> Self {
        Self { core, regs }
    }

    /// # Safety
    /// Called only from the alarm interrupt, on a value built by `new`.
    #[cfg_attr(target_os = "espidf", link_section = ".iram1.dali_phy")]
    pub unsafe fn service(&self) {
        // SAFETY: the caller's contract, and `new`'s.
        unsafe {
            self.regs.ack_and_rearm();
            (*self.core).tick();
        }
    }
}

/// # Safety
/// `arg` is the `PhyAlarmIsr` passed to `intr_handler_set`; it is freed only after `esp_intr_free`.
#[cfg_attr(target_os = "espidf", link_section = ".iram1.dali_phy")]
pub unsafe extern "C" fn dali_phy_raw_isr(arg: *mut core::ffi::c_void) {
    // SAFETY: `arg` is the registered `PhyAlarmIsr`, alive until `esp_intr_free`.
    unsafe { (*arg.cast::<PhyAlarmIsr>()).service() };
}

#[cfg(test)]
mod tests {
    use super::*;
    use crate::gpio::RegisterGpio;

    #[test]
    fn for_timg_derives_the_header_addresses() {
        // SAFETY: the value is compared, never dereferenced.
        let t0 = unsafe { TimerAlarmRegs::for_timg(0x500C_2000, 0) };
        // SAFETY: same.
        let expected0 = unsafe {
            TimerAlarmRegs::new(0x500C_207C as *mut u32, 0x500C_2000 as *mut u32, 1, 0x400)
        };
        assert_eq!(t0, expected0);
        // SAFETY: same.
        let t1 = unsafe { TimerAlarmRegs::for_timg(0x500C_2000, 1) };
        // SAFETY: same.
        let expected1 = unsafe {
            TimerAlarmRegs::new(0x500C_207C as *mut u32, 0x500C_2024 as *mut u32, 2, 0x400)
        };
        assert_eq!(t1, expected1);
    }

    #[test]
    fn ack_writes_only_the_clear_mask_and_rearm_sets_only_alarm_en() {
        let mut clr = 0u32;
        let mut config = TIMG_EN_MASK | 0x4000_0000 | TIMG_AUTORELOAD_MASK;
        // SAFETY: two live locals.
        let regs =
            unsafe { TimerAlarmRegs::new(&raw mut clr, &raw mut config, 1, TIMG_ALARM_EN_MASK) };
        // SAFETY: same.
        unsafe { regs.ack_and_rearm() };
        assert_eq!(clr, 1);
        assert_eq!(config, 0xE000_0400);
    }

    #[test]
    fn the_raw_trampoline_acks_rearms_and_ticks_once() {
        let (mut set, mut clr_gpio) = (0u32, 0u32);
        let input = 0b0010u32;
        // SAFETY: scratch "registers" that outlive the core.
        let gpio =
            unsafe { RegisterGpio::new(&raw mut set, &raw mut clr_gpio, &raw const input, 1, 2) };
        let core = PhyIsrCore::new(gpio);
        let (mut int_clr, mut config) = (0u32, 0u32);
        // SAFETY: two live locals.
        let regs = unsafe { TimerAlarmRegs::new(&raw mut int_clr, &raw mut config, 1, 0x400) };
        // SAFETY: `core` outlives `arg`.
        let mut arg = unsafe { PhyAlarmIsr::new(&raw const core, regs) };
        let before = core.wire_tick_counts().0;
        // SAFETY: single-threaded test standing in for the interrupt.
        unsafe { dali_phy_raw_isr((&raw mut arg).cast()) };
        assert_eq!(core.wire_tick_counts().0.wrapping_sub(before), 1);
        assert_eq!(int_clr, 1);
        assert_eq!(config, TIMG_ALARM_EN_MASK);
    }
}

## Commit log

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2026-09-25 Rules: toggles live apart from the compiled set; each rule reports its last firing (ISSUE-127, ISSUE-162, ISSUE-100)
    The enabled bits now sit in one table beside the compiled set, keyed by the
    manifest's name hash, and every compilation takes them from it: a document
    that stops compiling no longer forgets a disabled rule. PATCH of one rule puts
    its bit straight into the engine instead of reloading the set, so other rules'
    pending wait/after and the bits set by rule(...) actions survive it.
    GET /rules?format=json carries a volatile runtime block per rule (count, last
    firing, latency, outcome and reason); a dry run does not move it. The rules
    screen shows it in the UI wave.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
    [mod.rs]
2026-09-25 WebSocket: a refusal names itself in the CLOSE code, and the UI stops on 1008 (ISSUE-161)
    The device closed a foreign Origin without a code and the host adapter
    answered 403 before the handshake, so the browser saw a plain drop and
    reconnected forever. Both now complete the handshake and close with one code
    per reason from the ws runtime (1008 for Origin, 1013 for capacity); the
    client decides only from the close code, and the error-frame route is gone.
    [mod.rs]
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2026-09-25 Mock transport: tell a held send without taking the transport lock
    DaliController holds the transport mutex for a whole exchange, and a
    held send waits inside it. Two tests took that mutex while a send was
    held:
    - a_mid_walk_arrival_waits_out_the_bracket_and_never_truncates polled
    `transport.lock()` for two sent frames. If the poll missed the moment
    between the second frame and the third exchange, it blocked for the
    mock's 60 s hold, then saw three frames after its 2 s deadline (CI run
    36137401374, 60.18 s). A 300 ms stall before the poll reproduces it
    every time: 60.05 s, same panic.
    - The BDD step "the DALI transport unblocks" released the hold through
    the same mutex. SCN-065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
    [main.rs]
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2026-09-26 DALI transport: a held backward window is an answer until 45 ms, then bus power down (ISSUE-123)
    IEC 62386-101 settles ISSUE-123 against its own premise. Tables 18 and 19
    make an active state from 750 us up to 45 ms a bit-timing violation, §8.2.5
    reads a violation in the backward window as a backward frame, and §9.5.2
    has a shared interface send 1,3-2 ms of active state to mean differing
    answers. A hold without edges is therefore an answer, as the transport
    already treated it; only its log line claimed otherwise.
    What the transport missed is footnote b of both tables: an active state
    past 45 ms is bus power down, not a frame. A completed capture whose
    dominant run reaches that bound now e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
    [esp_idf.rs, mod.rs]
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2026-09-26 Application control from the wire: 0xFD is for the unaddressed, and a frame between the halves splits the pair
    Two deviations in how another controller's ENABLE / DISABLE APPLICATION
    CONTROLLER reaches our applicationActive:
    - IEC 62386-103 §9.5.1 addresses 0xFD only to devices without a short
    address, but the translator reported it as a broadcast, so it moved a
    controller that has one. The event now carries a DeviceCommandScope
    (Broadcast, Unaddressed, Short) and the registry, which holds our short
    address, applies Unaddressed only while that address is unset.
    - IEC 62386-101 §9.3 accepts a send-twice pair only with no active state
    between the two frames. A 16-bit frame, a back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
    [mod.rs]
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2026-09-26 Clippy covers every host target, tests included
    `just clippy` checked production targets only, so test code collected 198
    findings no gate saw. It now runs with --all-targets under the same -D set,
    and the findings are fixed rather than allowed:
    - default-then-assign test fixtures become struct literals;
    - needless borrows in projector_flow (clippy's own fix);
    - constant assertions become const blocks, so they fail the build;
    - unsafe test calls carry their SAFETY line where clippy reads it;
    - seven test modules move to the end of their files;
    - 24-bit random-address literals group by byte (0x5C_1D_C2).
    Part 103 frame literals keep digits grouped by frame field
    (0b1_0_00001_0) under an all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
    [mod.rs]
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2026-09-26 BDD: shards over processes, one scenario at a time in each
    The suite ran as one process because in-process concurrency made
    timing-sensitive scenarios flaky. just bdd_shards=N bdd now builds the
    runner once and starts N processes; each reads BDD_SHARD=i/n and runs only
    the feature files of its shard, one scenario at a time. The table is a
    greedy split by scenario count, computed identically in every process,
    and a feature missing from it fails the run instead of being skipped.
    Three four-shard runs passed all 572 scenarios in about 4.5 minutes each,
    against about 15 sequentially. just bdd keeps one process by default, so
    CI is unchanged; bdd-check now runs the suite through just bdd, and th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
    [main.rs]
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2026-09-26 PHY: restart a collided frame after t_RECOVER when the break ends on an idle bus (IEC 62386-101 §9.1.4)
    After the Table 25 break the interrupt waited out 4 ms with the line
    released and never looked at it, and the controller then retried through
    the ordinary settling gate, at least 13,5 ms from the last edge. A
    conforming master that restarts after t_RECOVER therefore won every
    post-collision tie-break on a shared segment.
    Now the interrupt releases the line after the break and checks it on the
    next tick:
    - held: another master's break outlasted ours, and the frame is reported
    as Collision for normal avoidance, as before;
    - idle: the same frame restarts once, its gate lowered to the rest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
    [esp_idf.rs, mod.rs]
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2026-09-26 Stale workarounds: fetch_min/fetch_max, rename without remove, the sntp log target
    Each premise was checked before the workaround went:
    - the stack low-water probe and the allocation probe spelled fetch_min /
    fetch_max as a load-and-store pair for the Xtensa backend. The ESP
    transport already uses fetch_max on the P4 image that runs on the
    bench, so the atomics exist on RISC-V; both probes use them again.
    - the host file stores removed the target before rename for LittleFS. On
    POSIX rename replaces atomically, and the remove opened a window with no
    file at all. A test pins that a write and a commit replace old content.
    - sntp_sync was missing from the project log targets, so the "c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
    [esp_idf.rs]
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2026-09-26 Sniffer: a foreign SET SCENE or REMOVE FROM SCENE pair resets the scene level
    A foreign master programming a scene left the registry showing our last
    readback. The translator now decodes a SET SCENE or REMOVE FROM SCENE pair
    repeated inside the send-twice window with no frame between the halves
    (IEC 62386-101 §9.3) into SceneWriteObserved or SceneRemovalObserved; a single
    or split frame is not a command, and an unaddressed-broadcast pair reaches no
    registry record. The DTR0 level of a foreign master is not proven, so the
    observation carries only the address and the scene.
    The registry forgets the level of every gear the pair reaches, so the matrix
    row reads unread and dirty until an apply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
    [mod.rs]
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2026-09-27 Gear emulator: the console prints its ready line and refuses what it did not do
    The console prints the ready line when it starts listening and again on
    `ready`, so a reader that missed the boot can still learn the build, the
    running slot and its OTA state. A second `reserve` and an `enable` of an
    address no gear holds now answer `refused:`, so a client cannot mistake them
    for success. The RX probe names its unit conversion.
    [main.rs]
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2026-09-28 State: a lamp's level is optional, and an observation's error is a code
    LightSetpoint.level was a u8 whose 0 meant both "level 0" and "nothing
    said"; every consumer had to guess which. It is now Option<u8>, and the one
    rule for what reaches the wire is LightSetpoint::dapc_level(): off is DAPC 0,
    a stated level goes as itself, on with no level (or with 0) is GO TO LAST
    ACTIVE LEVEL. The executor sends exactly that and the registry records the
    same level, so PUT {"level":0} is now DAPC 0 (PD-271).
    - Producers that meant "no level" (colour-only writes, HCL colour points,
    the sniffer's colour, a MASK read) say None; a colour-only setpoint can no
    longer turn into DAPC 0.
    - RuntimeStateChange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
    [mod.rs]
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2026-09-29 HTTP: the httpd configuration is one struct literal, and the stack assert stays
    The fields were assigned one by one after Default::default() on the
    premise that a literal with ..Default::default() lost fields under
    opt-level "z". The configuration is now one literal built in its own
    function; the assert on stack_size stays and proves the premise false
    at boot. The crate no longer allows clippy::field_reassign_with_default:
    the mock transport's constructor was its only other user.
    [esp_idf.rs]
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2026-09-29 Rules: `when mqtt` compiles to a trigger on one exact topic
    The language reserved `when mqtt "topic" [is "payload"]` and refused
    it. It now compiles to a trigger that names one exact topic and,
    optionally, one payload compared byte for byte. `+`, `#`, an empty
    topic and U+0000 are refused at the topic; the topic and the payload
    literal stop at 48 bytes, what a bus frame carries; and a document
    names at most eight distinct topics, refused at the trigger that names
    the ninth. `validate` holds the same limits for any other compiler.
    A broker message is not an input event, so the default cooldown is the
    200 ms of the other trigger classes. Nothing fires the trigger yet.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
    [mod.rs]
2026-09-29 Rules: a broker message event fires the rules on its topic
    MqttRuleMessageEvent carries one message on a rule topic: the topic, at
    most 48 payload bytes and whether the payload was longer. It is appended
    to the events union and declared by the rules worker, whose funnel hands
    it to the engine. A trigger matches its topic exactly; one that names a
    payload matches only an equal, untruncated one. A payload that is
    exactly a signed 32-bit decimal integer is the activation's event value;
    any other leaves it unevaluable.
    The rules store gains a generation that moves whenever the document is
    replaced, hydration and a slice reload at an unchanged revision
    included, for a reader that caches what the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
    [mod.rs]
2026-09-29 MQTT: the broker client unsubscribes and reports the retain flag
    The client port gains `unsubscribe`, and an incoming message says
    whether the broker delivered it retained. The mock keeps the broker's
    live subscriptions per session and can deliver a retained replay.
    On the device the esp-idf-svc event wrapper drops the flag, so the
    client registers its own MQTT_EVENT_DATA handler on the ESP-IDF client
    and delivers every message from there; the wrapper's callback keeps the
    connection and SUBACK events.
    [esp_idf.rs]
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2026-09-29 Rules: hold_hcl false moves a light without standing HCL down
    A rule may now say `hold_hcl false`, on the rule or on one light action,
    and its commit no longer suspends the HCL schedule driving the target.
    The flag rides from the command to the scheduler: DaliSetTargetStateCommand
    and DaliRecallSceneCommand carry `hold_hcl`, the DALI worker copies it into
    DaliTargetStateAppliedEvent and DaliSceneRecalledEvent, the projector into
    every RegistryRuntimeUpdateCommand entry of the fact's expansion, and the
    registry into RuntimeStateChangedEvent as `commit_holds_hcl`, beside
    `commit_source`. The source stays `rules`: HCL now counts a commit as an
    override only when it is foreign and holds.
    Every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
    [mod.rs]
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2026-09-29 MQTT: a refused SUBACK holds `connected` down and is counted
    esp-mqtt reports a SUBACK whose return code is 0x80 as SUBSCRIBED, and
    the esp-idf-svc event wrapper drops the code, so a broker that denied a
    rule topic still read as connected. The client's raw handler now takes
    every esp-mqtt event, reads the SUBACK return codes and tells the link
    whether the subscription was granted or refused; a refusal never counts
    as an acknowledgement, so `connected` stays down, and the running total
    is `subscriptions_refused_total` in the stats `mqtt` block. The mock can
    refuse a SUBACK.
    The same handler keeps delivering data events. It no longer checks the
    topic's UTF-8: esp-idf-svc's own handler runs fi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
    [esp_idf.rs]
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2026-09-29 Rules: a broker message joins the deepest recent rule chain
    An activation a broker message started always began at chain depth 0,
    so no loop through the broker was ever cut by the chain depth. A rule
    that publishes to its own trigger topic relied on the bridge's publish
    limiter, which is a bucket that drops the excess and so ends only a
    round trip shorter than a second. A rule on one of the bridge's own
    state topics that toggles that lamp had nothing but its cooldown.
    A message cannot say what caused it, so its activation now counts as
    caused by the deepest rule effect of the last CHAIN_WINDOW_MS, and an
    `mqtt.publish` effect enters the chain like a light effect. Both loops
    stop at the chai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
    [mod.rs]
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2026-09-29 Rules: a broker message inherits chain depth only from a publish on its topic
    A message used to join the deepest rule effect of the last two seconds, so a
    light-only rule on a busy external topic counted its own earlier messages as
    links and was refused from the fifth message on. The engine now records a
    `mqtt.publish` under its topic and a message takes depth only from that key.
    [mod.rs]
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2026-09-29 MQTT: a SUBACK settles the subscription whose message id it carries
    A refusal used to be a count: the gauge compared acknowledgements with
    subscriptions sent, so a topic the broker refused held `connected` down for
    the rest of the session even after the document dropped it, and nothing named
    the topic. `subscribe` now returns the message id, the link hands SUBACKs
    over by id, and the session tracks each filter as pending, granted or
    refused; the gauge follows the current topics and a refusal is logged with
    its topic.
    [esp_idf.rs, mod.rs]
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2026-09-29 Rules: hcl.enable and hcl.disable switch a schedule through the registry
    A rule names the schedule by its id; HclScheduleEnableCommand, owned by
    the registry worker, moves the stored enabled bit, persists the slice and
    publishes HclScheduleChangedEvent, so the scheduler follows it. A bit
    already stored confirms without an event; an unknown id is refused as
    schedule_not_found. The name resolves at run time, and one longer than a
    schedule id fails its effect instead of being cut to fit.
    [mod.rs]
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2026-09-30 Rules: hcl.hold stands a schedule down for a target without touching the light
    HclOverrideHoldCommand, owned by the HCL scheduler, suspends every
    schedule that runs today and drives the target, in every dimension and
    whether or not it published the target yet; a lamp resolves to the
    targets a commit on that lamp would suspend. The held target is dropped
    from the publish record, so a resume drives it again. The hold confirms
    on the bus, is refused as time_unsynced without a clock, and a hold that
    meets a publishing tick is applied after it, with any clear behind it.
    A hold on a lamp with no binding fails before the bus.
    [mod.rs]
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2026-09-30 Rules: cancel_hold and catch_movement tell an occupancy sensor over one 24-bit frame
    Dali103InstanceActionCommand, owned by the DALI worker, sends Part 303
    CANCEL HOLD TIMER or CATCH MOVEMENT once, on the instance's own device
    and instance address. The worker refuses an instance the registry does
    not know as an occupancy sensor (input_instance_not_occupancy), and the
    disabled-adapter and passive-controller gates refuse it on the
    confirmation like the feedback drive, whose wire class it shares: a
    single operator-facing frame at priority 2. The rules executor checks
    the instance type in its snapshot first, so a rule that names a button
    fails before the bus.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
    [mod.rs]
2026-09-30 MQTT: a message still queued when its session ends is dropped, not replayed
    B2 cleared only the pacer: up to 16 messages waiting in the link's incoming
    queue survived a broker outage or a stand-down and were routed in the next
    session, so rules fired on old messages and a stale Home Assistant "ON"
    executed after reconnecting. The link now stamps each message with the
    session it arrived in and the worker drops one from another session, counting
    a rule message as lost and a command in `commands_dropped_total`.
    [esp_idf.rs]
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2026-09-30 MQTT: the SUBACK queue is checked against the subscriptions a session can have
    A SUBACK beyond the link's 32-deep queue was dropped silently. The queue now
    has to hold two full subscription sets, the three command filters and the
    document's eight trigger topics each: a session's own and those of a document
    change sent before the first were answered. A const assert fails the build
    if the depth or either bound moves apart.
    [mod.rs]
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2026-10-01 Build: a flag knob is 1 or 0, and `cargo flash` names its binary
    `DALI2RUST_DALI_QUERY_CONTENTION_RETRY` and `_QUERY_CONTENT_CONFIRM` were read
    with `parse::<bool>()`, so the `1` that `hil flash` requires and the `0` that
    should switch them off both failed to parse and fell back to the default: the
    knobs could not be turned off. The other flags each had their own reading —
    `ESP_VERBOSE` turned on for any value including `0`, `PERSIST_DISABLE=false`
    disabled persistence. Every flag now goes through one `const fn flag_knob`:
    `1` on, `0` off, unset or empty keeps the default, anything else fails the
    build (checked by const evaluation, so a typo cannot reach a flashed image).
    The `flash` alia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
    [esp_idf.rs, mod.rs]
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2026-10-01 Operations: the requester opens an apply operation and only the orchestrator's signal closes it
    An apply answered 202 with an operation id the orchestrator opened only when
    its run started: an execute refused at delivery or lost in a full inbox left
    an id that answered 404 forever. The tracker also closed an apply on a second
    route, when the outcome count reached the expected count, beside the terminal
    signal (golden rule 6, ADR-021).
    - HTTP, a rule's scene(N).apply() and the policy apply armed for discovery
    publish OperationBeginCommand before the execute; an execute refused at
    ingress fails the operation it opened.
    - The rules worker takes the shared correlation allocator, so every ru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
    [mod.rs]
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2026-10-01 Operations, rules, input devices: third review of the code pass
    - A delivery rejection that reaches the tracker before the operation's begin
    is parked and fails the operation when it opens, instead of leaving it
    accepted for its TTL with the 409 gate shut behind it (ISSUE-178).
    - POST /policies/apply refuses with 409 while a policy apply runs; applies
    queue rather than supersede, so a repeated request no longer piles up runs.
    - A rule toggle is confirmed before its banks are written to flash, so the
    httpd task does not wait on the flash.
    - An input event stamped after the rules clock was read ages 0, not 49 days.
    - An extended observed query hears a violation as the standard one does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
    [esp_idf.rs]
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2026-10-01 Registry: a dirty copy in memory no longer overwrites an imported slice before its reload
    An import writes the slice from the httpd task, and the reload reaches the
    registry worker later; in between, the worker's dirty-slice flush wrote its
    stale in-memory copy over the import, the reload read the stale bytes back,
    and the PUT still answered 200. An import now raises a fence on its slice:
    the flush leaves that slice alone (it stays dirty) until a reload completes,
    or at most 30 s.
    [mod.rs]
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2026-10-06 Adapters: drop the counters nothing writes; the dashboard reads stats.dali
    The adapter resource carried commands, timeouts and errors that no code
    ever incremented, and the dashboard showed those zeros as live figures.
    The field leaves the registry row, the domain view and the DTO; a PATCH
    naming it now meets unknown_field. The dashboard's adapter card shows the
    wire's own totals from stats.dali, and HIL-SYS-02 asserts the field is
    gone.
    ISSUE-183
    [mod.rs]
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2026-10-06 HTTP: the API builds the refusal of a body the server could not take
    The host and ESP servers each wrote their own 413 payload_too_large and
    400 incomplete_body JSON, outside dali2rust-api, with a second copy of
    the 64 KiB limit and without the X-Dali2rust-Role header every other
    answer carries. The limit and both refusals now live in the API's
    router (MAX_REQUEST_BODY_BYTES, Router::refuse_body); the servers only
    say which refusal it was and write the response through their normal
    path, so it is stamped with the role like any other.
    ISSUE-189
    [esp_idf.rs, main.rs]
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2026-10-07 Rules: an ambiguous name says so where the document is shown
    Review of the ambiguous-name refusal. A document a rename made ambiguous
    reported a bare rules_names_unresolved; the live diagnostic now carries the
    compile error, so GET /api/v1/rules names the target and its line, and the
    rule runs again once the names part. The editor's by-id hint and its spec
    no longer say the device picks any one of the shared names.
    The tests now prove each half: every kind of named target refuses a shared
    name, an adapter clause picks the target by its typed reference, and a scene
    name resolves on the recall target's adapter, not only on the primary one.
    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
    [mod.rs]
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2026-10-07 Persistence: a device bank that cannot be settled waits, and no flush writes it
    A bank waits when its own read fails, or when it did not load and the
    old whole-adapter slot, which may hold its devices, could not be read.
    Hydration already left such a bank unmarked, but the coarse marks of a
    group or scene read-back, a foreign scene write, a memory-bank commit or
    a scan dirtied it, the flush wrote it empty, and the next boot loaded
    that empty bank as authoritative. A per-adapter withheld mask now keeps
    the flush, and the dirty check, off a waiting bank; the bank keeps its
    dirty bits and is settled by the next boot or reload that can read it.
    While it waits, a lamp bound to one of its addresse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
    [mod.rs]
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2026-10-07 Registry: a slice whose read fails waits instead of being rewritten (ISSUE-195)
    Hydration folded a failed flash read and a failed decode into one outcome
    and marked both for rewrite, so one transient read error of, say, the
    virtual-lamp slice wrote the empty default over every lamp name and
    binding at the next flush. Only the physical-device banks told the two
    apart.
    Every slice now goes through the same split. A slice that reads but does
    not decode is still rewritten with defaults; one whose read fails is never
    marked, is withheld from every flush - its dirty bit stays pending and does
    not count as work - and is settled by the next boot or reload that reads
    it. Each flush logs the slices i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
    [mod.rs]
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

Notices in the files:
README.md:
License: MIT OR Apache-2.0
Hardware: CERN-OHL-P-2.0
